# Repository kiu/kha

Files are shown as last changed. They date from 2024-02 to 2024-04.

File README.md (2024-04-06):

# kha

Overengineered Modular RS-485 Multi-Master 19" Subrack Home Control

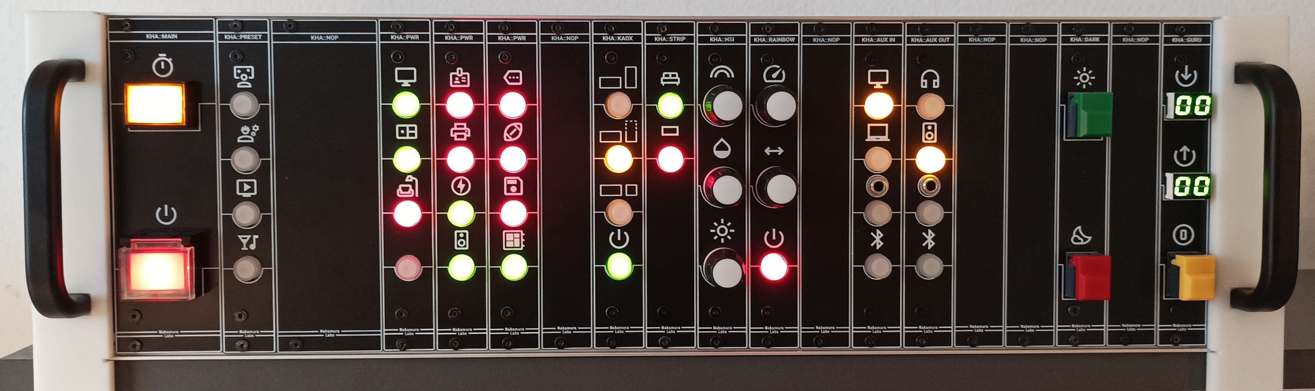
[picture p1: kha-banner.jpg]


## Repository

<sup>Hint: "bgt" is German for [Baugruppenträger](https://de.wikipedia.org/wiki/Baugruppentr%C3%A4ger) translating to subrack assembly</sup>

- [datasheets](datasheets/): Datasheets of used components and rack dimensions / layouts
- [kha-bgt-misc](kha-bgt-misc/): Generic subrack modules
- [kha-bgt-rack](kha-bgt-rack/): 19" rack assembly
- [kha-bgt-subrack](kha-bgt-subrack/): Subrack modules
- [kha-boot.X](kha-boot.X/): Bootloader used by all devices ([main.c](kha-boot.X/main.c))
- [kha-common.X](kha-common.X/): Protocol stack used by all devices ([kha-stack.c](kha-common.X/kha-stack.c) / [kha-stack.h](kha-common.X/kha-stack.h) / [kha-constants.h](kha-common.X/kha-constants.h))
- [kha-nodes](kha-nodes/): Bus nodes
- [superseded](superseded/): Superseded ideas and failed hardware revisions
- [tools](tools/): Helper scripts to e.g. generate userrow data
- [kha-bom-collection.pdf](kha-bom-collection.pdf) / [.ods](kha-bom-collection.ods): Not exactly a Bill-of-Materials rather a collection of most components used
- [kha-protocol.pdf](kha-protocol.pdf) / [.ods](kha-protocol.ods): Protocol stack definitions

## Videos
Two hour deep dive lecture style video on youtube: https://youtu.be/BUSnTUGKZzc

<a href="http://www.youtube.com/watch?feature=player_embedded&v=BUSnTUGKZzc" target="_blank">
	kha on youtube
</a>

## Photos

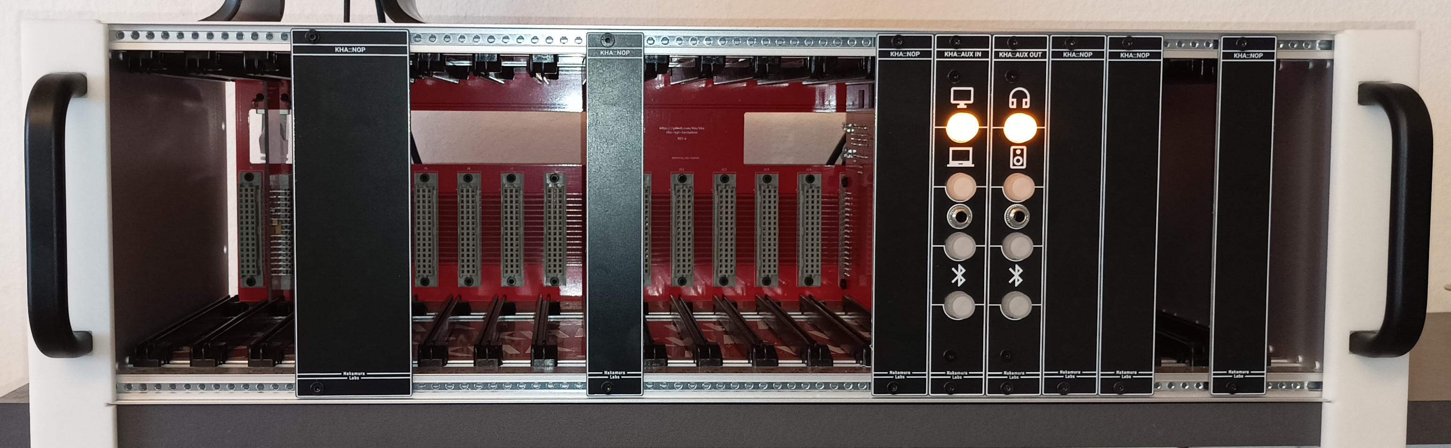
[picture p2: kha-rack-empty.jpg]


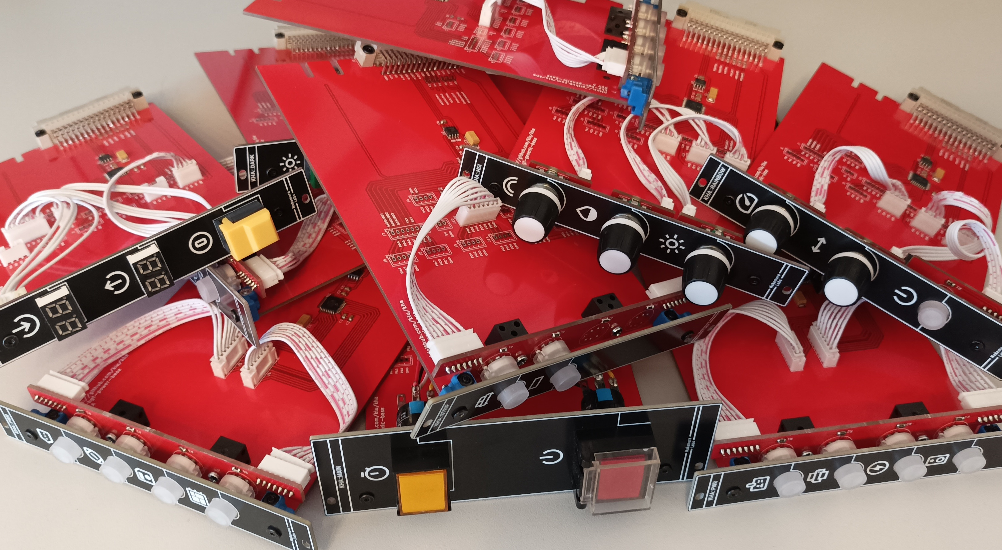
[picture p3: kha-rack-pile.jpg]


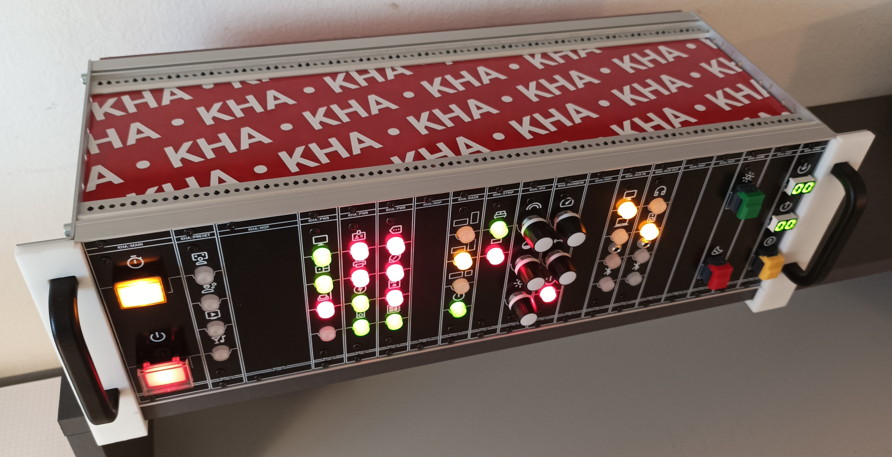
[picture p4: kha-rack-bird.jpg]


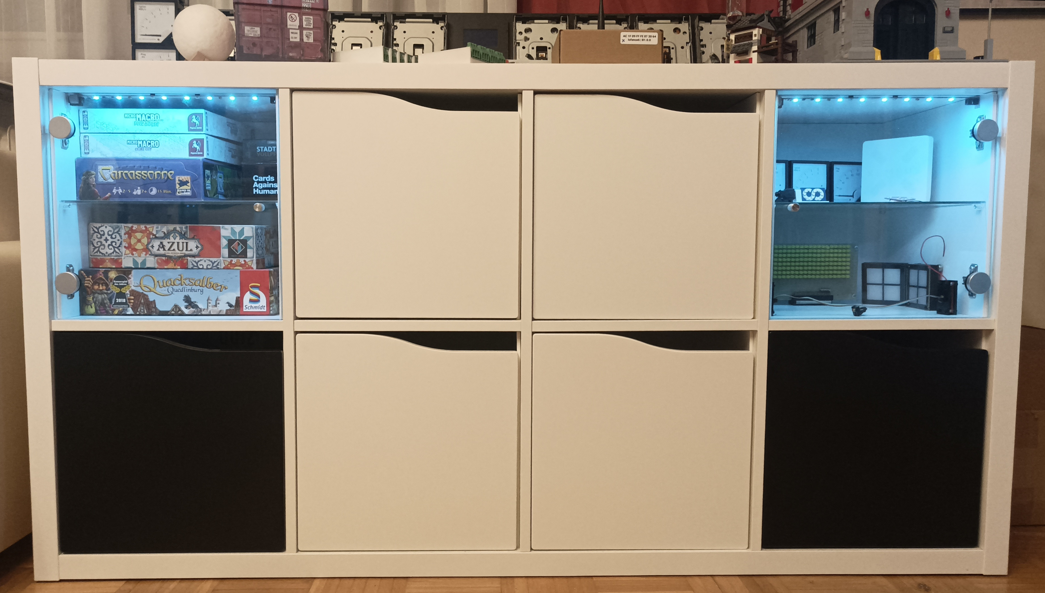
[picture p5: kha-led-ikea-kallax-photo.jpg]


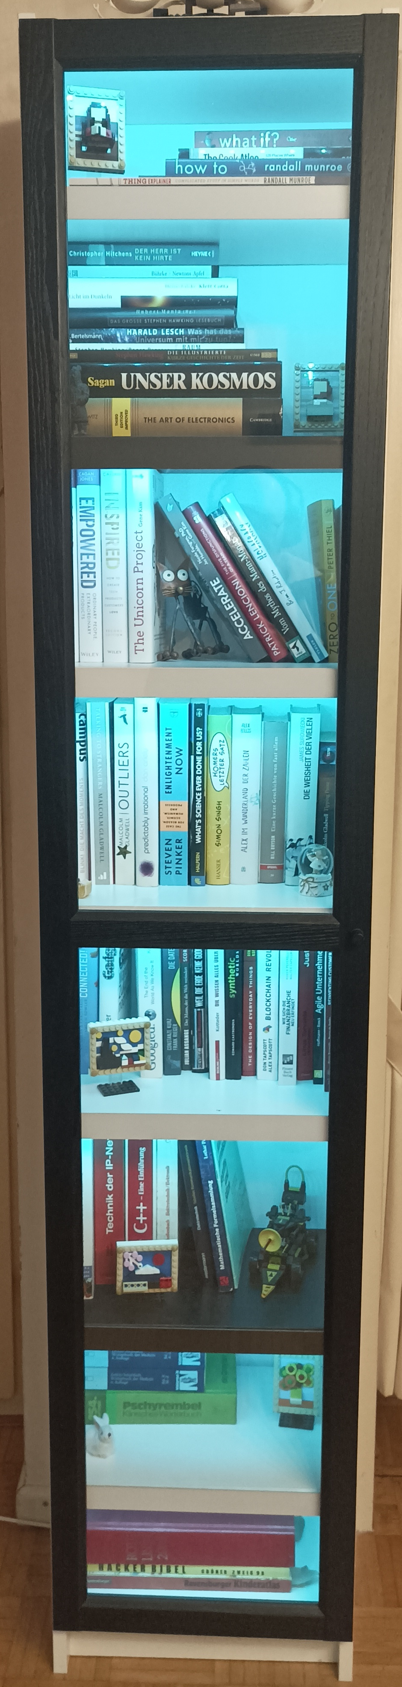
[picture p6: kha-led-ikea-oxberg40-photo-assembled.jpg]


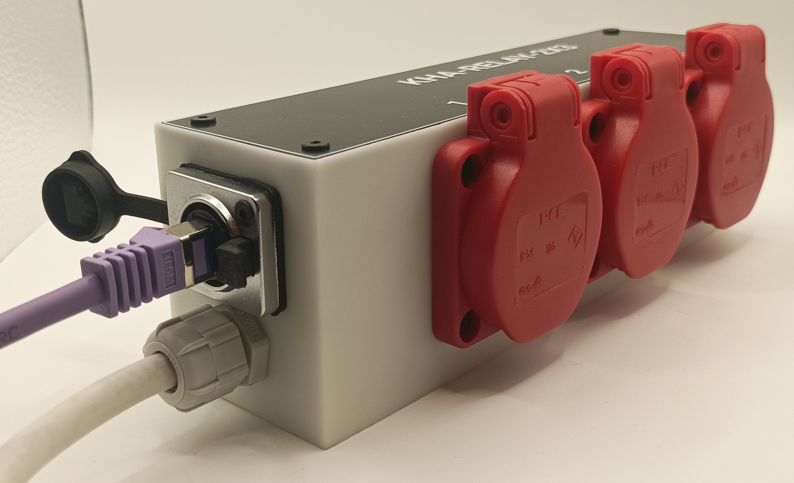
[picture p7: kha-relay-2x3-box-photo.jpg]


## Misc

- All PCBs use [eAVR](https://github.com/kiu/eAVR/) as connector for AVR flashing
- It all started simple with [lightdesk](https://github.com/kiu/lightdesk/)

## Todo

- Node: LED marquee node
- Node: IrDA bridge (bridging the bus through a window)
- Stack: Combine queued TX commands into single burst?
- Stack: Merge similiar queued TX commands into single command?
- Stack: Process TX commands as incoming RX commands?

## Regrets

- Terrible collision detection / avoidance
- Buck converter capacitor generates audible noise

# License

This project is licensed under the Creative Commons Attribution-NonCommercial 3.0 Unported (CC BY-NC 3.0) license.

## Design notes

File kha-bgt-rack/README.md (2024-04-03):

# kha-bgt-rack

19" rack assembly

## Photos



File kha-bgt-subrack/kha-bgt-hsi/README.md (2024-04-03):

# kha-bgt-hsi

Hue Saturation Intensity Module

## Parts

Use [kha-bgt-generic-base](../../kha-bgt-misc/kha-bgt-generic-base/) as base

Use [kha-bgt-generic-rotary-encoder](../../kha-bgt-misc/kha-bgt-generic-rotary-encoder/) for encoders

## Photos

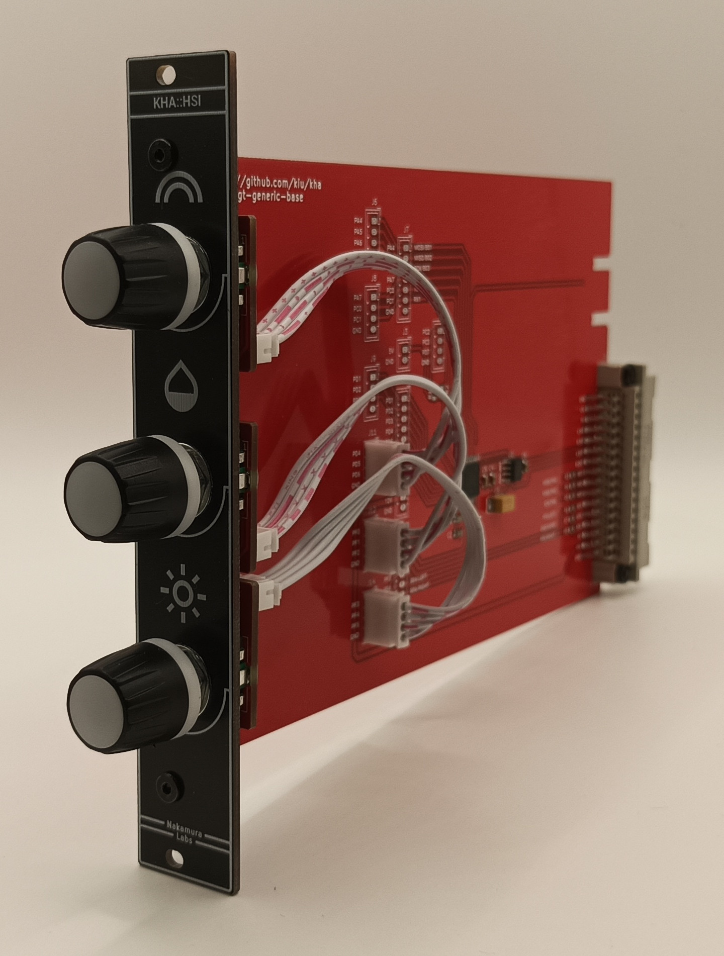
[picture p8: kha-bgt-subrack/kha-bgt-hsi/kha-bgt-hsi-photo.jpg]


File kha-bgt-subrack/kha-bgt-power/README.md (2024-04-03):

# kha-bgt-power

Mains Power Switching Module

## Parts

[kha-bgt-power-base](kha-bgt-power-base/) could be replaced by [kha-bgt-generic-base](../../kha-bgt-misc/kha-bgt-generic-base/)

[kha-bgt-power-sub](kha-bgt-power-sub/) could be replaced by [kha-bgt-generic-4btn-sub](../../kha-bgt-misc/kha-bgt-generic-4btn-sub/)

## Photos

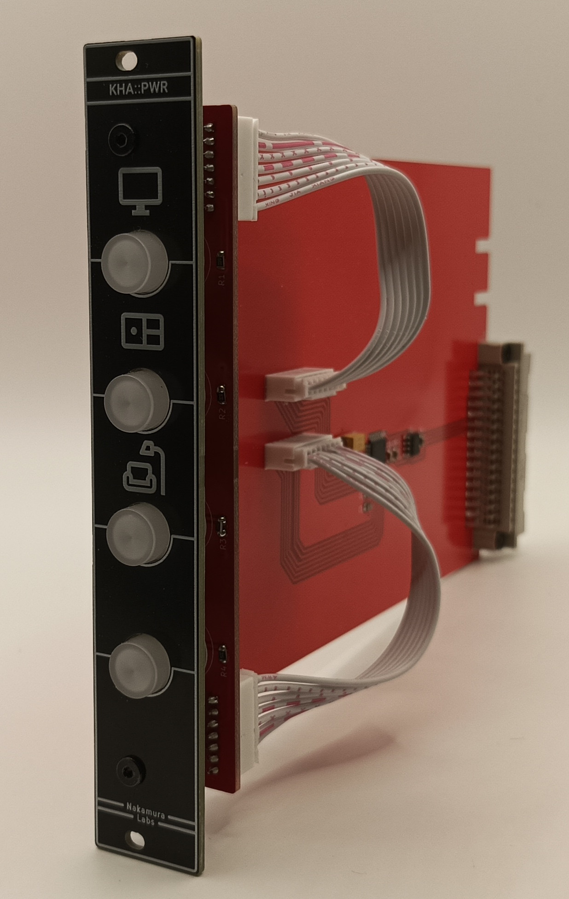
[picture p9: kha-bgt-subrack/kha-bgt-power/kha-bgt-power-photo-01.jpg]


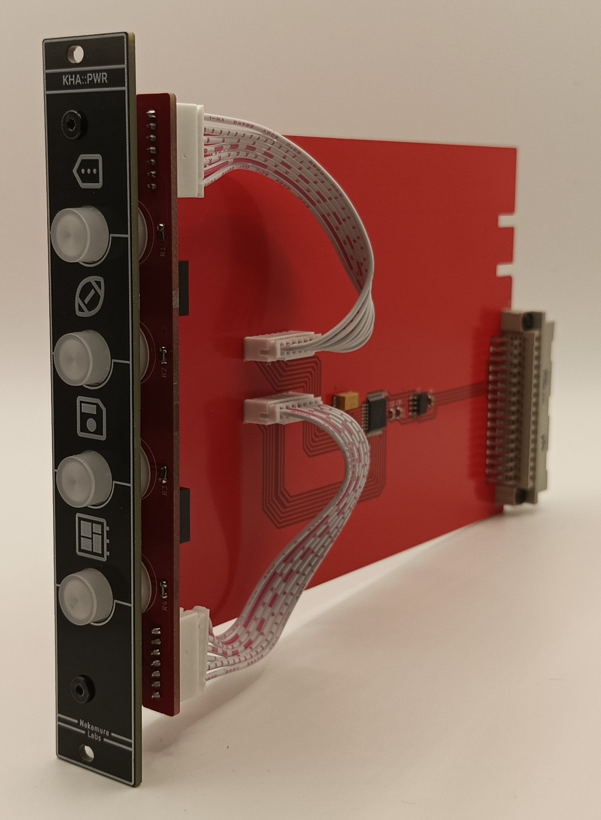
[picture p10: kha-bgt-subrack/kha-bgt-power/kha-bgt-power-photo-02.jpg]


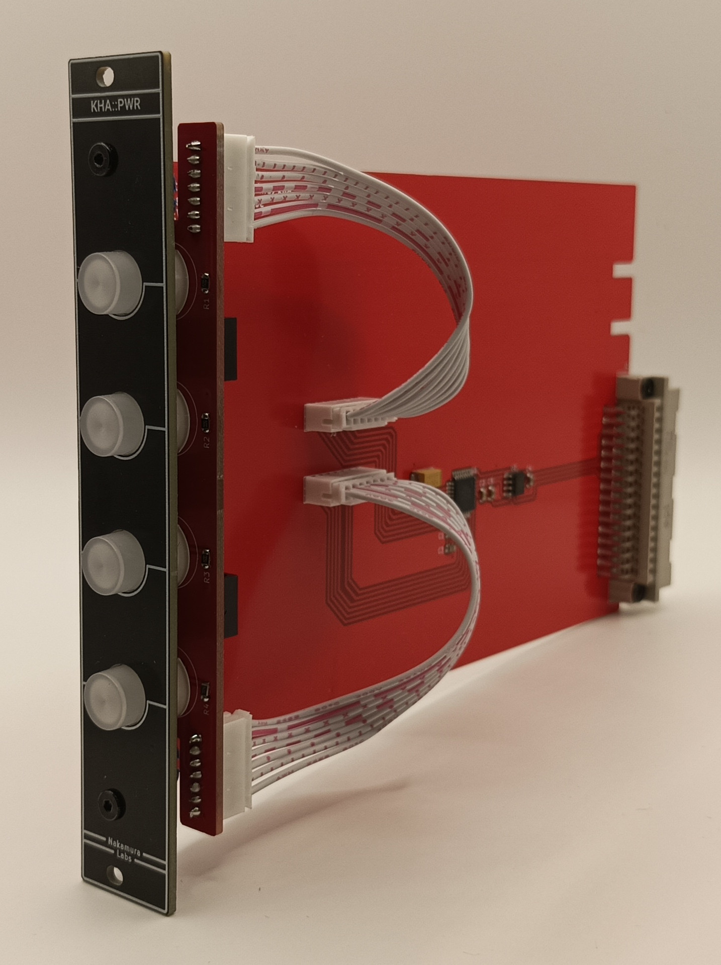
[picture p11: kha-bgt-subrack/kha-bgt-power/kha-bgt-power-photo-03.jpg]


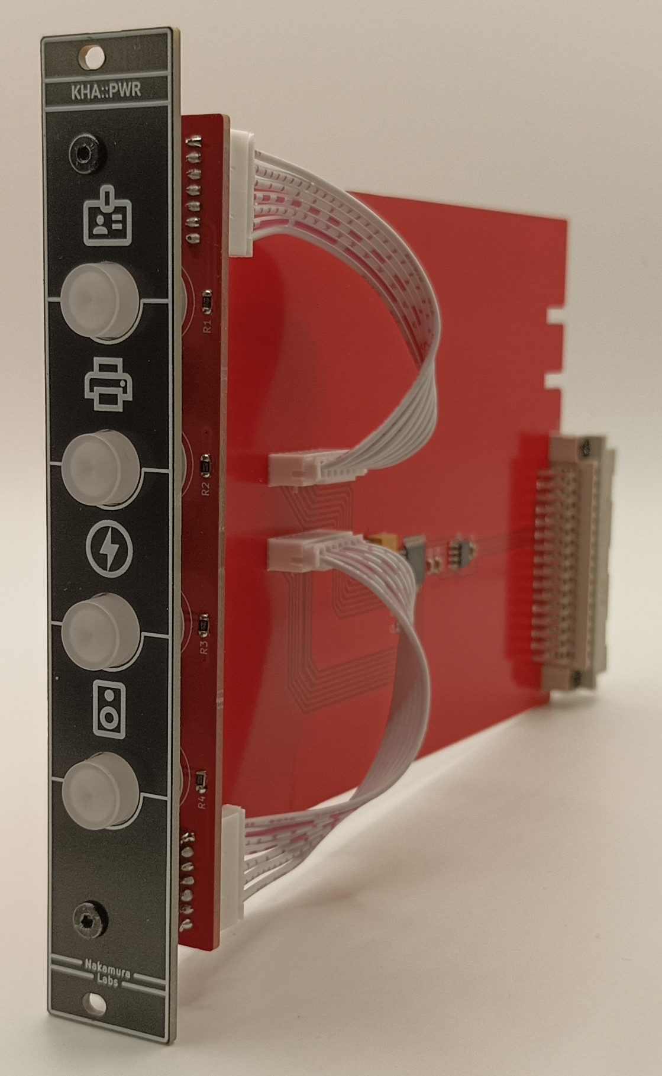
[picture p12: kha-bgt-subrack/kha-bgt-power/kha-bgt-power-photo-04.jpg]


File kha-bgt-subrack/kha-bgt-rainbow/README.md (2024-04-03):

# kha-bgt-rainbow

Rainbow Animation Module

## Parts

Use [kha-bgt-generic-base](../../kha-bgt-misc/kha-bgt-generic-base/) as base

Use [kha-bgt-generic-rotary-encoder](../../kha-bgt-misc/kha-bgt-generic-rotary-encoder/) for encoder

## Photos

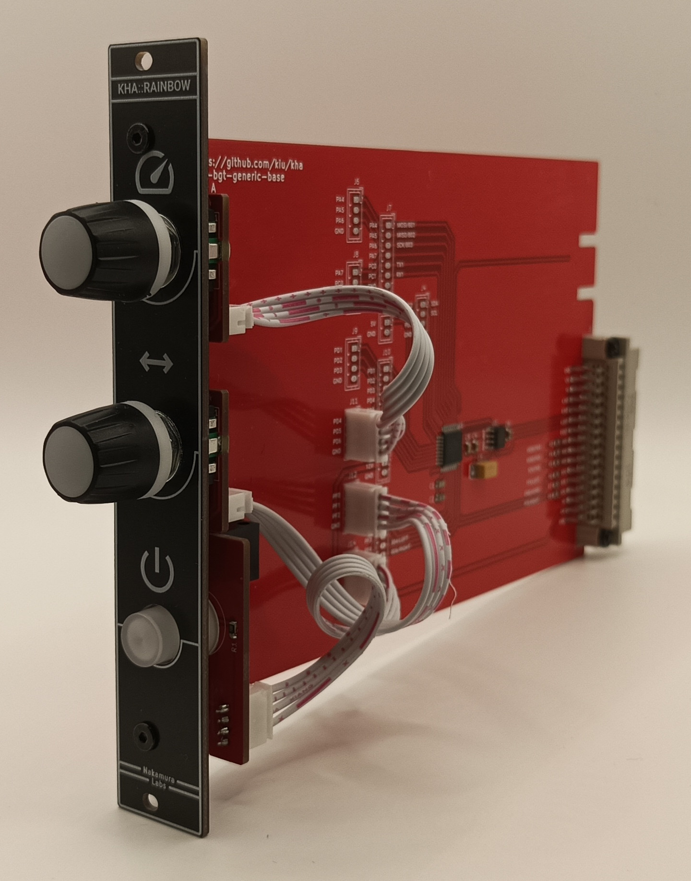
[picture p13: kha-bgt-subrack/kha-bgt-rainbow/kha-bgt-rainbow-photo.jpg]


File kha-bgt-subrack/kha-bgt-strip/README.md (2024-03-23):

# kha-bgt-strip

LED Strip Module

## Parts

Use [kha-bgt-generic-base](../../kha-bgt-misc/kha-bgt-generic-base/) as base

Use [kha-bgt-generic-4btn-sub](../../kha-bgt-misc/kha-bgt-generic-4btn-sub/) as sub

Use [kha-bgt-power](../kha-bgt-power/) as firmware

## Photos

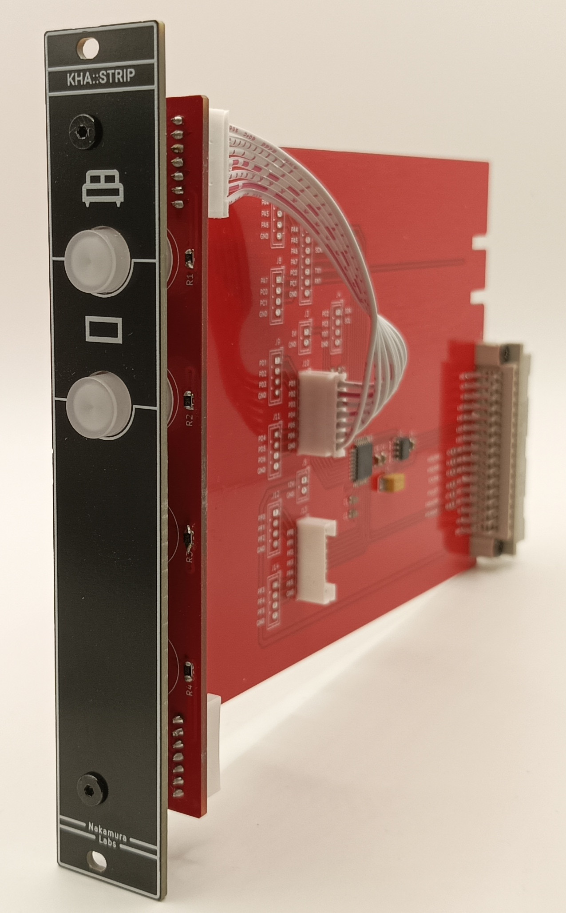
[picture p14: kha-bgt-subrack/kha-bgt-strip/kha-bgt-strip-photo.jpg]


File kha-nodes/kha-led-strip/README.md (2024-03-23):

# kha-led-strip

LED Strip Node

## Photos

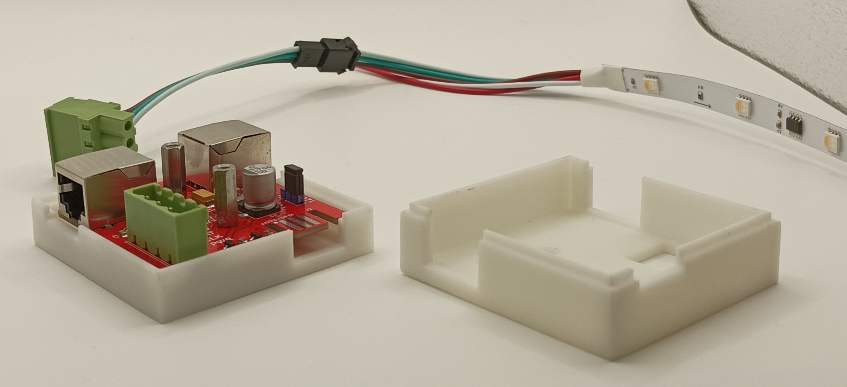
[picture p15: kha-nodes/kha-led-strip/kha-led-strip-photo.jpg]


## Render

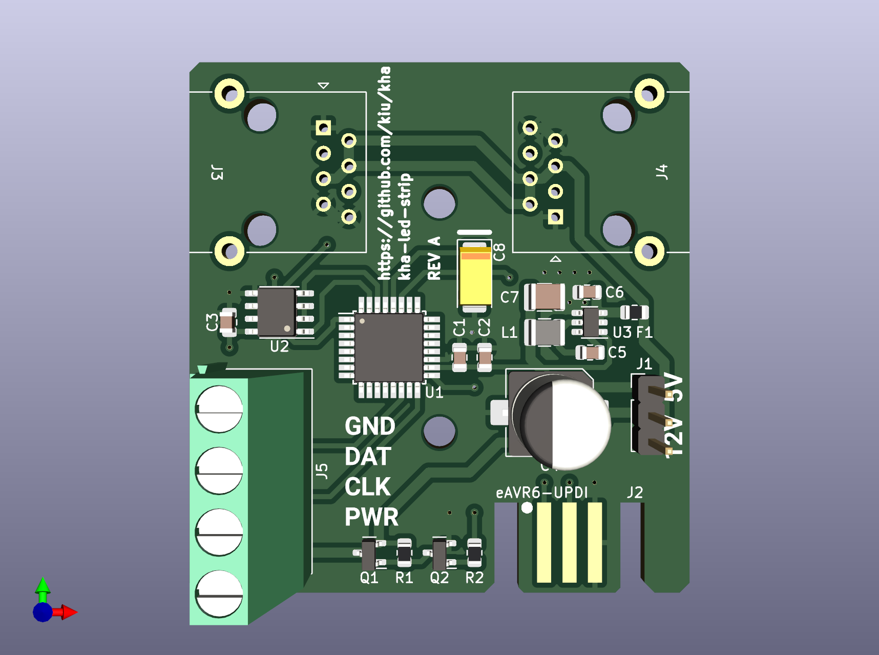
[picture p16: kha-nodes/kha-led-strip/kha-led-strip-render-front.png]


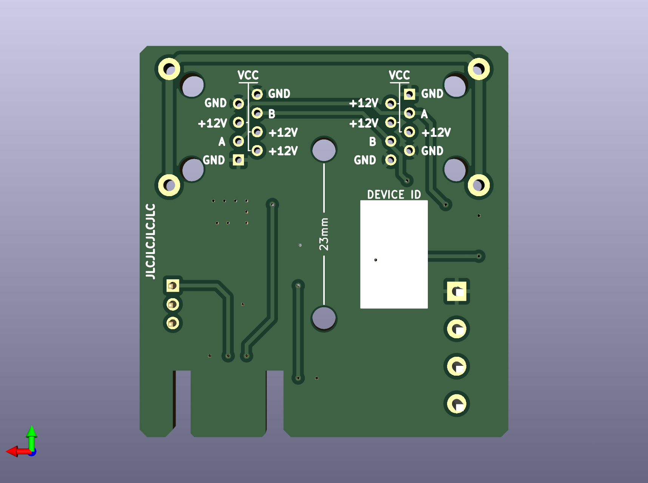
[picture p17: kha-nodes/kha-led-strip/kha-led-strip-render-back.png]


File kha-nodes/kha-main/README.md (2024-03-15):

# kha-main

Remote Shutdown and Poweroff

## Photos

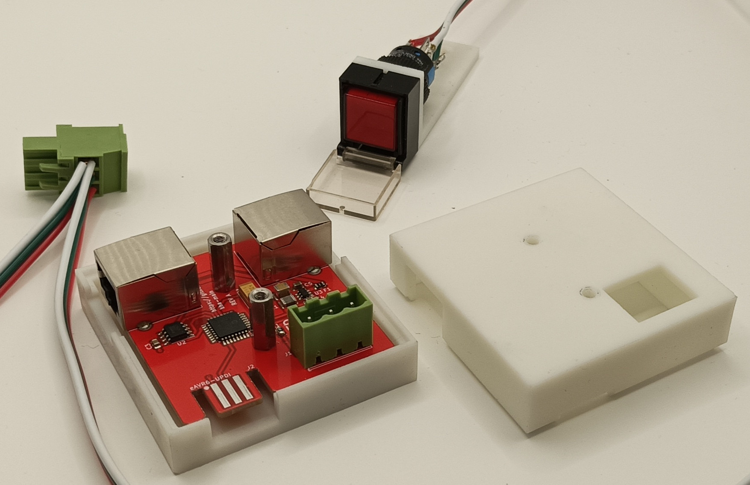
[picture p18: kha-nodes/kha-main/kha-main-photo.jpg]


## Render

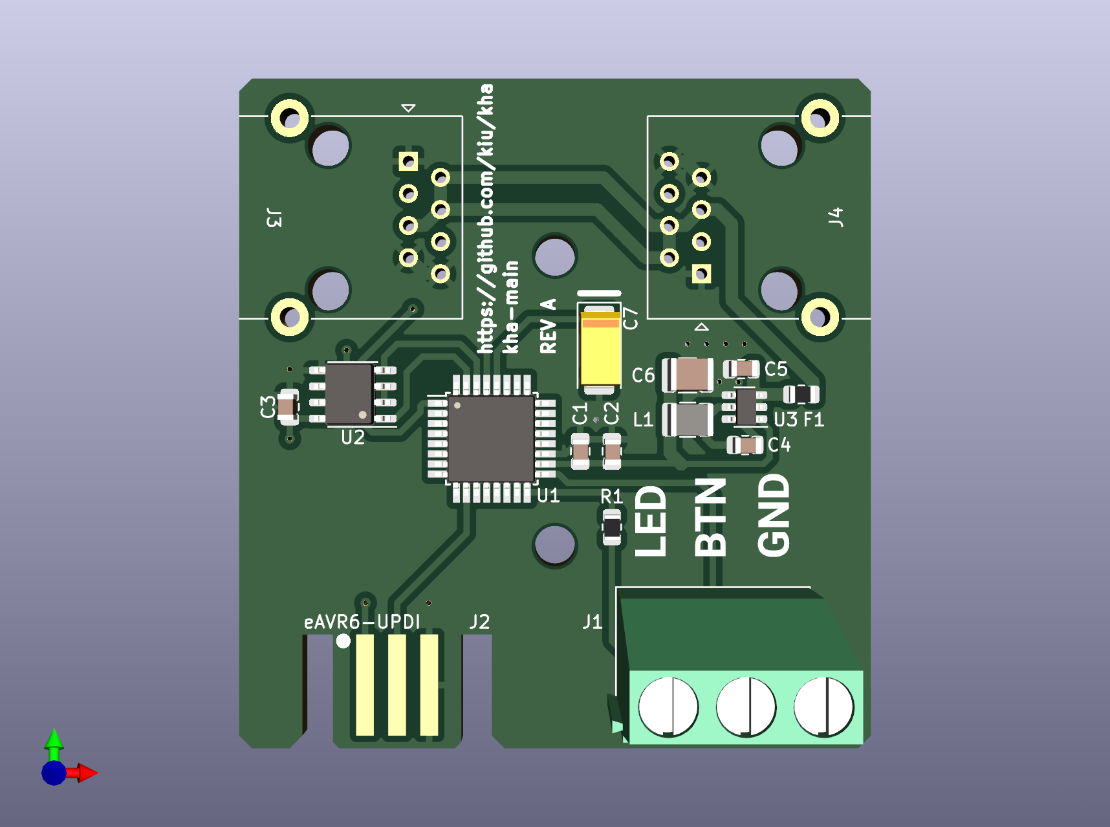
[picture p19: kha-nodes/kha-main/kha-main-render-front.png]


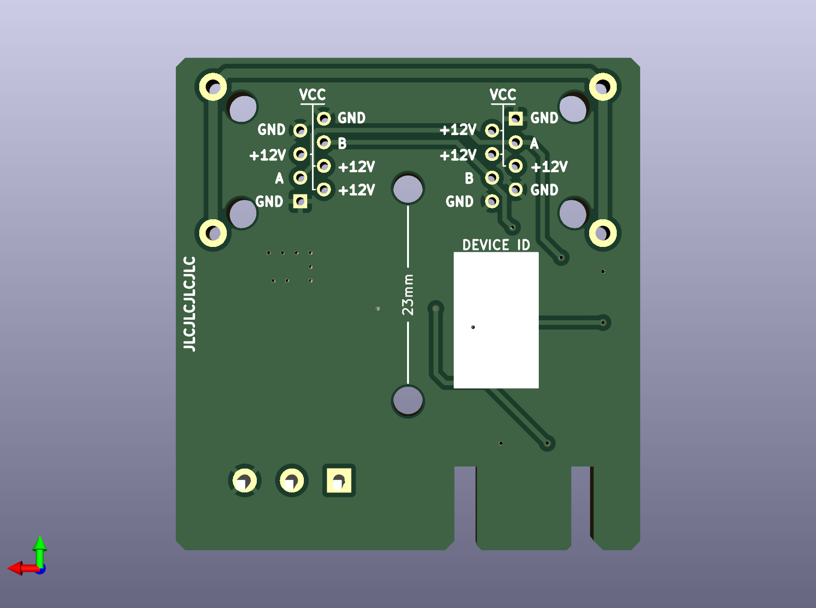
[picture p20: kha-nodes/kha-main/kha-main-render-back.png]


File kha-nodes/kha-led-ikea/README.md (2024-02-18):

# kha-led-ikea-lighting

IKEA LED Panels and Termination

## Photos

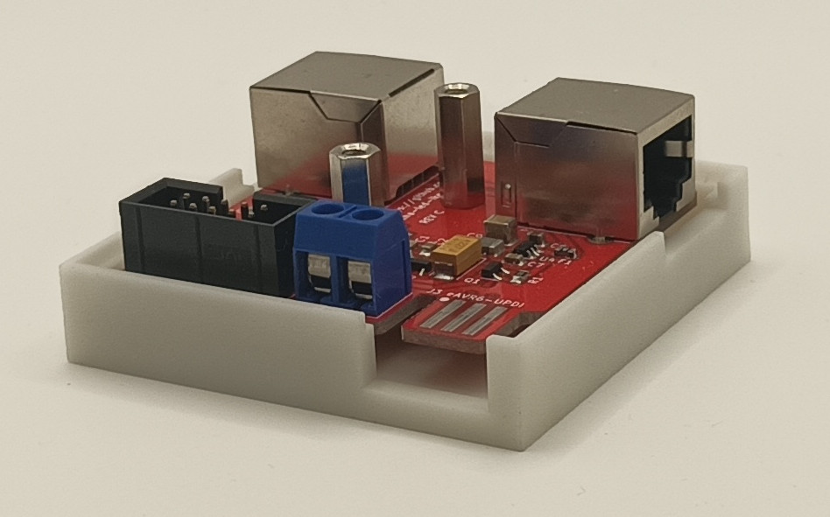
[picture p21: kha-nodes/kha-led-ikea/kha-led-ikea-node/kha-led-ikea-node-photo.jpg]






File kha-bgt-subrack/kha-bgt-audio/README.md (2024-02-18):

# kha-bgt-audio

Audio Switching Module

- 2x TRS (back)
- 1x TRS (front)
- 1x Bluetooth

## Photos

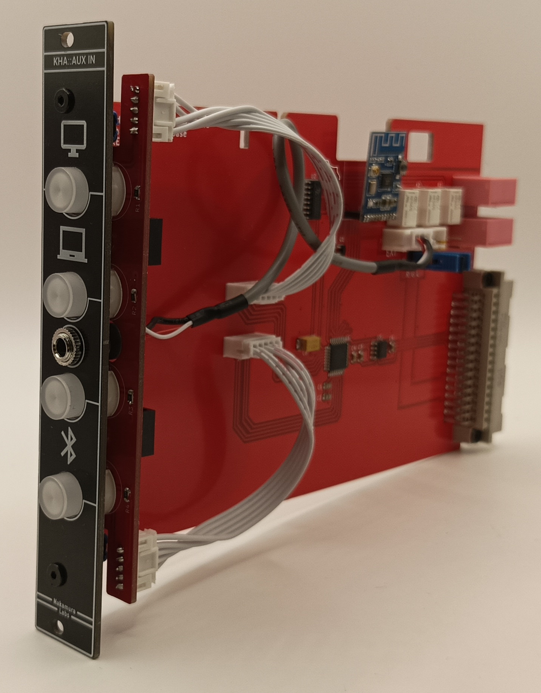
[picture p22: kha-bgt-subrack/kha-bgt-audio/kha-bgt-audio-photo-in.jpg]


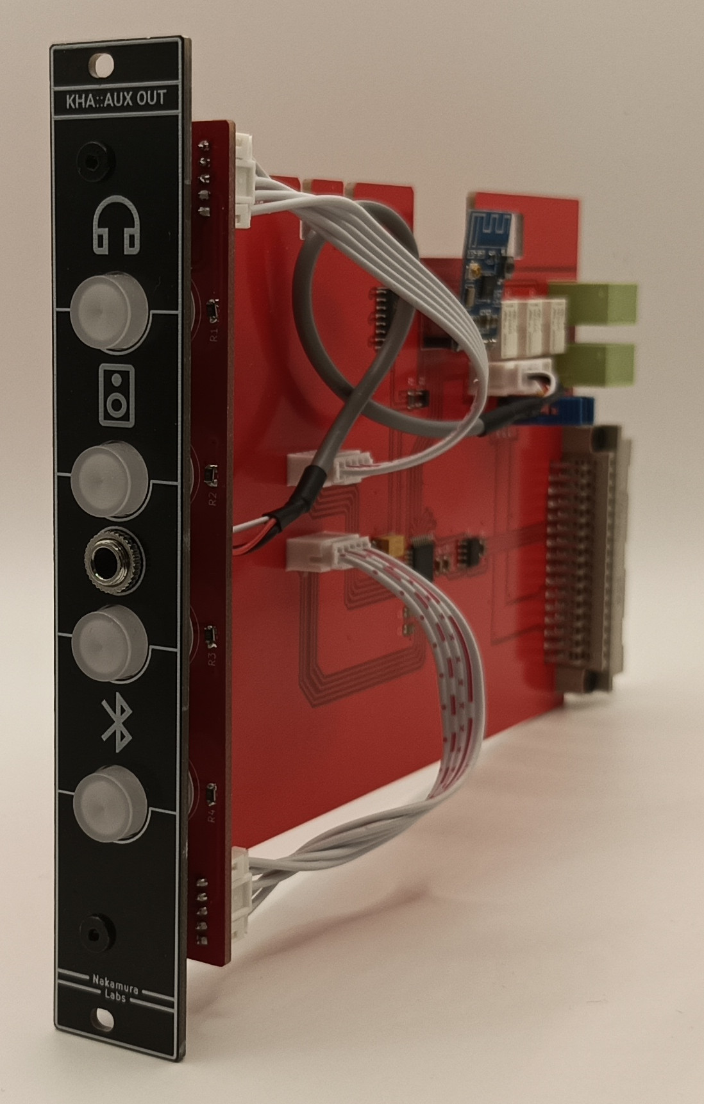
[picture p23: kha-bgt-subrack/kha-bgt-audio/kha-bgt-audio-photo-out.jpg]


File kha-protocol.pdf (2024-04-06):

ADDR

Seite 1

Category | ADDR | Description
Broadcast | FF | Broadcast to All Devices
Broadcast Group | FE | Broadcast to Devices in Group
Broadcast Group | FD | Broadcast to Devices in Group
Broadcast Group | FC | Broadcast to Devices in Group
Broadcast Group | FB | Broadcast to Devices in Group
Broadcast Group | FA | Broadcast to Devices in Group
Broadcast Group | F9 | Broadcast to Devices in Group
Broadcast Group | F8 | Broadcast to Devices in Group
Broadcast Group | F7 | Broadcast to Devices in Group
Broadcast Group | F6 | Broadcast to Devices in Group
Broadcast Group | F5 | Broadcast to Devices in Group
Broadcast Group | F4 | Broadcast to Devices in Group
Broadcast Group | F3 | Broadcast to Devices in Group
Broadcast Group | F2 | Broadcast to Devices in Group
Broadcast Group | F1 | Broadcast to Devices in Group
Broadcast Group Default | F0 | Default broadcast group if device has not been configured
Unicast | EF | Unicast to Device
Unicast | … | Unicast to Device
Unicast | 02 | Unicast to Device
Unicast Default | 01 | Default unicast address if device has not been configured
None | 00 | No recipient

BOARD

Seite 2

Board | Type
All | FF
Kha-bgt-rainbow | A8
Kha-bgt-preset | A7
Kha-bgt-main | A6
Kha-bgt-kaox | A5
Kha-bgt-hsi | A4
Kha-bgt-guru | A3
Kha-bgt-dark | A2
kha-bgt-power | A1
kha-bgt-audio | A0
Kha-led-strip | 07
Kha-remote | 06
Kha-main | 05
kha-relay-2x3-node | 04
kha-gateway-usb | 03
Kha-led-ikea-node | 02
Board Default | 01
None | 00

CMD

Seite 3

Category | CMD | Opt Len Payload | Type | Description
Management | FF | 0 / 2 | - or <1: board type> <1: board rev> | Command | Reboot Device, optionally only matching specific hardware
Management | FE | 0 | - | Reply | Bootloader: Command error
Management | FD | 2 | <1: board type> <1: board rev> | Command | Bootloader: Do not exit
Management | FC | 2 | <1: board type> <1: board rev> | Command | Bootloader: Wipe FLASH
Management | FB | 2 | <1: board type> <1: board rev> | Command | Bootloader: Wipe EEPROM
Management | FA | 67 | <1: board type> <1: board rev> <1: part 0-7> <64: data> | Command | Bootloader: Firmware data
Management | F9 | 3 | <1: board type> <1: board rev> <1: page> | Command | Bootloader: Firmware write
Reserved | F8 | Reserved Reserved | Reserved | Reserved
Reserved | F7 | Reserved Reserved | Reserved | Reserved
Reserved | F6 | Reserved Reserved | Reserved | Reserved
Reserved | F5 | Reserved Reserved | Reserved | Reserved
Reserved | F4 | Reserved Reserved | Reserved | Reserved
Reserved | F3 | Reserved Reserved | Reserved | Reserved
Reserved | F2 | Reserved Reserved | Reserved | Reserved
Management | F1 | 0 | - | Command | TX Enable
Management | F0 | 0 | - | Command | TX Disable
Reserved | EF | Reserved Reserved | Reserved | Reserved
Reserved | EE | Reserved Reserved | Reserved | Reserved
Device | ED | 1 | <1: preset> | Command | Preset
Device | EC | 0 | - | Command | UI Enable
Device | EB | 0 | - | Command | UI Disable
Device | EA | 0 | - | Command | Debug Enable
Device | E9 | 0 | - | Command | Debug Disable
Device | E8 | 1-MAX | <data> | Broadcast | Debug Message
Device | E7 | 0 | - | Command | Stats Clear
Device | E6 | 9 | <9: stats> | Reply | Stats Response
Device | E5 | 0 | - | Command | Stats Request
Device | E4 | 0 | - | Reply | Pong
Device | E3 | 0 | - | Command | Ping
Device | E2 | 20 | <1: board type> <1: board rev> <1: device group> <1: 0=boot, 1=app> <4: boot version> <4: boot crc> <4: app version> <4:app crc> | Broadcast | Up
Device | E1 | 20 | <1: board type> <1: board rev> <1: device group> <1: 0=boot, 1=app> <4: boot version> <4: boot crc> <4: app version> <4:app crc> | Reply | Ident Response
Device | E0 | 0 | - | Command | Ident Request
Register | DF | 0 | - | Command | Wipe configuration in memory
Register | DE | 0 | - | Command | Store configuration to EEPROM
Register | DD | 0 | - | Command | Load configuration from EEPROM
Reserved | DC | Reserved Reserved | Reserved | Reserved
Reserved | DB | Reserved Reserved | Reserved | Reserved
Reserved | DA | Reserved Reserved | Reserved | Reserved
Reserved | D9 | Reserved Reserved | Reserved | Reserved
Register | E8 | 1 | <1: addr> | Reply | Write Fail
Register | D7 | 1 | <1: addr> | Reply | Write Success
Register | D6 | 2-MAX | <1: addr> <data> | Command
Register | D5 | 2-MAX | <1: addr> <data> | Command | Write <data> bytes to address <addr>
Reserved | D4 | Reserved Reserved | Reserved | Reserved
Reserved | D3 | Reserved Reserved | Reserved | Reserved
Reserved | D2 | Reserved Reserved | Reserved | Reserved
Register | D1 | 1-MAX | | Reply
Register | D0 | 2 | <1: addr> <1: len> | Command
Reserved | CF | Reserved Reserved | Reserved | Reserved
Reserved | CE | Reserved Reserved | Reserved | Reserved
Reserved | CD | Reserved Reserved | Reserved | Reserved
Reserved | CC | Reserved Reserved | Reserved | Reserved
Reserved | CB | Reserved Reserved | Reserved | Reserved
Reserved | CA | Reserved Reserved | Reserved | Reserved
Reserved | C9 | Reserved Reserved | Reserved | Reserved
Reserved | C8 | Reserved Reserved | Reserved | Reserved
Reserved | C7 | Reserved Reserved | Reserved | Reserved

Write <data> bytes to address <addr>, don’t reply

<1:addr> <data, empty if failed> | Read Reply <data> bytes from address <addr> or empty if failed Read <len> bytes from address <addr>

CMD

Seite 4

Reserved | C6 | Reserved Reserved | Reserved | Reserved
Reserved | C5 | Reserved Reserved | Reserved | Reserved
Reserved | C4 | Reserved Reserved | Reserved | Reserved
Reserved | C3 | Reserved Reserved | Reserved | Reserved
Sensor | C2 | 1 | <1: 0.5%> | Broadcast
Sensor | C1 | 1 | <1: uint 0.5 degree> | Broadcast
Sensor | C0 | 8 | <1: year - 2000> <1: month> <1: day> <1: hour> <1: minute> <1: second> <1: sunday = 1> <1: calender week> | Broadcast
Reserved | BF | Reserved Reserved | Reserved | Reserved
Reserved | BE | Reserved Reserved | Reserved | Reserved
Reserved | BD | Reserved Reserved | Reserved | Reserved
Reserved | BC | Reserved Reserved | Reserved | Reserved
Reserved | BB | Reserved Reserved | Reserved | Reserved
Reserved | BA | Reserved Reserved | Reserved | Reserved
Reserved | B9 | Reserved Reserved | Reserved | Reserved
Reserved | B8 | Reserved Reserved | Reserved | Reserved
Reserved | B7 | Reserved Reserved | Reserved | Reserved
Reserved | B6 | Reserved Reserved | Reserved | Reserved
Reserved | B5 | Reserved Reserved | Reserved | Reserved
Reserved | B4 | Reserved Reserved | Reserved | Reserved
Reserved | B3 | Reserved Reserved | Reserved | Reserved
Reserved | B2 | Reserved Reserved | Reserved | Reserved
App | B1 | 3 | | Broadcast | LED Animation
App | B0 | 3 | <1: hue> <1: saturation> <1: intensity> | Broadcast | LED HSI
Reserved | AF | Reserved Reserved | Reserved | Reserved
Reserved | AE | Reserved Reserved | Reserved | Reserved
Reserved | AD | Reserved Reserved | Reserved | Reserved
Reserved | AC | Reserved Reserved | Reserved | Reserved
Reserved | AB | Reserved Reserved | Reserved | Reserved
Reserved | AA | Reserved Reserved | Reserved | Reserved
Reserved | A9 | Reserved Reserved | Reserved | Reserved
Reserved | A8 | Reserved Reserved | Reserved | Reserved
Reserved | A7 | Reserved Reserved | Reserved | Reserved
Reserved | A6 | Reserved Reserved | Reserved | Reserved
Reserved | A5 | Reserved Reserved | Reserved | Reserved
Reserved | A4 | Reserved Reserved | Reserved | Reserved
Reserved | A3 | Reserved Reserved | Reserved | Reserved
Reserved | A2 | Reserved Reserved | Reserved | Reserved
Reserved | A1 | Reserved Reserved | Reserved | Reserved
Reserved | A0 | Reserved Reserved | Reserved | Reserved
Vendor | 9F | ? | ? | ? | Vendor Specific
Vendor | … | ? | ? | ? | Vendor Specific
Vendor | 01 | ? | ? | ? | Vendor Specific
System | 00 | 0 | - | Command | NOP

Humidity Broadcast [not implemented yet] Temperature Broadcast [not implemented yet] Time Broadcast [not implemented yet]

<1: speed> <1: width> <1: enabled>

REGISTER

Seite 5

Module | Type | ADDR | Function | Values
Kha-bgt-audio | Device | 00 | Select audio source/destination | 0=AUXA, 1=AUXB, 2=AUXC, 3=AUXD
Kha-bgt-audio | Device | 01 | Bluetooth connection trigger | 1=trigger once
Kha-bgt-audio | Device | 02 | Select power-on audio source/destination | 0=AUXA, 1=AUXB, 2=AUXC, 3=AUXD
Kha-bgt-audio | Preset | 03 | Preset 0 enabled | 0 = Off, 1= On
Kha-bgt-audio | Preset | 04 | Preset 0 mode | 0=AUXA, 1=AUXB, 2=AUXC, 3=AUXD
Kha-bgt-audio | Preset | 05 | Preset 1 enabled | 0 = Off, 1= On
Kha-bgt-audio | Preset | 06 | Preset 1 mode | 0=AUXA, 1=AUXB, 2=AUXC, 3=AUXD
Kha-bgt-audio | Preset | 07 | Preset 2 enabled | 0 = Off, 1= On
Kha-bgt-audio | Preset | 08 | Preset 2 mode | 0=AUXA, 1=AUXB, 2=AUXC, 3=AUXD
Kha-bgt-audio | Preset | 09 | Preset 3 enabled | 0 = Off, 1= On
Kha-bgt-audio | Preset | 0A | Preset 3 mode | 0=AUXA, 1=AUXB, 2=AUXC, 3=AUXD
Kha-bgt-audio | Preset | 0B | Preset 4 enabled | 0 = Off, 1= On
Kha-bgt-audio | Preset | 0C | Preset 4 mode | 0=AUXA, 1=AUXB, 2=AUXC, 3=AUXD
Kha-bgt-audio | Preset | 0D | Preset 5 enabled | 0 = Off, 1= On
Kha-bgt-audio | Preset | 0E | Preset 5 mode | 0=AUXA, 1=AUXB, 2=AUXC, 3=AUXD
Kha-bgt-audio | Preset | 0F | Preset 6 enabled | 0 = Off, 1= On
Kha-bgt-audio | Preset | 10 | Preset 6 mode | 0=AUXA, 1=AUXB, 2=AUXC, 3=AUXD
Kha-bgt-audio | Preset | 11 | Preset 7 enabled | 0 = Off, 1= On
Kha-bgt-audio | Preset | 12 | Preset 7 mode | 0=AUXA, 1=AUXB, 2=AUXC, 3=AUXD
Kha-bgt-audio | Preset | 13 | Preset 8 enabled | 0 = Off, 1= On
Kha-bgt-audio | Preset | 14 | Preset 8 mode | 0=AUXA, 1=AUXB, 2=AUXC, 3=AUXD
Kha-bgt-audio | Preset | 15 | Preset 9 enabled | 0 = Off, 1= On
Kha-bgt-audio | Preset | 16 | Preset 9 mode | 0=AUXA, 1=AUXB, 2=AUXC, 3=AUXD
Kha-bgt-audio | Preset | 17 | Preset A enabled | 0 = Off, 1= On
Kha-bgt-audio | Preset | 18 | Preset A mode | 0=AUXA, 1=AUXB, 2=AUXC, 3=AUXD
Kha-bgt-audio | Preset | 19 | Preset B enabled | 0 = Off, 1= On
Kha-bgt-audio | Preset | 1A | Preset B mode | 0=AUXA, 1=AUXB, 2=AUXC, 3=AUXD
Kha-bgt-audio | Preset | 1B | Preset C enabled | 0 = Off, 1= On
Kha-bgt-audio | Preset | 1C | Preset C mode | 0=AUXA, 1=AUXB, 2=AUXC, 3=AUXD
Kha-bgt-audio | Preset | 1D | Preset D enabled | 0 = Off, 1= On
Kha-bgt-audio | Preset | 1E | Preset D mode | 0=AUXA, 1=AUXB, 2=AUXC, 3=AUXD
Kha-bgt-audio | Preset | 1F | Preset E enabled | 0 = Off, 1= On
Kha-bgt-audio | Preset | 20 | Preset E mode | 0=AUXA, 1=AUXB, 2=AUXC, 3=AUXD
Kha-bgt-audio | Preset | 21 | Preset F enabled | 0 = Off, 1= On

REGISTER

Seite

6

Kha-bgt-audio | Preset | 22 | Preset F mode | 0=AUXA, 1=AUXB, 2=AUXC, 3=AUXD
Kha-bgt-dark | Preset | 00 | Preset 0 enabled | 0 = Off, 1= On
Kha-bgt-dark | Preset | 01 | Preset 0 mode | 0=Send Off, 1=Send On
Kha-bgt-dark | Preset | 02 | Preset 1 enabled | 0 = Off, 1= On
Kha-bgt-dark | Preset | 03 | Preset 1 mode | 0=Send Off, 1=Send On
Kha-bgt-dark | Preset | 04 | Preset 2 enabled | 0 = Off, 1= On
Kha-bgt-dark | Preset | 05 | Preset 2 mode | 0=Send Off, 1=Send On
Kha-bgt-dark | Preset | 06 | Preset 3 enabled | 0 = Off, 1= On
Kha-bgt-dark | Preset | 07 | Preset 3 mode | 0=Send Off, 1=Send On
Kha-bgt-dark | Preset | 08 | Preset 4 enabled | 0 = Off, 1= On
Kha-bgt-dark | Preset | 09 | Preset 4 mode | 0=Send Off, 1=Send On
Kha-bgt-dark | Preset | 0A | Preset 5 enabled | 0 = Off, 1= On
Kha-bgt-dark | Preset | 0B | Preset 5 mode | 0=Send Off, 1=Send On
Kha-bgt-dark | Preset | 0C | Preset 6 enabled | 0 = Off, 1= On
Kha-bgt-dark | Preset | 0D | Preset 6 mode | 0=Send Off, 1=Send On
Kha-bgt-dark | Preset | 0E | Preset 7 enabled | 0 = Off, 1= On
Kha-bgt-dark | Preset | 0F | Preset 7 mode | 0=Send Off, 1=Send On
Kha-bgt-dark | Preset | 10 | Preset 8 enabled | 0 = Off, 1= On
Kha-bgt-dark | Preset | 11 | Preset 8 mode | 0=Send Off, 1=Send On
Kha-bgt-dark | Preset | 12 | Preset 9 enabled | 0 = Off, 1= On
Kha-bgt-dark | Preset | 13 | Preset 9 mode | 0=Send Off, 1=Send On
Kha-bgt-dark | Preset | 14 | Preset A enabled | 0 = Off, 1= On
Kha-bgt-dark | Preset | 15 | Preset A mode | 0=Send Off, 1=Send On
Kha-bgt-dark | Preset | 16 | Preset B enabled | 0 = Off, 1= On
Kha-bgt-dark | Preset | 17 | Preset B mode | 0=Send Off, 1=Send On
Kha-bgt-dark | Preset | 18 | Preset C enabled | 0 = Off, 1= On
Kha-bgt-dark | Preset | 19 | Preset C mode | 0=Send Off, 1=Send On
Kha-bgt-dark | Preset | 1A | Preset D enabled | 0 = Off, 1= On
Kha-bgt-dark | Preset | 1B | Preset D mode | 0=Send Off, 1=Send On
Kha-bgt-dark | Preset | 1C | Preset E enabled | 0 = Off, 1= On
Kha-bgt-dark | Preset | 1D | Preset E mode | 0=Send Off, 1=Send On
Kha-bgt-dark | Preset | 1E | Preset F enabled | 0 = Off, 1= On
Kha-bgt-dark | Preset | 1F | Preset F mode | 0=Send Off, 1=Send On
Kha-bgt-guru | Device | 00 | Send to device id | 0x00-0xFF
Kha-bgt-guru | Device | 01 | Stats request interval | 0x01-0xFF (min) | 0x00 = Off

REGISTER

Seite

7

Kha-bgt-hsi | Device | 00 | Send to device id | 0x00-0xFF
Kha-bgt-hsi | Preset | 01 | Preset 0 enabled | 0 = Off, 1= On
Kha-bgt-hsi | Preset | 02 | Preset 0 hue | 0x00-0xFF
Kha-bgt-hsi | Preset | 03 | Preset 0 saturation | 0x00-0xFF
Kha-bgt-hsi | Preset | 04 | Preset 0 intensity | 0x00-0xFF
Kha-bgt-hsi | Preset | 05 | Preset 1 enabled | 0 = Off, 1= On
Kha-bgt-hsi | Preset | 06 | Preset 1 hue | 0x00-0xFF
Kha-bgt-hsi | Preset | 07 | Preset 1 saturation | 0x00-0xFF
Kha-bgt-hsi | Preset | 08 | Preset 1 intensity | 0x00-0xFF
Kha-bgt-hsi | Preset | 09 | Preset 2 enabled | 0 = Off, 1= On
Kha-bgt-hsi | Preset | 0A | Preset 2 hue | 0x00-0xFF
Kha-bgt-hsi | Preset | 0B | Preset 2 saturation | 0x00-0xFF
Kha-bgt-hsi | Preset | 0C | Preset 2 intensity | 0x00-0xFF
Kha-bgt-hsi | Preset | 0D | Preset 3 enabled | 0 = Off, 1= On
Kha-bgt-hsi | Preset | 0E | Preset 3 hue | 0x00-0xFF
Kha-bgt-hsi | Preset | 0F | Preset 3 saturation | 0x00-0xFF
Kha-bgt-hsi | Preset | 10 | Preset 3 intensity | 0x00-0xFF
Kha-bgt-hsi | Preset | 11 | Preset 4 enabled | 0 = Off, 1= On
Kha-bgt-hsi | Preset | 12 | Preset 4 hue | 0x00-0xFF
Kha-bgt-hsi | Preset | 13 | Preset 4 saturation | 0x00-0xFF
Kha-bgt-hsi | Preset | 14 | Preset 4 intensity | 0x00-0xFF
Kha-bgt-hsi | Preset | 15 | Preset 5 enabled | 0 = Off, 1= On
Kha-bgt-hsi | Preset | 16 | Preset 5 hue | 0x00-0xFF
Kha-bgt-hsi | Preset | 17 | Preset 5 saturation | 0x00-0xFF
Kha-bgt-hsi | Preset | 18 | Preset 5 intensity | 0x00-0xFF
Kha-bgt-hsi | Preset | 19 | Preset 6 enabled | 0 = Off, 1= On
Kha-bgt-hsi | Preset | 1A | Preset 6 hue | 0x00-0xFF
Kha-bgt-hsi | Preset | 1B | Preset 6 saturation | 0x00-0xFF
Kha-bgt-hsi | Preset | 1C | Preset 6 intensity | 0x00-0xFF
Kha-bgt-hsi | Preset | 1D | Preset 7 enabled | 0 = Off, 1= On
Kha-bgt-hsi | Preset | 1E | Preset 7 hue | 0x00-0xFF
Kha-bgt-hsi | Preset | 1F | Preset 7 saturation | 0x00-0xFF
Kha-bgt-hsi | Preset | 20 | Preset 7 intensity | 0x00-0xFF
Kha-bgt-hsi | Preset | 00 | Preset 8 enabled | 0 = Off, 1= On
Kha-bgt-hsi | Preset | 00 | Preset 8 hue | 0x00-0xFF

REGISTER

Seite

8

Kha-bgt-hsi | Preset | 01 | Preset 8 saturation | 0x00-0xFF
Kha-bgt-hsi | Preset | 02 | Preset 8 intensity | 0x00-0xFF
Kha-bgt-hsi | Preset | 03 | Preset 9 enabled | 0 = Off, 1= On
Kha-bgt-hsi | Preset | 04 | Preset 9 hue | 0x00-0xFF
Kha-bgt-hsi | Preset | 05 | Preset 9 saturation | 0x00-0xFF
Kha-bgt-hsi | Preset | 06 | Preset 9 intensity | 0x00-0xFF
Kha-bgt-hsi | Preset | 07 | Preset A enabled | 0 = Off, 1= On
Kha-bgt-hsi | Preset | 08 | Preset A hue | 0x00-0xFF
Kha-bgt-hsi | Preset | 09 | Preset A saturation | 0x00-0xFF
Kha-bgt-hsi | Preset | 0A | Preset A intensity | 0x00-0xFF
Kha-bgt-hsi | Preset | 0B | Preset B enabled | 0 = Off, 1= On
Kha-bgt-hsi | Preset | 0C | Preset B hue | 0x00-0xFF
Kha-bgt-hsi | Preset | 0D | Preset B saturation | 0x00-0xFF
Kha-bgt-hsi | Preset | 0E | Preset B intensity | 0x00-0xFF
Kha-bgt-hsi | Preset | 0F | Preset C enabled | 0 = Off, 1= On
Kha-bgt-hsi | Preset | 10 | Preset C hue | 0x00-0xFF
Kha-bgt-hsi | Preset | 11 | Preset C saturation | 0x00-0xFF
Kha-bgt-hsi | Preset | 12 | Preset C intensity | 0x00-0xFF
Kha-bgt-hsi | Preset | 13 | Preset D enabled | 0 = Off, 1= On
Kha-bgt-hsi | Preset | 14 | Preset D hue | 0x00-0xFF
Kha-bgt-hsi | Preset | 15 | Preset D saturation | 0x00-0xFF
Kha-bgt-hsi | Preset | 16 | Preset D intensity | 0x00-0xFF
Kha-bgt-hsi | Preset | 17 | Preset E enabled | 0 = Off, 1= On
Kha-bgt-hsi | Preset | 18 | Preset E hue | 0x00-0xFF
Kha-bgt-hsi | Preset | 19 | Preset E saturation | 0x00-0xFF
Kha-bgt-hsi | Preset | 1A | Preset E intensity | 0x00-0xFF
Kha-bgt-hsi | Preset | 1B | Preset F enabled | 0 = Off, 1= On
Kha-bgt-hsi | Preset | 1C | Preset F hue | 0x00-0xFF
Kha-bgt-hsi | Preset | 1D | Preset F saturation | 0x00-0xFF
Kha-bgt-hsi | Preset | 1E | Preset F intensity | 0x00-0xFF
Kha-bgt-kaox | Device | 00 | Send to device id | 0x00-0xFE
Kha-bgt-kaox | Preset | 01 | Preset 0 enabled | 0 = Off, 1= On
Kha-bgt-kaox | Preset | 02 | Preset 0 mode | 0=Off, 1=Low, 2=Gradient, 3=Full
Kha-bgt-kaox | Preset | 03 | Preset 1 enabled | 0 = Off, 1= On
Kha-bgt-kaox | Preset | 04 | Preset 1 mode | 0=Off, 1=Low, 2=Gradient, 3=Full

REGISTER

Seite 9

Kha-bgt-kaox | Preset | 05 | Preset 2 enabled | 0 = Off, 1= On
Kha-bgt-kaox | Preset | 06 | Preset 2 mode | 0=Off, 1=Low, 2=Gradient, 3=Full
Kha-bgt-kaox | Preset | 07 | Preset 3 enabled | 0 = Off, 1= On
Kha-bgt-kaox | Preset | 08 | Preset 3 mode | 0=Off, 1=Low, 2=Gradient, 3=Full
Kha-bgt-kaox | Preset | 09 | Preset 4 enabled | 0 = Off, 1= On
Kha-bgt-kaox | Preset | 0A | Preset 4 mode | 0=Off, 1=Low, 2=Gradient, 3=Full
Kha-bgt-kaox | Preset | 0B | Preset 5 enabled | 0 = Off, 1= On
Kha-bgt-kaox | Preset | 0C | Preset 5 mode | 0=Off, 1=Low, 2=Gradient, 3=Full
Kha-bgt-kaox | Preset | 0D | Preset 6 enabled | 0 = Off, 1= On
Kha-bgt-kaox | Preset | 0E | Preset 6 mode | 0=Off, 1=Low, 2=Gradient, 3=Full
Kha-bgt-kaox | Preset | 0F | Preset 7 enabled | 0 = Off, 1= On
Kha-bgt-kaox | Preset | 10 | Preset 7 mode | 0=Off, 1=Low, 2=Gradient, 3=Full
Kha-bgt-kaox | Preset | 11 | Preset 8 enabled | 0 = Off, 1= On
Kha-bgt-kaox | Preset | 12 | Preset 8 mode | 0=Off, 1=Low, 2=Gradient, 3=Full
Kha-bgt-kaox | Preset | 13 | Preset 9 enabled | 0 = Off, 1= On
Kha-bgt-kaox | Preset | 14 | Preset 9 mode | 0=Off, 1=Low, 2=Gradient, 3=Full
Kha-bgt-kaox | Preset | 15 | Preset A enabled | 0 = Off, 1= On
Kha-bgt-kaox | Preset | 16 | Preset A mode | 0=Off, 1=Low, 2=Gradient, 3=Full
Kha-bgt-kaox | Preset | 17 | Preset B enabled | 0 = Off, 1= On
Kha-bgt-kaox | Preset | 18 | Preset B mode | 0=Off, 1=Low, 2=Gradient, 3=Full
Kha-bgt-kaox | Preset | 19 | Preset C enabled | 0 = Off, 1= On
Kha-bgt-kaox | Preset | 1A | Preset C mode | 0=Off, 1=Low, 2=Gradient, 3=Full
Kha-bgt-kaox | Preset | 1B | Preset D enabled | 0 = Off, 1= On
Kha-bgt-kaox | Preset | 1C | Preset D mode | 0=Off, 1=Low, 2=Gradient, 3=Full
Kha-bgt-kaox | Preset | 1D | Preset E enabled | 0 = Off, 1= On
Kha-bgt-kaox | Preset | 1E | Preset E mode | 0=Off, 1=Low, 2=Gradient, 3=Full
Kha-bgt-kaox | Preset | 1F | Preset F enabled | 0 = Off, 1= On
Kha-bgt-kaox | Preset | 20 | Preset F mode | 0=Off, 1=Low, 2=Gradient, 3=Full
Kha-bgt-main | Device | 00 | Shutdown time out | 0x00-0xFF (sec)
Kha-bgt-power | Device | 00 | Button 0 node dev id | 0x01-0xEF | Off
Kha-bgt-power | Device | 01 | Button 0 node reg addr | 0x00-0xEE | Off
Kha-bgt-power | Device | 02 | Button 1 node dev id | 0x01-0xEF | Off
Kha-bgt-power | Device | 03 | Button 1 node reg addr | 0x00-0xEE | Off
Kha-bgt-power | Device | 04 | Button 2 node dev id | 0x01-0xEF | Off
Kha-bgt-power | Device | 05 | Button 2 node reg addr | 0x00-0xEE | Off

REGISTER

Seite 10

Kha-bgt-power | Device | 06 | Button 3 node dev id | 0x01-0xEF | Off
Kha-bgt-power | Device | 07 | Button 3 node reg addr | 0x00-0xEE | Off
Kha-bgt-power | Preset | 08 | Preset 0 enabled | 0 = Off, 1= On
Kha-bgt-power | Preset | 09 | Preset 0 Button 0 | 0=Off, 1=On, 2=Unchanged
Kha-bgt-power | Preset | 0A | Preset 0 Button 1 | 0=Off, 1=On, 2=Unchanged
Kha-bgt-power | Preset | 0B | Preset 0 Button 2 | 0=Off, 1=On, 2=Unchanged
Kha-bgt-power | Preset | 0C | Preset 0 Button 3 | 0=Off, 1=On, 2=Unchanged
Kha-bgt-power | Preset | 0D | Preset 1 enabled | 0 = Off, 1= On
Kha-bgt-power | Preset | 0E | Preset 1 Button 0 | 0=Off, 1=On, 2=Unchanged
Kha-bgt-power | Preset | 0F | Preset 1 Button 1 | 0=Off, 1=On, 2=Unchanged
Kha-bgt-power | Preset | 10 | Preset 1 Button 2 | 0=Off, 1=On, 2=Unchanged
Kha-bgt-power | Preset | 11 | Preset 1 Button 3 | 0=Off, 1=On, 2=Unchanged
Kha-bgt-power | Preset | 12 | Preset 2 enabled | 0 = Off, 1= On
Kha-bgt-power | Preset | 13 | Preset 2 Button 0 | 0=Off, 1=On, 2=Unchanged
Kha-bgt-power | Preset | 14 | Preset 2 Button 1 | 0=Off, 1=On, 2=Unchanged
Kha-bgt-power | Preset | 15 | Preset 2 Button 2 | 0=Off, 1=On, 2=Unchanged
Kha-bgt-power | Preset | 16 | Preset 2 Button 3 | 0=Off, 1=On, 2=Unchanged
Kha-bgt-power | Preset | 17 | Preset 3 enabled | 0 = Off, 1= On
Kha-bgt-power | Preset | 18 | Preset 3 Button 0 | 0=Off, 1=On, 2=Unchanged
Kha-bgt-power | Preset | 19 | Preset 3 Button 1 | 0=Off, 1=On, 2=Unchanged
Kha-bgt-power | Preset | 1A | Preset 3 Button 2 | 0=Off, 1=On, 2=Unchanged
Kha-bgt-power | Preset | 1B | Preset 3 Button 3 | 0=Off, 1=On, 2=Unchanged
Kha-bgt-power | Preset | 1C | Preset 4 enabled | 0 = Off, 1= On
Kha-bgt-power | Preset | 1D | Preset 4 Button 0 | 0=Off, 1=On, 2=Unchanged
Kha-bgt-power | Preset | 1E | Preset 4 Button 1 | 0=Off, 1=On, 2=Unchanged
Kha-bgt-power | Preset | 1F | Preset 4 Button 2 | 0=Off, 1=On, 2=Unchanged
Kha-bgt-power | Preset | 20 | Preset 4 Button 3 | 0=Off, 1=On, 2=Unchanged
Kha-bgt-power | Preset | 21 | Preset 5 enabled | 0 = Off, 1= On
Kha-bgt-power | Preset | 22 | Preset 5 Button 0 | 0=Off, 1=On, 2=Unchanged
Kha-bgt-power | Preset | 23 | Preset 5 Button 1 | 0=Off, 1=On, 2=Unchanged
Kha-bgt-power | Preset | 24 | Preset 5 Button 2 | 0=Off, 1=On, 2=Unchanged
Kha-bgt-power | Preset | 25 | Preset 5 Button 3 | 0=Off, 1=On, 2=Unchanged
Kha-bgt-power | Preset | 26 | Preset 6 enabled | 0 = Off, 1= On
Kha-bgt-power | Preset | 27 | Preset 6 Button 0 | 0=Off, 1=On, 2=Unchanged
Kha-bgt-power | Preset | 28 | Preset 6 Button 1 | 0=Off, 1=On, 2=Unchanged

REGISTER

Seite 11

Kha-bgt-power | Preset | 29 | Preset 6 Button 2 | 0=Off, 1=On, 2=Unchanged
Kha-bgt-power | Preset | 2A | Preset 6 Button 3 | 0=Off, 1=On, 2=Unchanged
Kha-bgt-power | Preset | 2B | Preset 7 enabled | 0 = Off, 1= On
Kha-bgt-power | Preset | 2C | Preset 7 Button 0 | 0=Off, 1=On, 2=Unchanged
Kha-bgt-power | Preset | 2D | Preset 7 Button 1 | 0=Off, 1=On, 2=Unchanged
Kha-bgt-power | Preset | 2E | Preset 7 Button 2 | 0=Off, 1=On, 2=Unchanged
Kha-bgt-power | Preset | 2F | Preset 7 Button 3 | 0=Off, 1=On, 2=Unchanged
Kha-bgt-power | Preset | 30 | Preset 8 enabled | 0 = Off, 1= On
Kha-bgt-power | Preset | 31 | Preset 8 Button 0 | 0=Off, 1=On, 2=Unchanged
Kha-bgt-power | Preset | 32 | Preset 8 Button 1 | 0=Off, 1=On, 2=Unchanged
Kha-bgt-power | Preset | 33 | Preset 8 Button 2 | 0=Off, 1=On, 2=Unchanged
Kha-bgt-power | Preset | 34 | Preset 8 Button 3 | 0=Off, 1=On, 2=Unchanged
Kha-bgt-power | Preset | 35 | Preset 9 enabled | 0 = Off, 1= On
Kha-bgt-power | Preset | 36 | Preset 9 Button 0 | 0=Off, 1=On, 2=Unchanged
Kha-bgt-power | Preset | 37 | Preset 9 Button 1 | 0=Off, 1=On, 2=Unchanged
Kha-bgt-power | Preset | 38 | Preset 9 Button 2 | 0=Off, 1=On, 2=Unchanged
Kha-bgt-power | Preset | 39 | Preset 9 Button 3 | 0=Off, 1=On, 2=Unchanged
Kha-bgt-power | Preset | 3A | Preset A enabled | 0 = Off, 1= On
Kha-bgt-power | Preset | 3B | Preset A Button 0 | 0=Off, 1=On, 2=Unchanged
Kha-bgt-power | Preset | 3C | Preset A Button 1 | 0=Off, 1=On, 2=Unchanged
Kha-bgt-power | Preset | 3D | Preset A Button 2 | 0=Off, 1=On, 2=Unchanged
Kha-bgt-power | Preset | 3E | Preset A Button 3 | 0=Off, 1=On, 2=Unchanged
Kha-bgt-power | Preset | 3F | Preset B enabled | 0 = Off, 1= On
Kha-bgt-power | Preset | 40 | Preset B Button 0 | 0=Off, 1=On, 2=Unchanged
Kha-bgt-power | Preset | 41 | Preset B Button 1 | 0=Off, 1=On, 2=Unchanged
Kha-bgt-power | Preset | 42 | Preset B Button 2 | 0=Off, 1=On, 2=Unchanged
Kha-bgt-power | Preset | 43 | Preset B Button 3 | 0=Off, 1=On, 2=Unchanged
Kha-bgt-power | Preset | 44 | Preset C enabled | 0 = Off, 1= On
Kha-bgt-power | Preset | 45 | Preset C Button 0 | 0=Off, 1=On, 2=Unchanged
Kha-bgt-power | Preset | 46 | Preset C Button 1 | 0=Off, 1=On, 2=Unchanged
Kha-bgt-power | Preset | 47 | Preset C Button 2 | 0=Off, 1=On, 2=Unchanged
Kha-bgt-power | Preset | 48 | Preset C Button 3 | 0=Off, 1=On, 2=Unchanged
Kha-bgt-power | Preset | 49 | Preset D enabled | 0 = Off, 1= On
Kha-bgt-power | Preset | 4A | Preset D Button 0 | 0=Off, 1=On, 2=Unchanged
Kha-bgt-power | Preset | 4B | Preset D Button 1 | 0=Off, 1=On, 2=Unchanged

REGISTER

Seite 12

Kha-bgt-power | Preset | 4C | Preset D Button 2 | 0=Off, 1=On, 2=Unchanged
Kha-bgt-power | Preset | 4D | Preset D Button 3 | 0=Off, 1=On, 2=Unchanged
Kha-bgt-power | Preset | 4E | Preset E enabled | 0 = Off, 1= On
Kha-bgt-power | Preset | 4F | Preset E Button 0 | 0=Off, 1=On, 2=Unchanged
Kha-bgt-power | Preset | 50 | Preset E Button 1 | 0=Off, 1=On, 2=Unchanged
Kha-bgt-power | Preset | 51 | Preset E Button 2 | 0=Off, 1=On, 2=Unchanged
Kha-bgt-power | Preset | 52 | Preset E Button 3 | 0=Off, 1=On, 2=Unchanged
Kha-bgt-power | Preset | 53 | Preset F enabled | 0 = Off, 1= On
Kha-bgt-power | Preset | 54 | Preset F Button 0 | 0=Off, 1=On, 2=Unchanged
Kha-bgt-power | Preset | 55 | Preset F Button 1 | 0=Off, 1=On, 2=Unchanged
Kha-bgt-power | Preset | 56 | Preset F Button 2 | 0=Off, 1=On, 2=Unchanged
Kha-bgt-power | Preset | 57 | Preset F Button 3 | 0=Off, 1=On, 2=Unchanged
Kha-bgt-preset | Device | 00 | Button 0 preset code | 0x00-0x0F | 0xFF
Kha-bgt-preset | Device | 01 | Button 1 preset code | 0x00-0x0F | 0xFF
Kha-bgt-preset | Device | 02 | Button 2 preset code | 0x00-0x0F | 0xFF
Kha-bgt-preset | Device | 03 | Button 3 preset code | 0x00-0x0F | 0xFF
Kha-bgt-rainbow | Device | 00 | Send to device id | 0x00-0xFE
Kha-bgt-rainbow | Preset | 01 | Preset 0 enabled | 0 = Off, 1= On
Kha-bgt-rainbow | Preset | 02 | Preset 0 anim speed | 0x00-0xFF
Kha-bgt-rainbow | Preset | 03 | Preset 0 anim width | 0x00-0xFF
Kha-bgt-rainbow | Preset | 04 | Preset 0 anim enabled | 0 = Off, 1= On
Kha-bgt-rainbow | Preset | 05 | Preset 1 enabled | 0 = Off, 1= On
Kha-bgt-rainbow | Preset | 06 | Preset 1 anim speed | 0x00-0xFF
Kha-bgt-rainbow | Preset | 07 | Preset 1 anim width | 0x00-0xFF
Kha-bgt-rainbow | Preset | 08 | Preset 1 anim enabled | 0 = Off, 1= On
Kha-bgt-rainbow | Preset | 09 | Preset 2 enabled | 0 = Off, 1= On
Kha-bgt-rainbow | Preset | 0A | Preset 2 anim speed | 0x00-0xFF
Kha-bgt-rainbow | Preset | 0B | Preset 2 anim width | 0x00-0xFF
Kha-bgt-rainbow | Preset | 0C | Preset 2 anim enabled | 0 = Off, 1= On
Kha-bgt-rainbow | Preset | 0D | Preset 3 enabled | 0 = Off, 1= On
Kha-bgt-rainbow | Preset | 0E | Preset 3 anim speed | 0x00-0xFF
Kha-bgt-rainbow | Preset | 0F | Preset 3 anim width | 0x00-0xFF
Kha-bgt-rainbow | Preset | 10 | Preset 3 anim enabled | 0 = Off, 1= On
Kha-bgt-rainbow | Preset | 11 | Preset 4 enabled | 0 = Off, 1= On
Kha-bgt-rainbow | Preset | 12 | Preset 4 anim speed | 0x00-0xFF

REGISTER

Seite 13

Kha-bgt-rainbow | Preset | 13 | Preset 4 anim width | 0x00-0xFF
Kha-bgt-rainbow | Preset | 14 | Preset 4 anim enabled | 0 = Off, 1= On
Kha-bgt-rainbow | Preset | 15 | Preset 5 enabled | 0 = Off, 1= On
Kha-bgt-rainbow | Preset | 16 | Preset 5 anim speed | 0x00-0xFF
Kha-bgt-rainbow | Preset | 17 | Preset 5 anim width | 0x00-0xFF
Kha-bgt-rainbow | Preset | 18 | Preset 5 anim enabled | 0 = Off, 1= On
Kha-bgt-rainbow | Preset | 19 | Preset 6 enabled | 0 = Off, 1= On
Kha-bgt-rainbow | Preset | 1A | Preset 6 anim speed | 0x00-0xFF
Kha-bgt-rainbow | Preset | 1B | Preset 6 anim width | 0x00-0xFF
Kha-bgt-rainbow | Preset | 1C | Preset 6 anim enabled | 0 = Off, 1= On
Kha-bgt-rainbow | Preset | 1D | Preset 7 enabled | 0 = Off, 1= On
Kha-bgt-rainbow | Preset | 1E | Preset 7 anim speed | 0x00-0xFF
Kha-bgt-rainbow | Preset | 1F | Preset 7 anim width | 0x00-0xFF
Kha-bgt-rainbow | Preset | 20 | Preset 7 anim enabled | 0 = Off, 1= On
Kha-bgt-rainbow | Preset | 21 | Preset 8 enabled | 0 = Off, 1= On
Kha-bgt-rainbow | Preset | 22 | Preset 8 anim speed | 0x00-0xFF
Kha-bgt-rainbow | Preset | 23 | Preset 8 anim width | 0x00-0xFF
Kha-bgt-rainbow | Preset | 24 | Preset 8 anim enabled | 0 = Off, 1= On
Kha-bgt-rainbow | Preset | 25 | Preset 9 enabled | 0 = Off, 1= On
Kha-bgt-rainbow | Preset | 26 | Preset 9 anim speed | 0x00-0xFF
Kha-bgt-rainbow | Preset | 27 | Preset 9 anim width | 0x00-0xFF
Kha-bgt-rainbow | Preset | 28 | Preset 9 anim enabled | 0 = Off, 1= On
Kha-bgt-rainbow | Preset | 29 | Preset A enabled | 0 = Off, 1= On
Kha-bgt-rainbow | Preset | 2A | Preset A anim speed | 0x00-0xFF
Kha-bgt-rainbow | Preset | 2B | Preset A anim width | 0x00-0xFF
Kha-bgt-rainbow | Preset | 2C | Preset A anim enabled | 0 = Off, 1= On
Kha-bgt-rainbow | Preset | 2D | Preset B enabled | 0 = Off, 1= On
Kha-bgt-rainbow | Preset | 2E | Preset B anim speed | 0x00-0xFF
Kha-bgt-rainbow | Preset | 2F | Preset B anim width | 0x00-0xFF
Kha-bgt-rainbow | Preset | 30 | Preset B anim enabled | 0 = Off, 1= On
Kha-bgt-rainbow | Preset | 31 | Preset C enabled | 0 = Off, 1= On
Kha-bgt-rainbow | Preset | 32 | Preset C anim speed | 0x00-0xFF
Kha-bgt-rainbow | Preset | 33 | Preset C anim width | 0x00-0xFF
Kha-bgt-rainbow | Preset | 34 | Preset C anim enabled | 0 = Off, 1= On
Kha-bgt-rainbow | Preset | 35 | Preset D enabled | 0 = Off, 1= On

REGISTER

Seite 14

Kha-bgt-rainbow | Preset | 36 | Preset D anim speed | 0x00-0xFF
Kha-bgt-rainbow | Preset | 37 | Preset D anim width | 0x00-0xFF
Kha-bgt-rainbow | Preset | 38 | Preset D anim enabled | 0 = Off, 1= On
Kha-bgt-rainbow | Preset | 39 | Preset E enabled | 0 = Off, 1= On
Kha-bgt-rainbow | Preset | 3A | Preset E anim speed | 0x00-0xFF
Kha-bgt-rainbow | Preset | 3B | Preset E anim width | 0x00-0xFF
Kha-bgt-rainbow | Preset | 3C | Preset E anim enabled | 0 = Off, 1= On
Kha-bgt-rainbow | Preset | 3D | Preset F enabled | 0 = Off, 1= On
Kha-bgt-rainbow | Preset | 3E | Preset F anim speed | 0x00-0xFF
Kha-bgt-rainbow | Preset | 3F | Preset F anim width | 0x00-0xFF
Kha-bgt-rainbow | Preset | 40 | Preset F anim enabled | 0 = Off, 1= On
Kha-gateway-usb | Device | 00 | Print Proto | 0=Off, 1=On
Kha-gateway-usb | Device | 01 | Print Human | 0=Off, 1=On
Kha-led-ikea-node | Device | 00 | LED Selection | 0=Off, 1=Low, 2=Gradient, 3=Full
Kha-led-ikea-node | Device | 01 | Show Identification | 1=trigger once
Kha-led-ikea-node | Device | 02 | LED Amount | 0x00-0xFF
Kha-led-ikea-node | Device | 03 | LED Orientation | 0 = None, 1 = Vertical, 2 = Horizontal
Kha-led-ikea-node | Device | 04 | LED Low Cut | 0x00-0xFF
Kha-led-ikea-node | Device | 05 | Animation Location | 0x00-0xFF
Kha-led-strip | Device | 00 | LED Selection | 0=Off, !0=Full
Kha-led-strip | Device | 01 | Amount | 0-240 Leds
Kha-led-strip | Device | 02 | Communication | 0 = APA102, 1 = WS2814
Kha-led-strip | Device | 03 | Intensity Max | 0x00-0xFF
kha-relay-2x3-node | Device | 00 | Socket 0 enabled | 0=Off, 1=On
kha-relay-2x3-node | Device | 01 | Socket 1 enabled | 0=Off, 1=On
kha-relay-2x3-node | Device | 02 | Socket 2 enabled | 0=Off, 1=On
kha-relay-2x3-node | Device | 03 | Socket 3 enabled | 0=Off, 1=On
kha-relay-2x3-node | Device | 04 | Socket 4 enabled | 0=Off, 1=On
kha-relay-2x3-node | Device | 05 | Socket 5 enabled | 0=Off, 1=On
kha-relay-2x3-node | Device | 06 | Socket 0 power-off timer | 0x01-0xFF (min) | 0x00 = Off
kha-relay-2x3-node | Device | 07 | Socket 1 power-off timer | 0x01-0xFF (min) | 0x00 = Off
kha-relay-2x3-node | Device | 08 | Socket 2 power-off timer | 0x01-0xFF (min) | 0x00 = Off
kha-relay-2x3-node | Device | 09 | Socket 3 power-off timer | 0x01-0xFF (min) | 0x00 = Off
kha-relay-2x3-node | Device | 0A | Socket 4 power-off timer | 0x01-0xFF (min) | 0x00 = Off
kha-relay-2x3-node | Device | 0B | Socket 5 power-off timer | 0x01-0xFF (min) | 0x00 = Off

ADDR ALLOCATED

Seite 15

ADDR | Group | Device | Comment
E1 | 00 | Kha-gateway-usb | Connected to machariel.qnet
E0 | 00 | Kha-gateway-usb | Connected to blacksheep.qnet
D1 | 00 | Kha-remote
D0 | 00 | Kha-main
C7 | F5 | Kha-led-strip | Desk
C6 | F5 | Kha-led-strip | Bed
C5 | F4 | kha-relay-2x3-node | South
C4 | F4 | kha-relay-2x3-node | North
C3 | F1 | Kha-led-ikea-node | East Oxberg
C2 | F1 | Kha-led-ikea-node | North Kallax
C1 | F1 | Kha-led-ikea-node | West Oxberg
C0 | F1 | Kha-led-ikea-node | South Kallax
BC | F3 | Kha-bgt-power | Strip
BB | 00 | Kha-bgt-preset
BA | 00 | Kha-bgt-rainbow
B9 | 00 | Kha-bgt-hsi
B8 | 00 | Kha-bgt-kaox
B7 | 00 | Kha-bgt-guru
B6 | 00 | Kha-bgt-dark
B5 | F3 | Kha-bgt-power | Misc
B4 | F3 | Kha-bgt-power | Projects
B3 | F3 | Kha-bgt-power | Lights
B2 | F2 | Kha-bgt-audio | Audio Out
B1 | F2 | Kha-bgt-audio | Audio In
B0 | 00 | Kha-bgt-main

REGISTER SETUP

Seite 16

Module | Commands
Kha-bgt-audio

Kha-bgt-dark

Kha-bgt-guru

Kha-bgt-hsi

Kha-bgt-kaox

Kha-bgt-main

F2DF
B1D503010001000000010000000000 B2D503010001000101010000000000 F2DE

Wipe

Save

B6DF
B6D5000100
B6D5060100
B6DE

Wipe
Preset 0 off: Off
Preset 3 TV: Off
Save

B7DF
B7D500FF
B7D5010B
B7DE

Wipe
Broadcast to FF
Broadcast every 11 minutes Save

B9DF
B9D500FF
B9D505010000FF
B9D5090100FFFF
B9D50D010000FF
B9DE

Wipe
Send to FF
Preset 1 shutdown: no saturation, full intensity Preset 2 party: full saturation, full intensity Preset 3 tv: no saturation, full intensity
Save
B8DF
B8D500F1
B8D5010100
B8D5030101
B8D5050103
B8D5070101
B8D5090100
B8D50B0100
B8DE

Wipe
Send to F1
Preset 0 off: Off
Preset 1 shutdown: Low
Preset 2 party: Full
Preset 3 TV: Low
Preset 4 tinker: Off
Preset 5 pc: Off
Save

B0DF
B0D50096
B0DE

Wipe
Timeout 150sec for shutdown Save

REGISTER SETUP

Seite 17

Kha-bgt-power

Kha-bgt-preset

Kha-bgt-rainbow

Kha-gateway-usb

Kha-led-ikea-node

F3DF
B3D5000000C400C504C500
B3D508010200000001020000000102000000010200000001020201010102020001 B4D500C404C403C402C401
B4D508010000000001000000000101020202010000020001020202020102020202 B5D500C502C503C505C501
B5D508010000000001000000000101020202010002020201020102020100020202 BCD50000000000C700C600
BCD508010000000001000000010100000101010000000001000002000100000000 F3DE

Wipe

Save

BBDF
BBD50002030405
BBDE

Wipe
Set presets to party, tv, tinker, pc Save
BADF
BAD500FF
BAD50101000000
BAD50501000000
BAD50901FF2001
BAD50D01000000
BAD51101000000
BAD51501000000
BADE

Wipe
Send to FF
Preset 0 off: Off
Preset 1 shutdown: Off
Preset 2 party: Full
Preset 3 TV: Off
Preset 4 tinker: Off
Preset 5 pc: Off
Save

E0DF
E0D5000100
E0DE
E1DF
E1D5000001
E1DE

Wipe
Print Proto
Save
Wipe
Print Human
Save
F1DF
C0D500000002020200
C1D500000008010302
C2D500000002020203
C3D500000008010305
F1DE

Wipe
Set Amount, Orientation, Low Cut, Location Set Amount, Orientation, Low Cut, Location Set Amount, Orientation, Low Cut, Location Set Amount, Orientation, Low Cut, Location Save

REGISTER SETUP

Seite 18

Kha-led-strip

kha-relay-2x3-node

F5DF
C6D500 00130148
C7D500 00680097
F5DE

Wipe
Bed
Desk
Save
F4DF
C5D50714
C5D50B14
F4DE

Wipe
Socket 1 label printer 20 minutes Socket 5 printer 20 minutes Save

kha-relay-2x3

Seite 19

Node | ID | Box Label | Box Color | Connected | Timer
C4 | 0 | 1 | Green
C4 | 1 | 2 | Green | LED Marquee
C4 | 2 | 3 | Green | NFL
C4 | 3 | 1 | Gray | Floppy
C4 | 4 | 2 | Gray | Projects
C4 | 5 | 3 | Gray | -
C5 | 0 | 1 | Yellow | Light PC
C5 | 1 | 2 | Yellow | Label Printer | 0x14
C5 | 2 | 3 | Yellow | Soundbar
C5 | 3 | 1 | Red | Lab Power Supply
C5 | 4 | 2 | Red | Light Bench
C5 | 5 | 3 | Red | Printer | 0x14

Light Couch

MPLab MCC Build

Seite 20

NVM | NVM | Generate Flash APIs
NVM | NVM | Generate EEPROM APIs
NVM | NVM | Generate Signature Row APIs
Timer | Delay
Timer | RTC | PIT Enable
Timer | RTC | RTC Clock Cycles 8
Timer | RTC | Periodic Interrupt Enable
UART | UART0 | 500000
UART | UART0 | Interrupt Driven
UART | UART0 | 128 / 512
System | CLKCTRL | 24Mhz
System | Configuration Bits | Bootsize 32
System | Configuration Bits | Device used in single supply configuration
System | Configuration Bits | Watchdog Timeout Period 4k / 4s
System | Interrupt Manager | RXC
System | Interrupt Manager | RSX
System | Pins | PA 0,1,3 USART0
System | RSTCTRL | Software Reset Enable
System | WDT | Lock

Building: Execute before build: ..\..\..\tools\kha-timestamp\kha-timestamp.bat GCC Optimize -s
avr-ld: Additional: -Ttext=0x4000
add kha_version.h

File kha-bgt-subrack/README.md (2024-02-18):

# kha-bgt-subrack

Subrack modules

## Photos



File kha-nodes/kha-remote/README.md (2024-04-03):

# kha-remote

433Mhz and IR Remote

## Photos

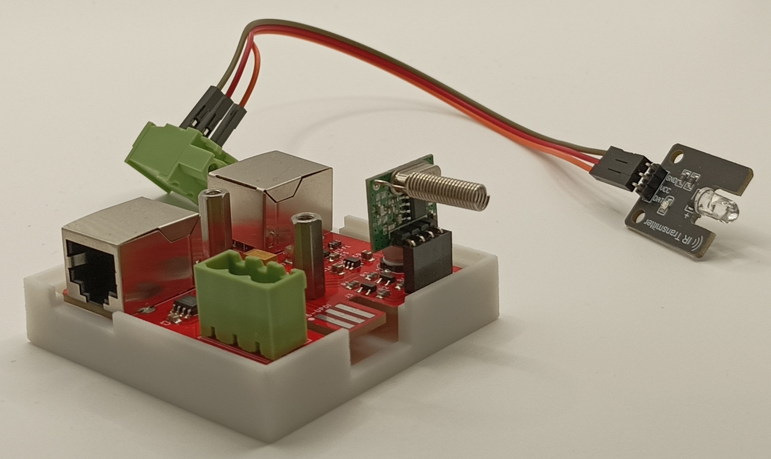
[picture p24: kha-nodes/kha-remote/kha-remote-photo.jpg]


## Render

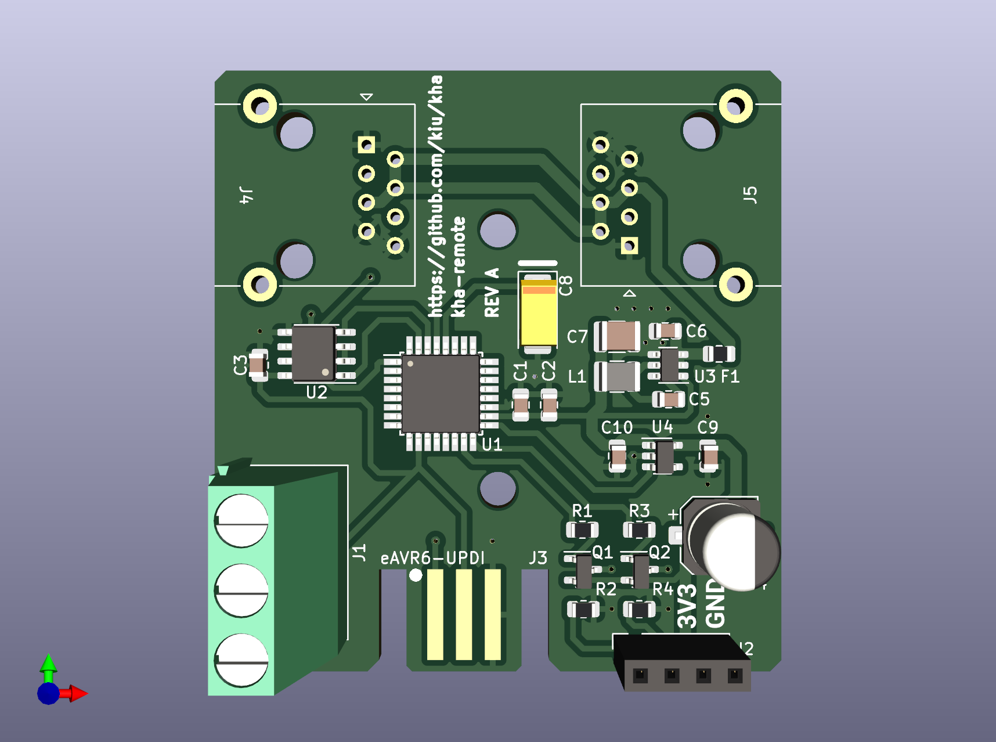
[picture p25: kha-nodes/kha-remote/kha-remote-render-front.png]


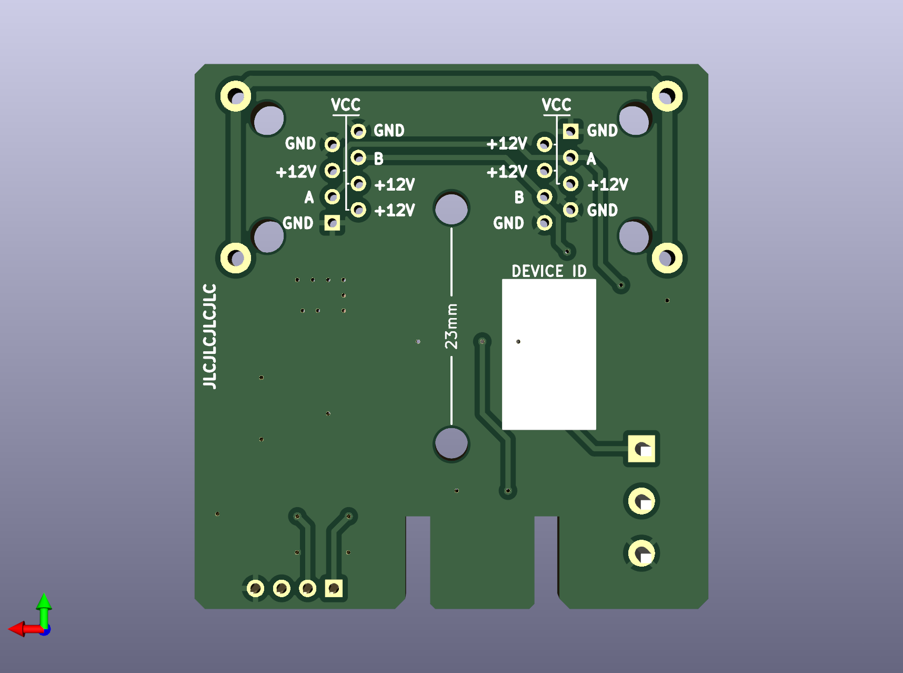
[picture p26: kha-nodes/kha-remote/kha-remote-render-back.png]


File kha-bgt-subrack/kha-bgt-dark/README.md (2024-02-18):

# kha-bgt-dark

Enable/Disable UI Module

## Parts

Use [kha-bgt-generic-base](../../kha-bgt-misc/kha-bgt-generic-base/) as base

## Photos

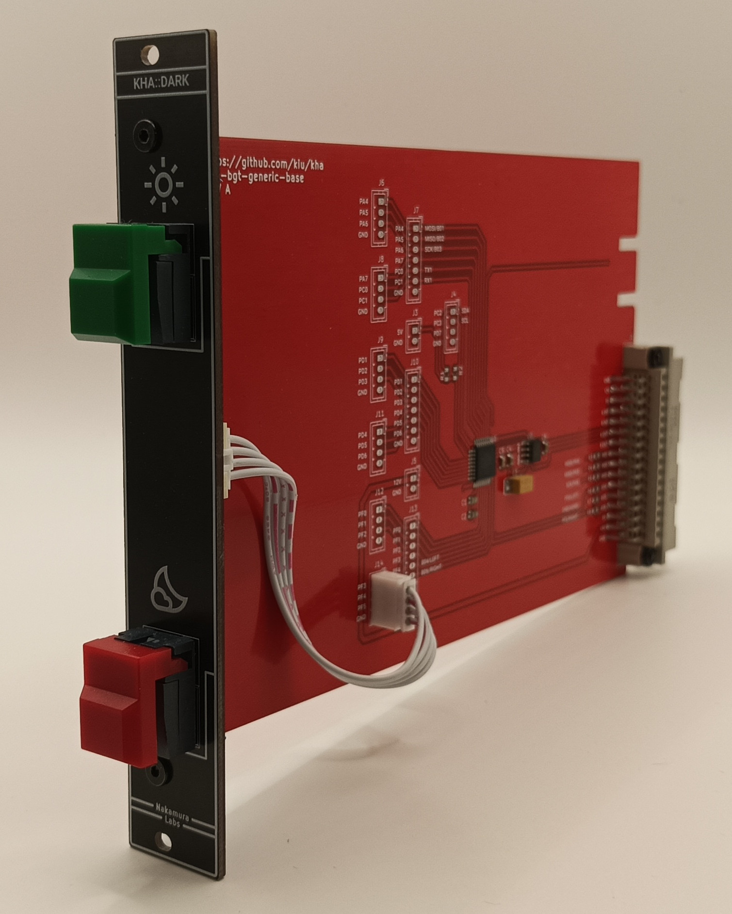
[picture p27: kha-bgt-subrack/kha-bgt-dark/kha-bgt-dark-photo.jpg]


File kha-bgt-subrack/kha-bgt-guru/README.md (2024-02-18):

# kha-bgt-guru

Debug Module

## Parts

Use [kha-bgt-generic-base](../../kha-bgt-misc/kha-bgt-generic-base/) as base

## Photos

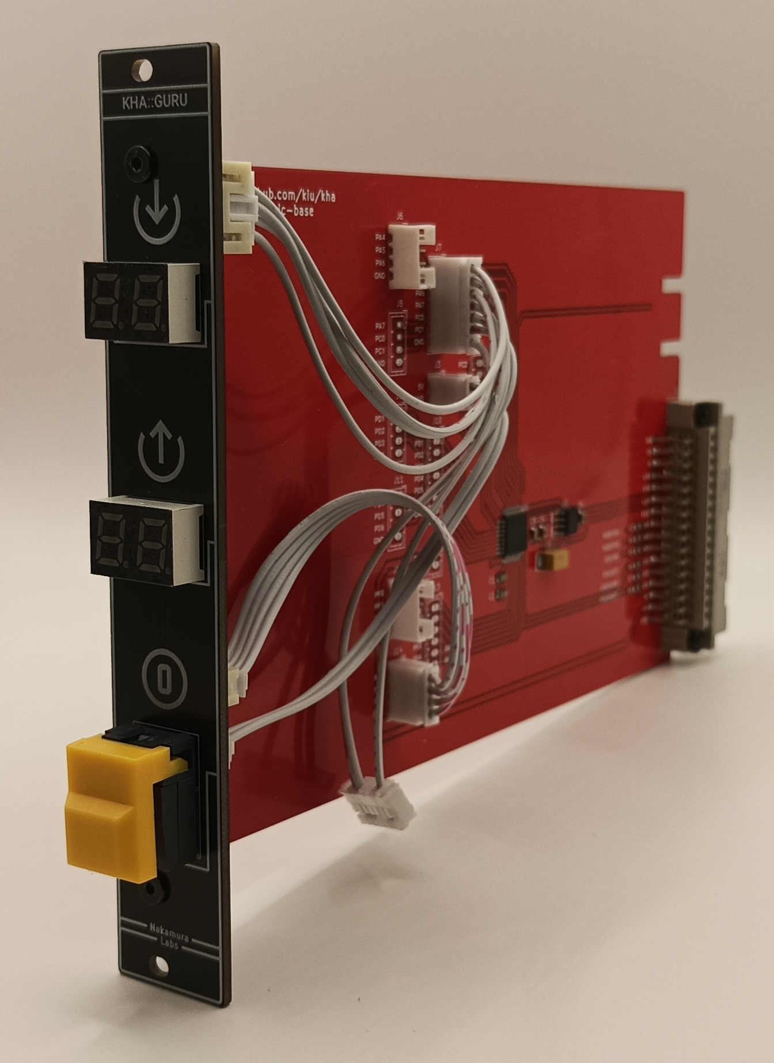
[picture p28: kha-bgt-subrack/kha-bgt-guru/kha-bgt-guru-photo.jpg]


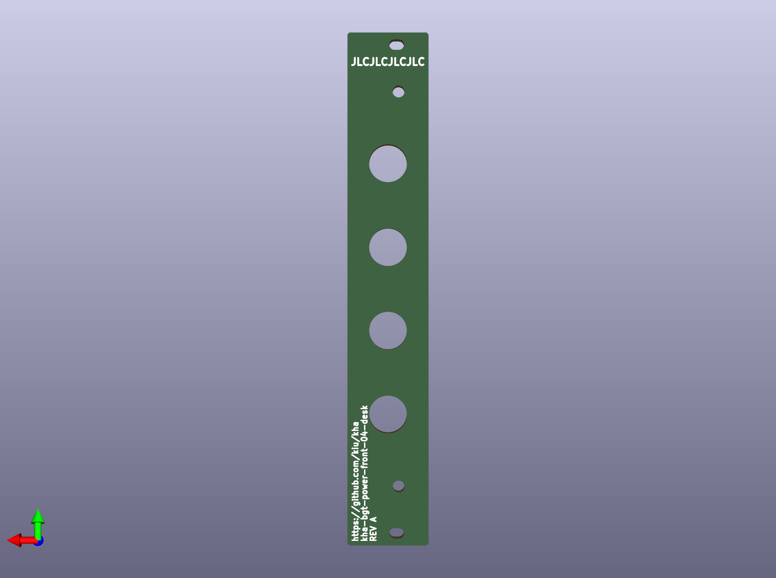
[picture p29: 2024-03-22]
kha-bgt-subrack/kha-bgt-power/kha-bgt-power-front-04-desk/kha-bgt-power-front-04-desk-render-back.png

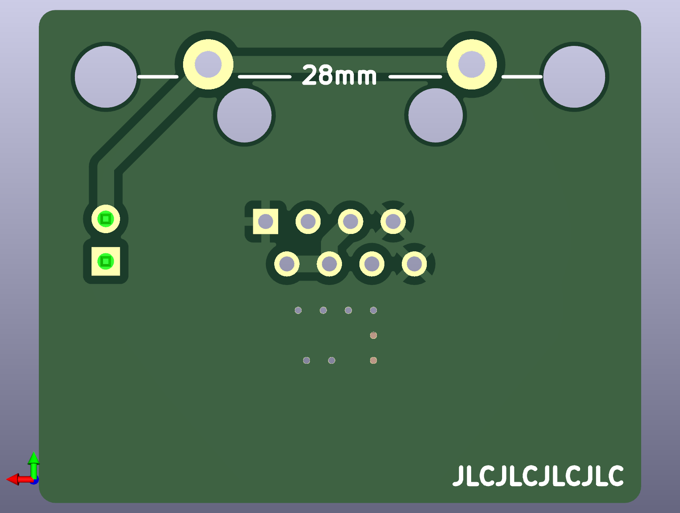
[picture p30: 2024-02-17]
kha-nodes/kha-term/kha-term-render-back.png

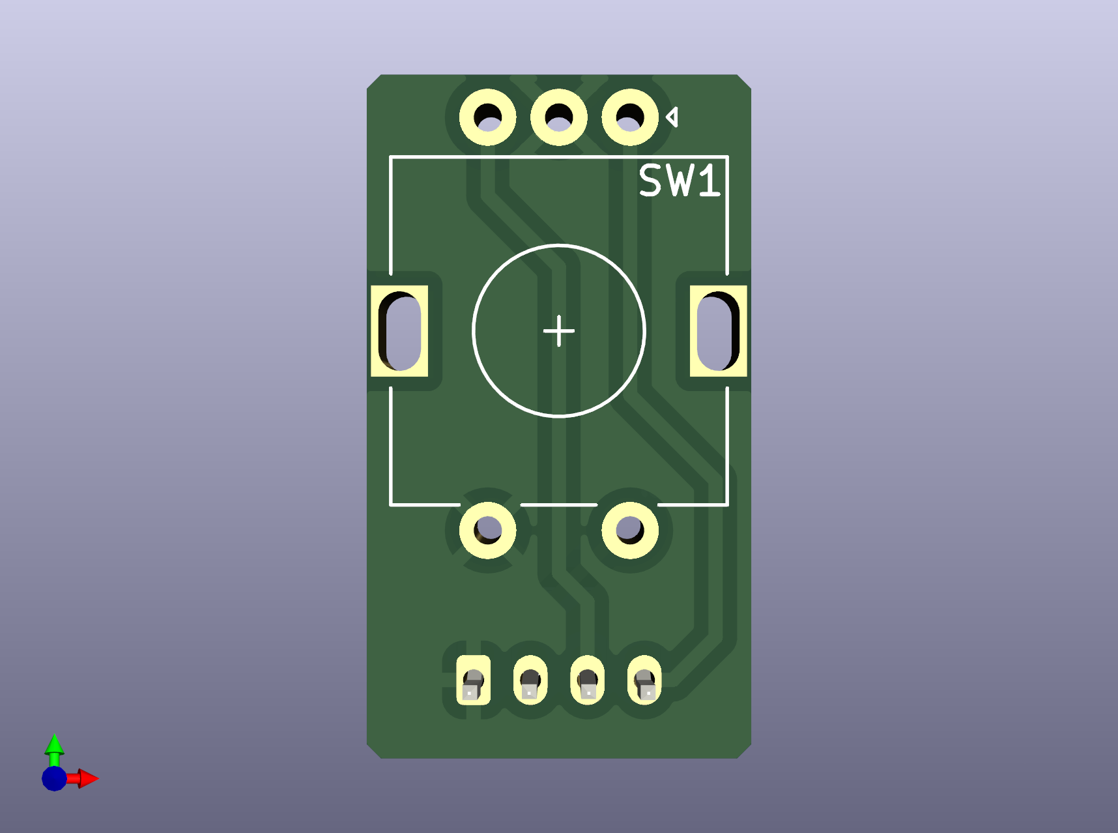
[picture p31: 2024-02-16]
kha-bgt-misc/kha-bgt-generic-rotary-encoder/kha-bgt-generic-rotary-encoder-render-front.png

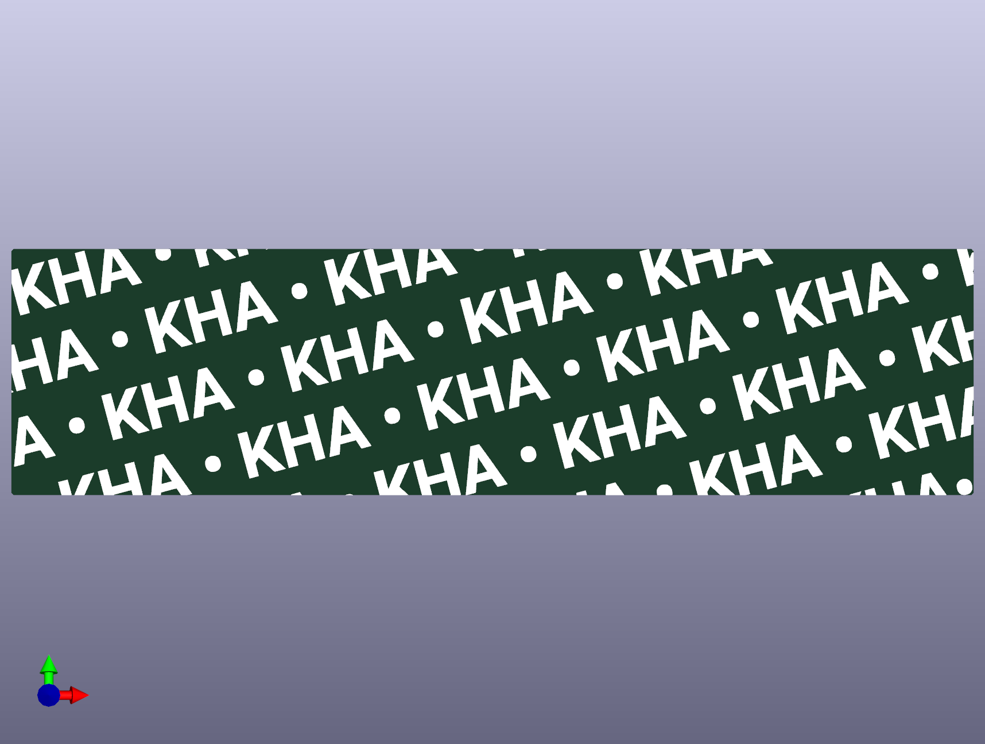
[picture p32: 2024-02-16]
kha-bgt-rack/kha-bgt-cover/kha-bgt-cover-render-front.png

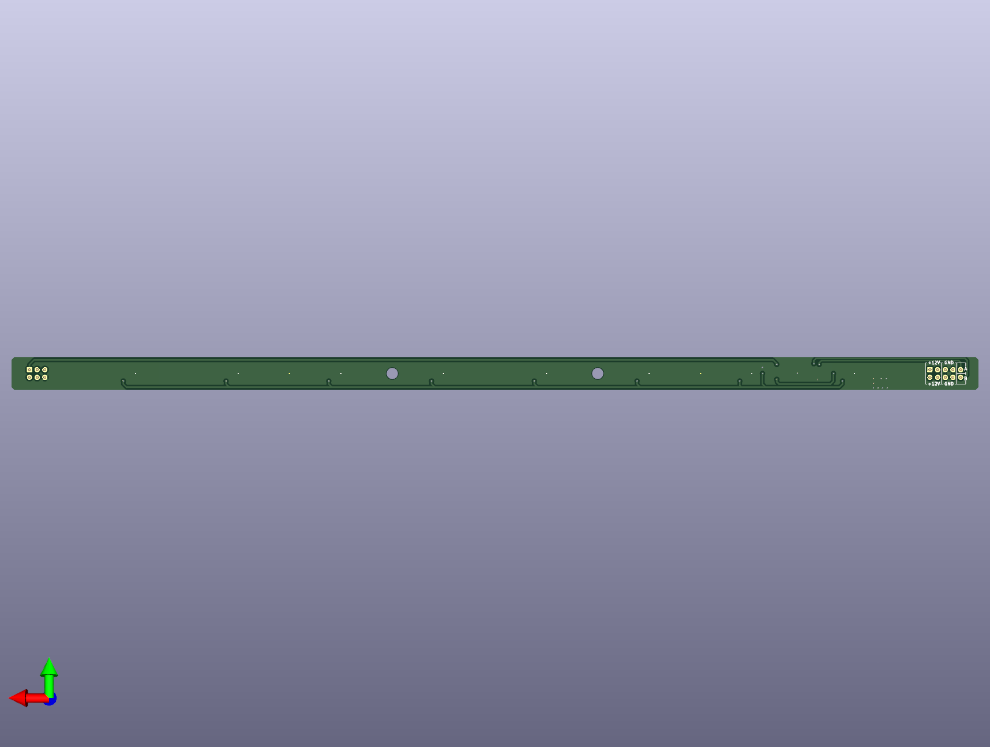
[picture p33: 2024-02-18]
kha-nodes/kha-led-ikea/kha-led-ikea-lighting/kha-led-ikea-kallax/kha-led-ikea-kallax-render-back.png

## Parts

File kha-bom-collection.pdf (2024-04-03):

Parts

Seite 1

Type | ID | Provider | Description
Button | 1005002284607011 | | PB86 Push Button Green / Red / Yellow
Button | KS01-BLV-2 | | Push Button orange
Button | KS01-BLV-13 | | Push Button red/green
Button | 1005005792983870 | | Rectangle Momentary Push Button 6.3V Red / Yellow
Button | 1005004587725359 | | Rectangle Momentary Push Button Cover
Button | PEC11R-4215F-S0024 | | Rotary Encoder
Button | 1005004081506992 | | Rotary Encoder Knob
Cable | 32998004363 | | Flat Ribbon Cable 1.27 8P / 10P
Cable | 4001353071671 | | PH 2.0 2P / 4P / 5P / 7P Cable 10cm
Cable | 4000058023349
Capacitor | C495959 | | 100nF 0805
Capacitor | C11375
Capacitor | C519909 | | 10nF 0805
Capacitor | C15850 | | 10uF 0805
Capacitor | C7216
Capacitor | C77101 | | 47uF 1210
Connector | C963713 | | DIN41612 32P
Connector | ML-C2 32W | | DIN41612 32P A-C C (ept: 103-90014)
Connector | FL-C2 32G4 | | DIN41612 32P A-C C (ept: 304-90014-01)
Connector | C492445
Connector | C601910 | | IDC 2x4 Crimp
Connector | C376157 | | IDC 2x4 Crimp PCB Mount
Connector | C8373 | | IDC 2x5 Crimp
Connector | 1005002322214396 | | IDC 2x5 Crimp Reverse
Connector | C2977596
Connector | C4749178
Connector | C131337 | | PH 2.0 2P
Connector | C160352 | | PH 2.0 2P SMT
Connector | C131334 | | PH 2.0 4P
Connector | C160354 | | PH 2.0 4P SMT
Connector | C157993 | | PH 2.0 5P
Connector | C157981 | | PH 2.0 7P

https://de.aliexpress.com
https://www.tme.eu
https://www.tme.eu
https://de.aliexpress.com
https://de.aliexpress.com
https://www.tme.eu
https://de.aliexpress.com
https://de.aliexpress.com
https://de.aliexpress.com
https://de.aliexpress.com XH 2.54 3P Cable 20cm https://www.lcsc.com
https://www.lcsc.com | 100uF 16V Case C 6032 TAJC107K016RNJ
https://www.lcsc.com
https://www.lcsc.com
https://www.lcsc.com | 220uF 6.3V Case C 6032 TAJC227K006RNJ
https://www.lcsc.com
https://www.lcsc.com
https://www.reichelt.de
https://www.reichelt.de
https://www.lcsc.com | IDC 2x3 PCB Mount SMT
https://www.lcsc.com
https://www.lcsc.com
https://www.lcsc.com
https://de.aliexpress.com
https://www.lcsc.com | IDC 2x5 PCB Mount
https://www.lcsc.com | IDC 2x5 PCB Mount SMT
https://www.lcsc.com
https://www.lcsc.com
https://www.lcsc.com
https://www.lcsc.com
https://www.lcsc.com
https://www.lcsc.com

Parts

Seite 2

Connector | C492401 | Pin Header 1x02 2.54
Connector | C49257
Connector | C2881656
Connector | 1005004301488282 | Pin Header 2.54 Multi Color
Connector | C2685136 | Pin Header 2x02 2.54
Connector | C492420
Connector | C2935921 | Pin Header 2x06 2.54
Connector | C124393 | Pin Socket 1x12 1.27
Connector | TBG-5-PW-3P-GN
Connector | TBW-5.08-3P
Connector | 1005004748652065 | RJ45 Port IDC Straight
Connector | C708610 | RJ45 THT
Connector | 926666961 | Screw Terminal 2P 5.08
Connector | 926666961 | Screw Terminal 3P 5.08
Connector | 105-0U | TAUR 105 Power Socket (green)
Connector | TAUR 105-0R | TAUR 105 Power Socket (red, yellow, gray)
Connector | C1121883 | TRS Audio Jack
Connector | C692438
Connector | C2884943
Connector | 640-USB3076-30-A | USB Micro
Connector | C7429633 | XH 2.54 3P
Fuse | C883096 | BHFUSE BSMD0805-005-15V 50ma/150mA
Fuse | C883099 | BHFUSE BSMD0805-010-15V 100mA/300mA
Fuse | C910823 | BHFUSE BSMD0805-100-12V 1A/2A
IC | C2071056 | AP63205WU-7
IC | C1339884 | ATTINY402-SSN
IC | 494-AVR64DD32-I/PT | AVR64DD32 TQFP
IC | C99652 | CH340E
IC | C102619
IC | C460977 | DMG2302U
IC | C909754 | MMBT3904
IC | C6855 | SP485EEN-L/TR
IC | C19579 | TM1620
IC | C181730 | ULN2003A

https://www.lcsc.com
https://www.lcsc.com | Pin Header 1x03 2.54
https://www.lcsc.com | Pin Header 1x11 1.27
https://de.aliexpress.com
https://www.lcsc.com
https://www.lcsc.com | Pin Header 2x03 2.54
https://www.lcsc.com
https://www.lcsc.com
https://www.tme.eu | Pluggable Terminal 3P 5.08
https://www.tme.eu | Pluggable Terminal 3P 5.08
https://de.aliexpress.com
https://www.lcsc.com
https://de.aliexpress.com
https://de.aliexpress.com
https://www.tme.eu
https://www.reichelt.de
https://www.lcsc.com
https://www.lcsc.com | TRS Audio Jack green
https://www.lcsc.com | TRS Audio Jack pink
https://www.mouser.de
https://www.lcsc.com
https://www.lcsc.com
https://www.lcsc.com
https://www.lcsc.com
https://www.lcsc.com
https://www.lcsc.com
https://www.mouser.de
https://www.lcsc.com
https://www.lcsc.com | DMG2301L-7 P-Channel Mosfet
https://www.lcsc.com
https://www.lcsc.com
https://www.lcsc.com
https://www.lcsc.com
https://www.lcsc.com

Parts

Seite 3

Inductor | C703083 | 1.6A 4.7uH ±20% 2.3A 157mΩ 1210
Jumper/Test | C5274550 | Jumper blue
Jumper/Test | C5274548 | Jumper red
Jumper/Test | C5274551 | Jumper white
Jumper/Test | C5274549 | Jumper yellow
Jumper/Test | C238127 | Test Ring black
Jumper/Test | C2906765 | Test Ring red
Jumper/Test | C238128 | Test Ring yellow
LED | C98222 | LED 0805 blue
LED | C98221 | LED 0805 green
LED | C125091 | LED 0805 yellow
LED | 1005001835638842 | SK6812 RGBWW
LED | C225881 | SUNLIGHT SLR0282BH2C1BD-6.6
Module | 1005003575010329 | Bluetooth Module
Module | 1005004210325836 | POE Injector 12V 2A
Module | 1005006327593563 | IR Transmitter
Module | 4000905994833 | 433Mhz RF Transmitter
Mounting | 1005005070119421 | M2.5x10 Hex Flat
Mounting | 1005005070119421 | M2.5x6 Hex Flat
Mounting | 32798773566 | M3 Nut
Mounting | 1005005070119421 | M3x12 Hex Flat
Mounting | 1005004048407401 | M3x14 Hex Countersunk
Mounting | 1005006060186972 | M3x14 Standoff
Mounting | TFM-M3X5/DR213 | M3x5 Standoff
Mounting | TFF-M3X55/DR125 | M3x55 Standoff
Mounting | 1005005070119421 | M3x6 Hex Flat
Mounting | 32798773566 | M4 Nut
Mounting | 1005004048407401 | M4x16 Hex Countersunk
Mounting | 17H910 | Mounting Cube 10mm
Mounting | 1005001639359312 | Nut M2.5
Mounting | BM4009 | PG9 Cable Gland
Mounting | BM4809 | PG9 Cable Gland Nut
Rack | BGT VS1 | 19“ Front Plate Holder
Rack | MEN 3277.0883 | 19“ Rack Handle

https://www.lcsc.com
https://www.lcsc.com
https://www.lcsc.com
https://www.lcsc.com
https://www.lcsc.com
https://www.lcsc.com
https://www.lcsc.com
https://www.lcsc.com
https://www.lcsc.com
https://www.lcsc.com
https://www.lcsc.com
https://de.aliexpress.com
https://www.lcsc.com
https://de.aliexpress.com
https://de.aliexpress.com
https://de.aliexpress.com
https://de.aliexpress.com
https://de.aliexpress.com
https://de.aliexpress.com
https://de.aliexpress.com
https://de.aliexpress.com
https://de.aliexpress.com
https://de.aliexpress.com
https://www.tme.eu
https://www.tme.eu
https://de.aliexpress.com
https://de.aliexpress.com
https://de.aliexpress.com
https://www.buerklin.com
https://de.aliexpress.com
https://www.tme.eu
https://www.tme.eu
https://www.reichelt.de
https://www.reichelt.de

Parts

Seite 4

Rack | 71H225 | 19” module carrier guide rails
Rack | 71H205 | 19” module carrier threaded strips
Rack | BGT 384-180 | 19” Rack 3HE, 84TE, 178mm
Relay | C231374 | G5RL-1A-E-HR DC12 12V
Relay | C23510 | HFD4/5 5V DPDT
Resistor | C17477 | 0R 0805
Resistor | C3152217 | 10k 0805
Resistor | C17415 | 10R 0805
Resistor | C25280 | 120R 0805
Resistor | C17471 | 150R 0805
Resistor | C17513 | 1k 0805
Resistor | C3152182 | 1M 0805
Resistor | C17526 | 2k4 0805
Resistor | C2907340 | 680R 0805

https://www.buerklin.com
https://www.buerklin.com
https://www.reichelt.de
https://www.lcsc.com
https://www.lcsc.com
https://www.lcsc.com
https://www.lcsc.com
https://www.lcsc.com
https://www.lcsc.com
https://www.lcsc.com
https://www.lcsc.com
https://www.lcsc.com
https://www.lcsc.com
https://www.lcsc.com

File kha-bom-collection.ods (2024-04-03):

Type | ID | Provider | Description
Button | 1005002284607011 | https://de.aliexpress.com | PB86 Push Button Green / Red / Yellow
Button | KS01-BLV-2 | https://www.tme.eu | Push Button orange
Button | KS01-BLV-13 | https://www.tme.eu | Push Button red/green
Button | 1005005792983870 | https://de.aliexpress.com | Rectangle Momentary Push Button 6.3V Red / Yellow
Button | 1005004587725359 | https://de.aliexpress.com | Rectangle Momentary Push Button Cover
Button | PEC11R-4215F-S0024 | https://www.tme.eu | Rotary Encoder
Button | 1005004081506992 | https://de.aliexpress.com | Rotary Encoder Knob
Cable | 32998004363 | https://de.aliexpress.com | Flat Ribbon Cable 1.27 8P / 10P
Cable | 4001353071671 | https://de.aliexpress.com | PH 2.0 2P / 4P / 5P / 7P Cable 10cm
Cable | 4000058023349 | https://de.aliexpress.com | XH 2.54 3P Cable 20cm
Capacitor | C495959 | https://www.lcsc.com | 100nF 0805
Capacitor | C11375 | https://www.lcsc.com | 100uF 16V Case C 6032 TAJC107K016RNJ
Capacitor | C519909 | https://www.lcsc.com | 10nF 0805
Capacitor | C15850 | https://www.lcsc.com | 10uF 0805
Capacitor | C7216 | https://www.lcsc.com | 220uF 6.3V Case C 6032 TAJC227K006RNJ
Capacitor | C77101 | https://www.lcsc.com | 47uF 1210
Connector | C963713 | https://www.lcsc.com | DIN41612 32P
Connector | ML-C2 32W | https://www.reichelt.de | DIN41612 32P A-C C (ept: 103-90014)
Connector | FL-C2 32G4 | https://www.reichelt.de | DIN41612 32P A-C C (ept: 304-90014-01)
Connector | C492445 | https://www.lcsc.com | IDC 2x3 PCB Mount SMT
Connector | C601910 | https://www.lcsc.com | IDC 2x4 Crimp
Connector | C376157 | https://www.lcsc.com | IDC 2x4 Crimp PCB Mount
Connector | C8373 | https://www.lcsc.com | IDC 2x5 Crimp
Connector | 1005002322214396 | https://de.aliexpress.com | IDC 2x5 Crimp Reverse
Connector | C2977596 | https://www.lcsc.com | IDC 2x5 PCB Mount
Connector | C4749178 | https://www.lcsc.com | IDC 2x5 PCB Mount SMT
Connector | C131337 | https://www.lcsc.com | PH 2.0 2P
Connector | C160352 | https://www.lcsc.com | PH 2.0 2P SMT
Connector | C131334 | https://www.lcsc.com | PH 2.0 4P
Connector | C160354 | https://www.lcsc.com | PH 2.0 4P SMT
Connector | C157993 | https://www.lcsc.com | PH 2.0 5P
Connector | C157981 | https://www.lcsc.com | PH 2.0 7P
Connector | C492401 | https://www.lcsc.com | Pin Header 1x02 2.54
Connector | C49257 | https://www.lcsc.com | Pin Header 1x03 2.54
Connector | C2881656 | https://www.lcsc.com | Pin Header 1x11 1.27
Connector | 1005004301488282 | https://de.aliexpress.com | Pin Header 2.54 Multi Color
Connector | C2685136 | https://www.lcsc.com | Pin Header 2x02 2.54
Connector | C492420 | https://www.lcsc.com | Pin Header 2x03 2.54
Connector | C2935921 | https://www.lcsc.com | Pin Header 2x06 2.54
Connector | C124393 | https://www.lcsc.com | Pin Socket 1x12 1.27
Connector | TBG-5-PW-3P-GN | https://www.tme.eu | Pluggable Terminal 3P 5.08
Connector | TBW-5.08-3P | https://www.tme.eu | Pluggable Terminal 3P 5.08
Connector | 1005004748652065 | https://de.aliexpress.com | RJ45 Port IDC Straight
Connector | C708610 | https://www.lcsc.com | RJ45 THT
Connector | 926666961 | https://de.aliexpress.com | Screw Terminal 2P 5.08
Connector | 926666961 | https://de.aliexpress.com | Screw Terminal 3P 5.08
Connector | 105-0U | https://www.tme.eu | TAUR 105 Power Socket (green)
Connector | TAUR 105-0R | https://www.reichelt.de | TAUR 105 Power Socket (red, yellow, gray)
Connector | C1121883 | https://www.lcsc.com | TRS Audio Jack
Connector | C692438 | https://www.lcsc.com | TRS Audio Jack green
Connector | C2884943 | https://www.lcsc.com | TRS Audio Jack pink
Connector | 640-USB3076-30-A | https://www.mouser.de | USB Micro
Connector | C7429633 | https://www.lcsc.com | XH 2.54 3P
Fuse | C883096 | https://www.lcsc.com | BHFUSE BSMD0805-005-15V 50ma/150mA
Fuse | C883099 | https://www.lcsc.com | BHFUSE BSMD0805-010-15V 100mA/300mA
Fuse | C910823 | https://www.lcsc.com | BHFUSE BSMD0805-100-12V 1A/2A
IC | C2071056 | https://www.lcsc.com | AP63205WU-7
IC | C1339884 | https://www.lcsc.com | ATTINY402-SSN
IC | 494-AVR64DD32-I/PT | https://www.mouser.de | AVR64DD32 TQFP
IC | C99652 | https://www.lcsc.com | CH340E
IC | C102619 | https://www.lcsc.com | DMG2301L-7 P-Channel Mosfet
IC | C460977 | https://www.lcsc.com | DMG2302U
IC | C909754 | https://www.lcsc.com | MMBT3904
IC | C6855 | https://www.lcsc.com | SP485EEN-L/TR
IC | C19579 | https://www.lcsc.com | TM1620
IC | C181730 | https://www.lcsc.com | ULN2003A
Inductor | C703083 | https://www.lcsc.com | 1.6A 4.7uH ±20% 2.3A 157mΩ 1210
Jumper/Test | C5274550 | https://www.lcsc.com | Jumper blue
Jumper/Test | C5274548 | https://www.lcsc.com | Jumper red
Jumper/Test | C5274551 | https://www.lcsc.com | Jumper white
Jumper/Test | C5274549 | https://www.lcsc.com | Jumper yellow
Jumper/Test | C238127 | https://www.lcsc.com | Test Ring black
Jumper/Test | C2906765 | https://www.lcsc.com | Test Ring red
Jumper/Test | C238128 | https://www.lcsc.com | Test Ring yellow
LED | C98222 | https://www.lcsc.com | LED 0805 blue
LED | C98221 | https://www.lcsc.com | LED 0805 green
LED | C125091 | https://www.lcsc.com | LED 0805 yellow
LED | 1005001835638842 | https://de.aliexpress.com | SK6812 RGBWW
LED | C225881 | https://www.lcsc.com | SUNLIGHT SLR0282BH2C1BD-6.6
Module | 1005003575010329 | https://de.aliexpress.com | Bluetooth Module
Module | 1005004210325836 | https://de.aliexpress.com | POE Injector 12V 2A
Module | 1005006327593563 | https://de.aliexpress.com | IR Transmitter
Module | 4000905994833 | https://de.aliexpress.com | 433Mhz RF Transmitter
Mounting | 1005005070119421 | https://de.aliexpress.com | M2.5x10 Hex Flat
Mounting | 1005005070119421 | https://de.aliexpress.com | M2.5x6 Hex Flat
Mounting | 32798773566 | https://de.aliexpress.com | M3 Nut
Mounting | 1005005070119421 | https://de.aliexpress.com | M3x12 Hex Flat
Mounting | 1005004048407401 | https://de.aliexpress.com | M3x14 Hex Countersunk
Mounting | 1005006060186972 | https://de.aliexpress.com | M3x14 Standoff
Mounting | TFM-M3X5/DR213 | https://www.tme.eu | M3x5 Standoff
Mounting | TFF-M3X55/DR125 | https://www.tme.eu | M3x55 Standoff
Mounting | 1005005070119421 | https://de.aliexpress.com | M3x6 Hex Flat
Mounting | 32798773566 | https://de.aliexpress.com | M4 Nut
Mounting | 1005004048407401 | https://de.aliexpress.com | M4x16 Hex Countersunk
Mounting | 17H910 | https://www.buerklin.com | Mounting Cube 10mm
Mounting | 1005001639359312 | https://de.aliexpress.com | Nut M2.5
Mounting | BM4009 | https://www.tme.eu | PG9 Cable Gland
Mounting | BM4809 | https://www.tme.eu | PG9 Cable Gland Nut
Rack | BGT VS1 | https://www.reichelt.de | 19“ Front Plate Holder
Rack | MEN 3277.0883 | https://www.reichelt.de | 19“ Rack Handle
Rack | 71H225 | https://www.buerklin.com | 19” module carrier guide rails
Rack | 71H205 | https://www.buerklin.com | 19” module carrier threaded strips
Rack | BGT 384-180 | https://www.reichelt.de | 19” Rack 3HE, 84TE, 178mm
Relay | C231374 | https://www.lcsc.com | G5RL-1A-E-HR DC12 12V
Relay | C23510 | https://www.lcsc.com | HFD4/5 5V DPDT
Resistor | C17477 | https://www.lcsc.com | 0R 0805
Resistor | C3152217 | https://www.lcsc.com | 10k 0805
Resistor | C17415 | https://www.lcsc.com | 10R 0805
Resistor | C25280 | https://www.lcsc.com | 120R 0805
Resistor | C17471 | https://www.lcsc.com | 150R 0805
Resistor | C17513 | https://www.lcsc.com | 1k 0805
Resistor | C3152182 | https://www.lcsc.com | 1M 0805
Resistor | C17526 | https://www.lcsc.com | 2k4 0805
Resistor | C2907340 | https://www.lcsc.com | 680R 0805

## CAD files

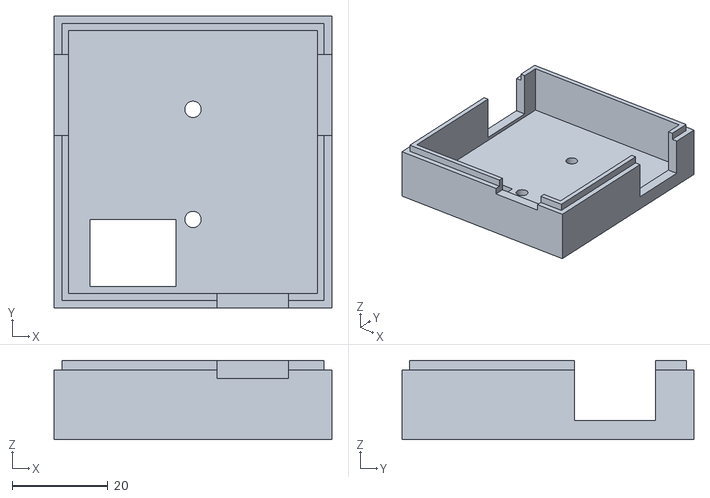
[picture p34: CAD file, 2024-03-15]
kha-nodes/kha-main/kha-main-node-enclosure-top.stl
58.0 x 61.0 x 16.6

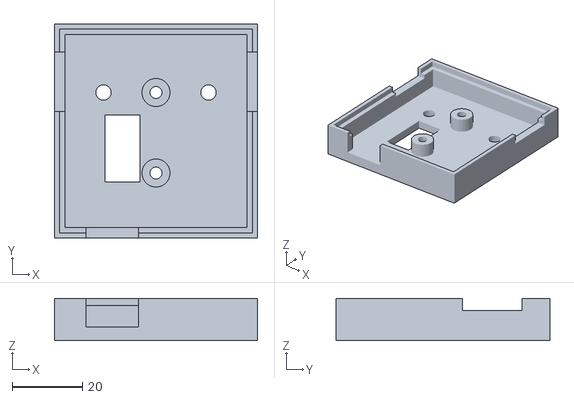
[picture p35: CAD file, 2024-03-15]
kha-nodes/kha-main/kha-main-node-enclosure-bottom.stl
58.0 x 61.0 x 12.0

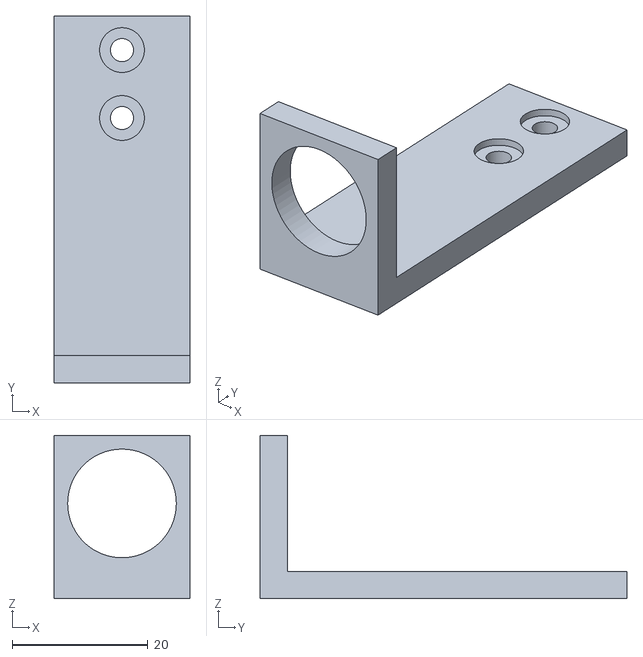
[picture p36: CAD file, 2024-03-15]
kha-nodes/kha-main/kha-main-mount.stl
20.0 x 54.0 x 24.0

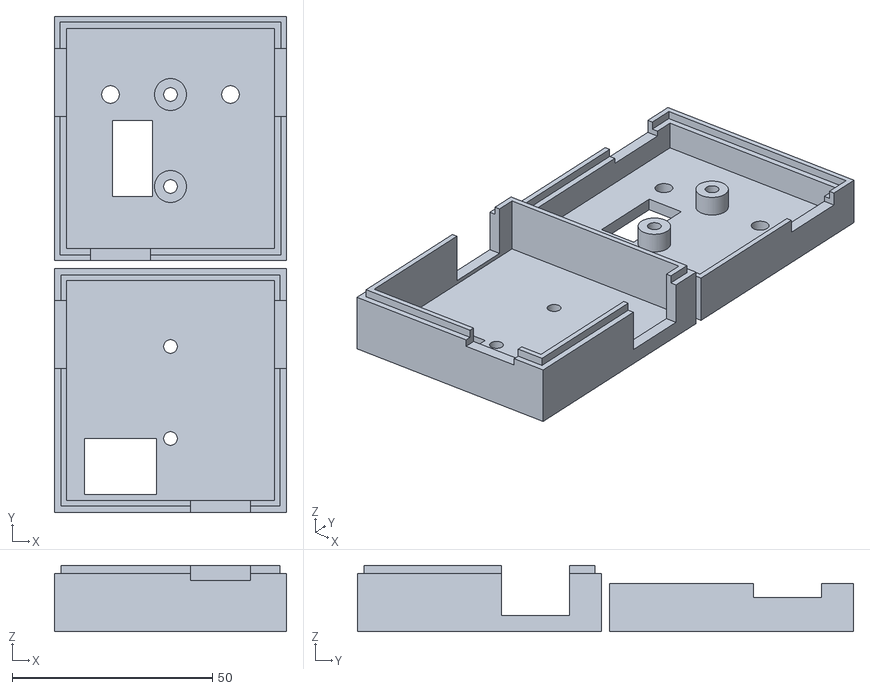
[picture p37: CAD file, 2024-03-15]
kha-nodes/kha-main/kha-main-node-enclosure.stl
58.0 x 124.0 x 16.6

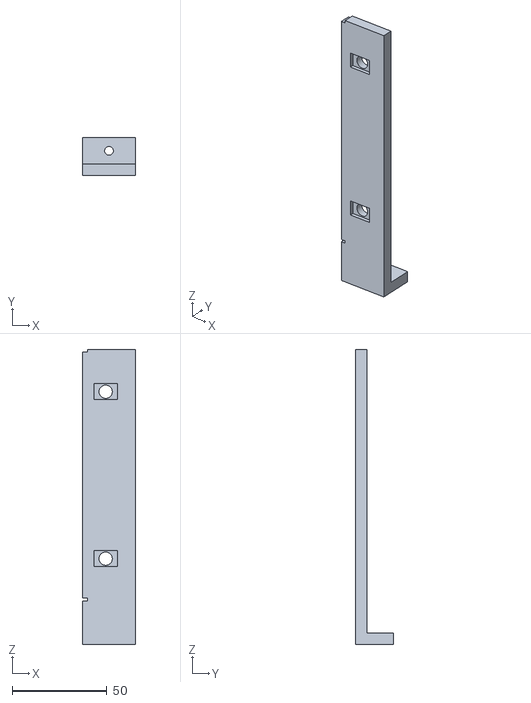
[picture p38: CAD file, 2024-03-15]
kha-bgt-rack/kha-rack-shelf-mount_right.stl
27.8 x 20.0 x 155.5

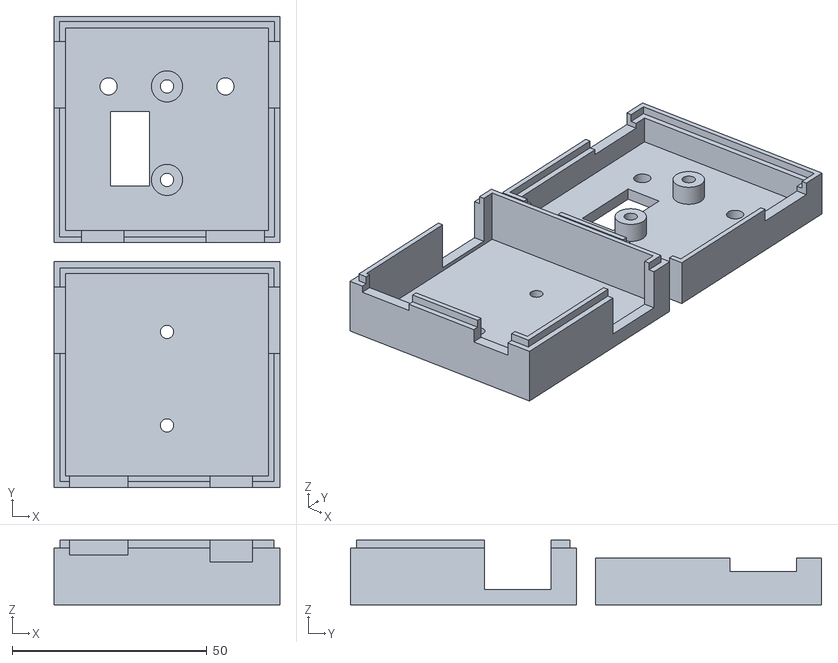
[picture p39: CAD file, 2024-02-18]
kha-nodes/kha-gateway-usb/kha-gateway-usb-enclosure.stl
58.0 x 121.0 x 16.6

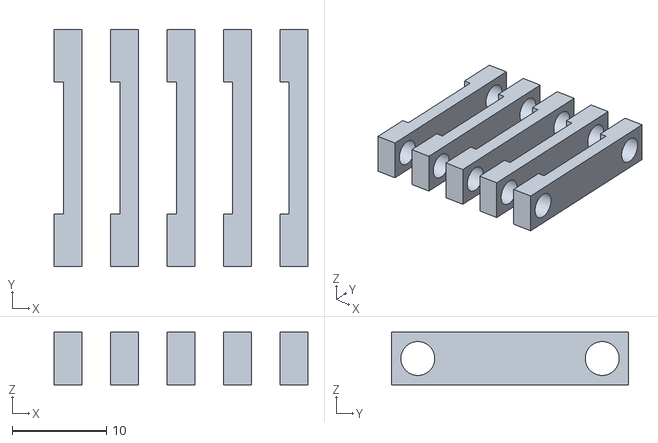
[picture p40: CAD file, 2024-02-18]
kha-nodes/kha-led-ikea/kha-led-ikea-lighting/kha-led-ikea-clip.stl
27.0 x 25.2 x 5.60

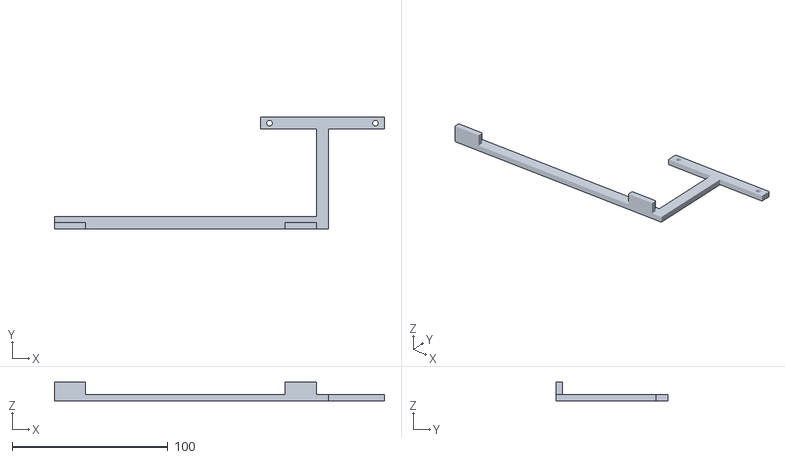
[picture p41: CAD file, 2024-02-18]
kha-nodes/kha-led-ikea/kha-led-ikea-lighting/kha-led-ikea-kallax/kha-led-ikea-kallax-drillguide.stl
211.8 x 71.6 x 12.0

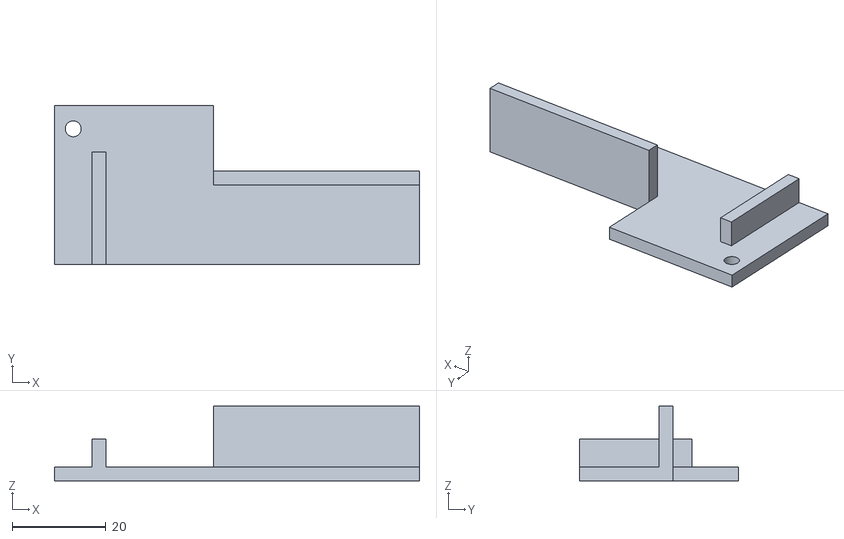
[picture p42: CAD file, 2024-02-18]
kha-nodes/kha-led-ikea/kha-led-ikea-lighting/kha-led-ikea-oxberg40/kha-led-ikea-oxberg40-drillguide.stl
78.0 x 34.0 x 16.0

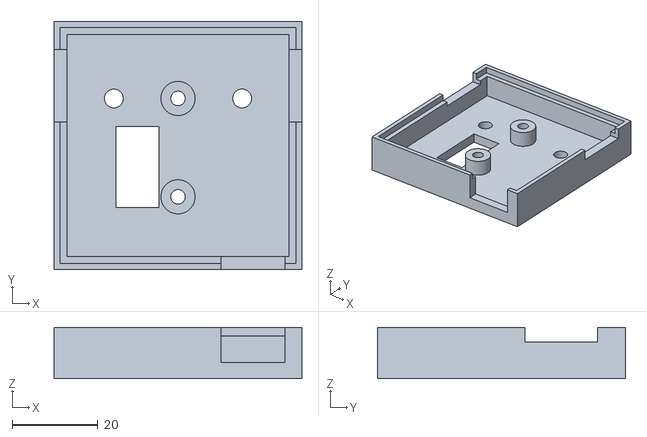
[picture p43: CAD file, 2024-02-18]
kha-nodes/kha-led-ikea/kha-led-ikea-node/kha-led-ikea-node-enclosure-bottom.stl
58.0 x 58.0 x 12.0

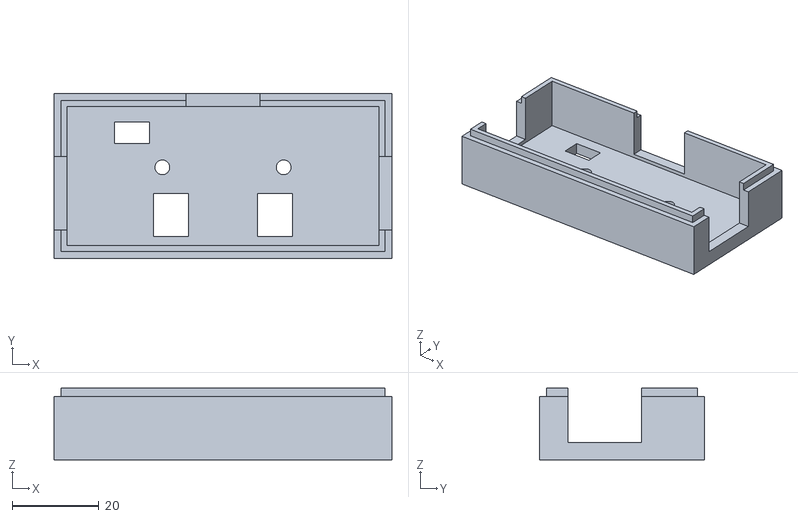
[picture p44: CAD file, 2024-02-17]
kha-nodes/kha-pwr-rj45/kha-pwr-rj45-enclosure-top.stl
78.0 x 38.0 x 16.6

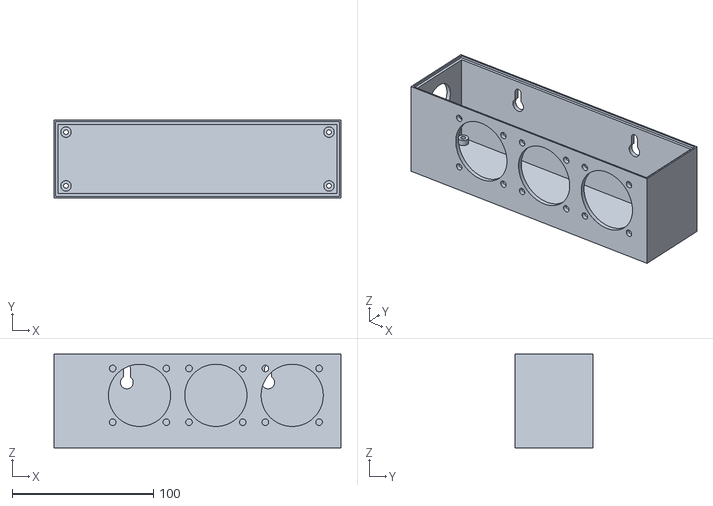
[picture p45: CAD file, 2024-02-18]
kha-nodes/kha-relay-2x3/kha-relay-2x3-box/kha-relay-2x3-enclosure.stl
203.0 x 55.0 x 66.2

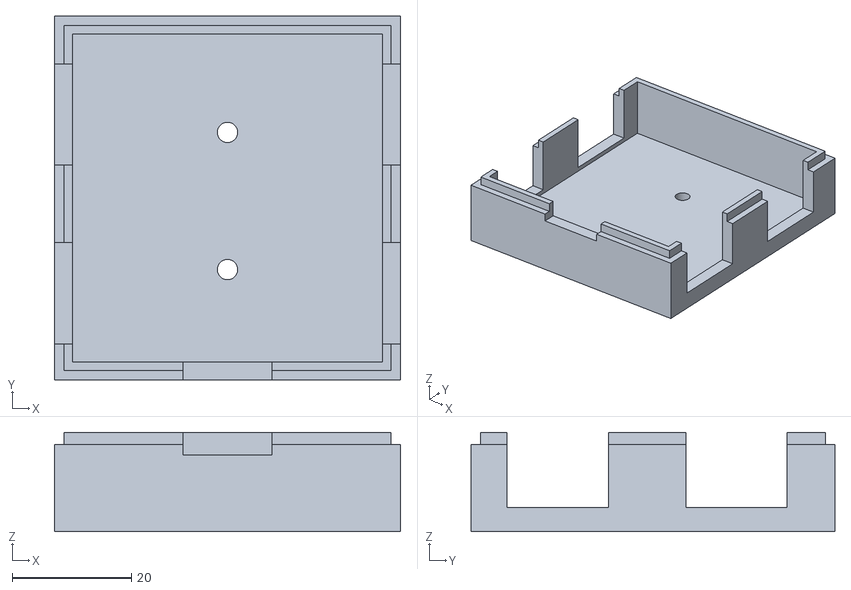
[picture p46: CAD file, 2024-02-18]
kha-nodes/kha-relay-2x3/kha-relay-2x3-node/kha-relay-2x3-node-enclosure-top.stl
58.0 x 61.0 x 16.6

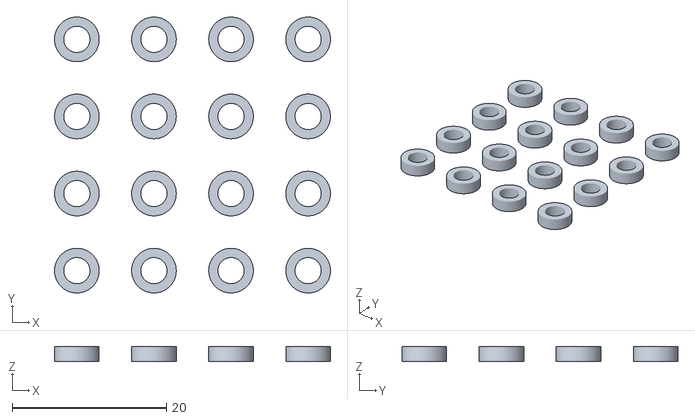
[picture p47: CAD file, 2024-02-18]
kha-nodes/kha-led-ikea/kha-led-ikea-lighting/kha-led-ikea-oxberg40/kha-led-ikea-oxberg40-spacer.stl
35.8 x 35.8 x 2.00

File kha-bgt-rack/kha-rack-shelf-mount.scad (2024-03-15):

$fn = 60;

t = 6;

rack_w = 27.8;
rack_l = 132.5;

rack_c_w = 2.5;
rack_c_l = 1.4;

rack_h_distance = 88;
rack_h_offset_w = 12.15;
rack_h_offset_l = 22.25;
rack_h_dia = 7;

shelf_l = 17;
shelf_d = 14;
shelf_h_dia = 4.6;

module main_left() {
difference() {
    cube([rack_w, t, rack_l]);
    translate([rack_w - rack_c_w, 0, 0]) cube([rack_c_w, t, rack_c_l]);
    translate([rack_w - rack_c_w, 0, rack_l - rack_c_l]) cube([rack_c_w, t, rack_c_l]);
    translate([rack_w - rack_h_offset_w, 0, rack_h_offset_l]) {
        rotate([-90, 0, 0]) cylinder(h = t, d = rack_h_dia);
        translate([-12.4 / 2, 0, -8.4 / 2]) cube([12.4, 2, 8.4]);
        translate([0, 0, rack_h_distance]) {
            rotate([-90, 0, 0]) cylinder(h = t, d = rack_h_dia);
            translate([-12.4 / 2, 0, -8.4 / 2]) cube([12.4, 2, 8.4]);
        }
    }
}

translate([0, 0, -shelf_l]) {		
    cube([rack_w, t, shelf_l]);
}

translate([0, 0, -shelf_l - t]) {
    difference() {
        cube([rack_w, t + shelf_d, t]);
        translate([rack_w / 2, t + shelf_d / 2, 0]) cylinder(h = t, d = shelf_h_dia);
        translate([rack_w / 2, t + shelf_d / 2, 0]) cylinder(h = 2, d = shelf_h_dia * 2);
    }
}
}

module main_right() {
difference() {
    cube([rack_w, t, rack_l]);
    translate([0, 0, 0]) cube([rack_c_w, t, rack_c_l]);
    translate([0, 0, rack_l - rack_c_l]) cube([rack_c_w, t, rack_c_l]);
    translate([rack_h_offset_w, 0, rack_h_offset_l]) {
        rotate([-90, 0, 0]) cylinder(h = t, d = rack_h_dia);
        translate([-12.4 / 2, 0, -8.4 / 2]) cube([12.4, 2, 8.4]);
        translate([0, 0, rack_h_distance]) {
            rotate([-90, 0, 0]) cylinder(h = t, d = rack_h_dia);
            translate([-12.4 / 2, 0, -8.4 / 2]) cube([12.4, 2, 8.4]);
        }
    }
}

translate([0, 0, -shelf_l]) {		
    cube([rack_w, t, shelf_l]);
}

translate([0, 0, -shelf_l - t]) {
    difference() {
        cube([rack_w, t + shelf_d, t]);
        translate([rack_w / 2, t + shelf_d / 2, 0]) cylinder(h = t, d = shelf_h_dia);
        translate([rack_w / 2, t + shelf_d / 2, 0]) cylinder(h = 2, d = shelf_h_dia * 2);
    }
}
}

translate([-20, 0, 0]) main_left();
translate([ 20, 0, 0]) main_right();

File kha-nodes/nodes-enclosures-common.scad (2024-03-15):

$fn = $preview?6:60;

t = 3;

pcb_spacing = 1;
pcb_standoff = 5;

h = pcb_standoff + 1.6 + 14;
outer_w = t + pcb_spacing + pcb_w + pcb_spacing + t;
outer_l = t + pcb_spacing + pcb_l + pcb_spacing + t;
outer_h = t + h + t;   

cut = t + pcb_standoff + 2;
lip = 2;

module box() {
	difference() {
        cube([outer_w, outer_l, outer_h]);
        translate([t, t, t]) cube([pcb_spacing + pcb_w + pcb_spacing, pcb_spacing + pcb_l + pcb_spacing, h]);
    }
}

module standoffs_vert(spacing) {
	translate([outer_w / 2, outer_l/2, 0]) { 
            translate([0, 11, t]) {
				cylinder(h = pcb_standoff, d = 8);
				translate([0, -spacing, 0]) cylinder(h = pcb_standoff, d = 8);
			}
	}
}

module standoffs_vert_holes(spacing) {
	translate([outer_w / 2, outer_l/2, 0]) { 
            translate([0, 11, 0]) {
				cylinder(h = outer_h, d = 3.4);
				cylinder(h = 5.4, d = 6.4, $fn=6);
				translate([0, -spacing, 0]) {
					cylinder(h = outer_h, d = 3.4);
					cylinder(h = 5.4, d = 6.4, $fn=6);
				}
			}
	}
}

module standoffs_horiz(offset, spacing) {
	translate([outer_w / 2, outer_l/2 + offset, t]) { 
            translate([-spacing/2, 0, 0]) cylinder(h = pcb_standoff, d = 8);
			translate([+spacing/2, 0, 0]) cylinder(h = pcb_standoff, d = 8);
	}
}

module standoffs_horiz_holes(offset, spacing) {
	translate([outer_w / 2, outer_l/2 + offset, 0]) { 
		translate([-spacing/2, 0, 0]) cylinder(h = outer_h, d = 3.4);
		translate([-spacing/2, 0, 0]) cylinder(h = 5.4, d = 6.4, $fn=6);
		
		translate([+spacing/2, 0, 0]) cylinder(h = outer_h, d = 3.4);
		translate([+spacing/2, 0, 0]) cylinder(h = 5.4, d = 6.4, $fn=6);
	}
}

module wall_mount(spacing, y) {
	translate([outer_w / 2, outer_l/2, 0]) { 
            translate([0, y, 0]) {                            
				translate([-spacing/2, 0, 0]) {
					cylinder(h = t, d = 4.4);
					translate([spacing, 0, 0]) cylinder(h = t, d = 4.4);
				}
            }
        }
}

module socket(y) {
    translate([outer_w / 2, outer_l/2, 0]) { 
        translate([-outer_w/2, -17/2 + y, t + pcb_standoff + 1.6 + 12/2 - 14/2]) cube([outer_w, 17, 14]);
    }
}

module socket_center() {
    translate([outer_w / 2 - 17/2, outer_l - t, t + pcb_standoff + 1.6 + 12/2 - 14/2]) cube([17, t, 14]);
}

module eavr(x) {
    translate([outer_w / 2, 0, 0]) { 
       translate([-15/2 + x, 0, t + pcb_standoff + 1.6/2 - 10/2]) cube([15, t , 10]);
    }
}

module usb(x) {
    translate([outer_w / 2, 0, 0]) { 
        translate([-11/2 + x, 0, t + pcb_standoff + 1.6 + 3/2 - 9/2]) cube([11, t, 9]);
    }
}

module ident () {
    translate([outer_w / 2, outer_l/2, 0]) { 
        translate([-10/2 - 9.5, -19/2 - 5, 0]) cube([10, 19, t]);
    }
}

module jumper1(offset_x, offset_y) {
    translate([outer_w / 2 + offset_x, outer_l/2 + offset_y, outer_h-t]) { 
        translate([-8/2, -5/2, 0]) cube([8, 5, t]);
    }
}

module jumper3(offset_x, offset_y) {
    translate([outer_w / 2 + offset_x, outer_l/2 + offset_y, outer_h-t]) { 
        translate([-8/2, -10/2, 0]) cube([8, 10, t]);
    }
}

module idc(x) {
    translate([outer_w / 2, outer_l/2, 0]) { 
        translate([-22/2 + x, -12/2 - 20, outer_h - t]) cube([22, 12, t]);
    }
}
module terminal(x, y, w, l) {       
    translate([outer_w / 2 -w/2 + x, outer_l/2 -l/2 + y, t + pcb_standoff + 1.6]) cube([w, l, outer_h]);    
}

module terminal_front(x, y, w, l) {
    l2 = outer_l / 2 - y + l/2;    
    translate([outer_w / 2 -w/2 + x, 0, t + pcb_standoff + 1.6]) cube([w, l2, outer_h]);    
}

module slice_bottom() {
	translate([0, outer_w + 5, 0]) difference() {
		complete();
		translate([0, 0, cut + lip]) cube([outer_w, outer_l, outer_h]);
		
		s = (t/2) - 0.1;
		translate([s, s, cut]) cube([outer_w - s * 2, outer_l - s * 2, outer_h]);
	}
}

module slice_top() {
	translate([outer_w, 0, outer_h]) rotate([0, 180, 0]) difference() {	
		complete();
		translate([0, 0, 0]) cube([outer_w, outer_l, cut]);
		
		s = (t/2) + 0.1;
		translate([0, 0, 0]) cube([s, outer_l, cut + lip]);
		translate([outer_w - s, 0, 0]) cube([s, outer_l, cut + lip]);
		translate([0, 0, 0]) cube([outer_w, s, cut + lip]);
		translate([0, outer_l - s, 0]) cube([outer_w, s, cut + lip]);
	}
}

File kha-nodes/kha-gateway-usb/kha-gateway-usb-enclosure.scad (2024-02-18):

pcb_w = 50;
pcb_l = 50;
pcb_standoff_spacing = 24;
    
include <../nodes-enclosures-common.scad>

module complete() {
    difference() {
        union() {
            difference() {
                box(pcb_standoff_spacing);
                wall_mount(30, 11);
                ident();
                socket(14);
                eavr(17.5);
                usb(-16.5);
            }
            standoffs_vert(pcb_standoff_spacing);
        }
        standoffs_vert_holes(pcb_standoff_spacing);
    }
}

slice_top();
slice_bottom();

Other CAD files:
kha-nodes/kha-led-strip/kha-led-strip-node-enclosure.stl
kha-nodes/kha-remote/kha-remote-node-enclosure-bottom.stl
kha-bgt-rack/kha-rack-shelf-mount_left.stl
kha-nodes/kha-gateway-usb/kha-gateway-usb-enclosure-bottom.stl
kha-nodes/kha-led-strip/kha-led-strip-node-enclosure.scad
kha-nodes/kha-gateway-usb/kha-gateway-usb-enclosure-top.stl
kha-nodes/kha-led-ikea/kha-led-ikea-lighting/kha-led-ikea-clip.scad
kha-nodes/kha-led-ikea/kha-led-ikea-lighting/kha-led-ikea-kallax/kha-led-ikea-kallax-drillguide.scad
kha-nodes/kha-led-ikea/kha-led-ikea-lighting/kha-led-ikea-oxberg40/kha-led-ikea-oxberg40-drillguide.scad
kha-nodes/kha-led-ikea/kha-led-ikea-lighting/kha-led-ikea-oxberg40/kha-led-ikea-oxberg40-spacer.scad
kha-nodes/kha-led-ikea/kha-led-ikea-node/kha-led-ikea-node-enclosure-top.stl
kha-nodes/kha-led-ikea/kha-led-ikea-node/kha-led-ikea-node-enclosure.scad
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

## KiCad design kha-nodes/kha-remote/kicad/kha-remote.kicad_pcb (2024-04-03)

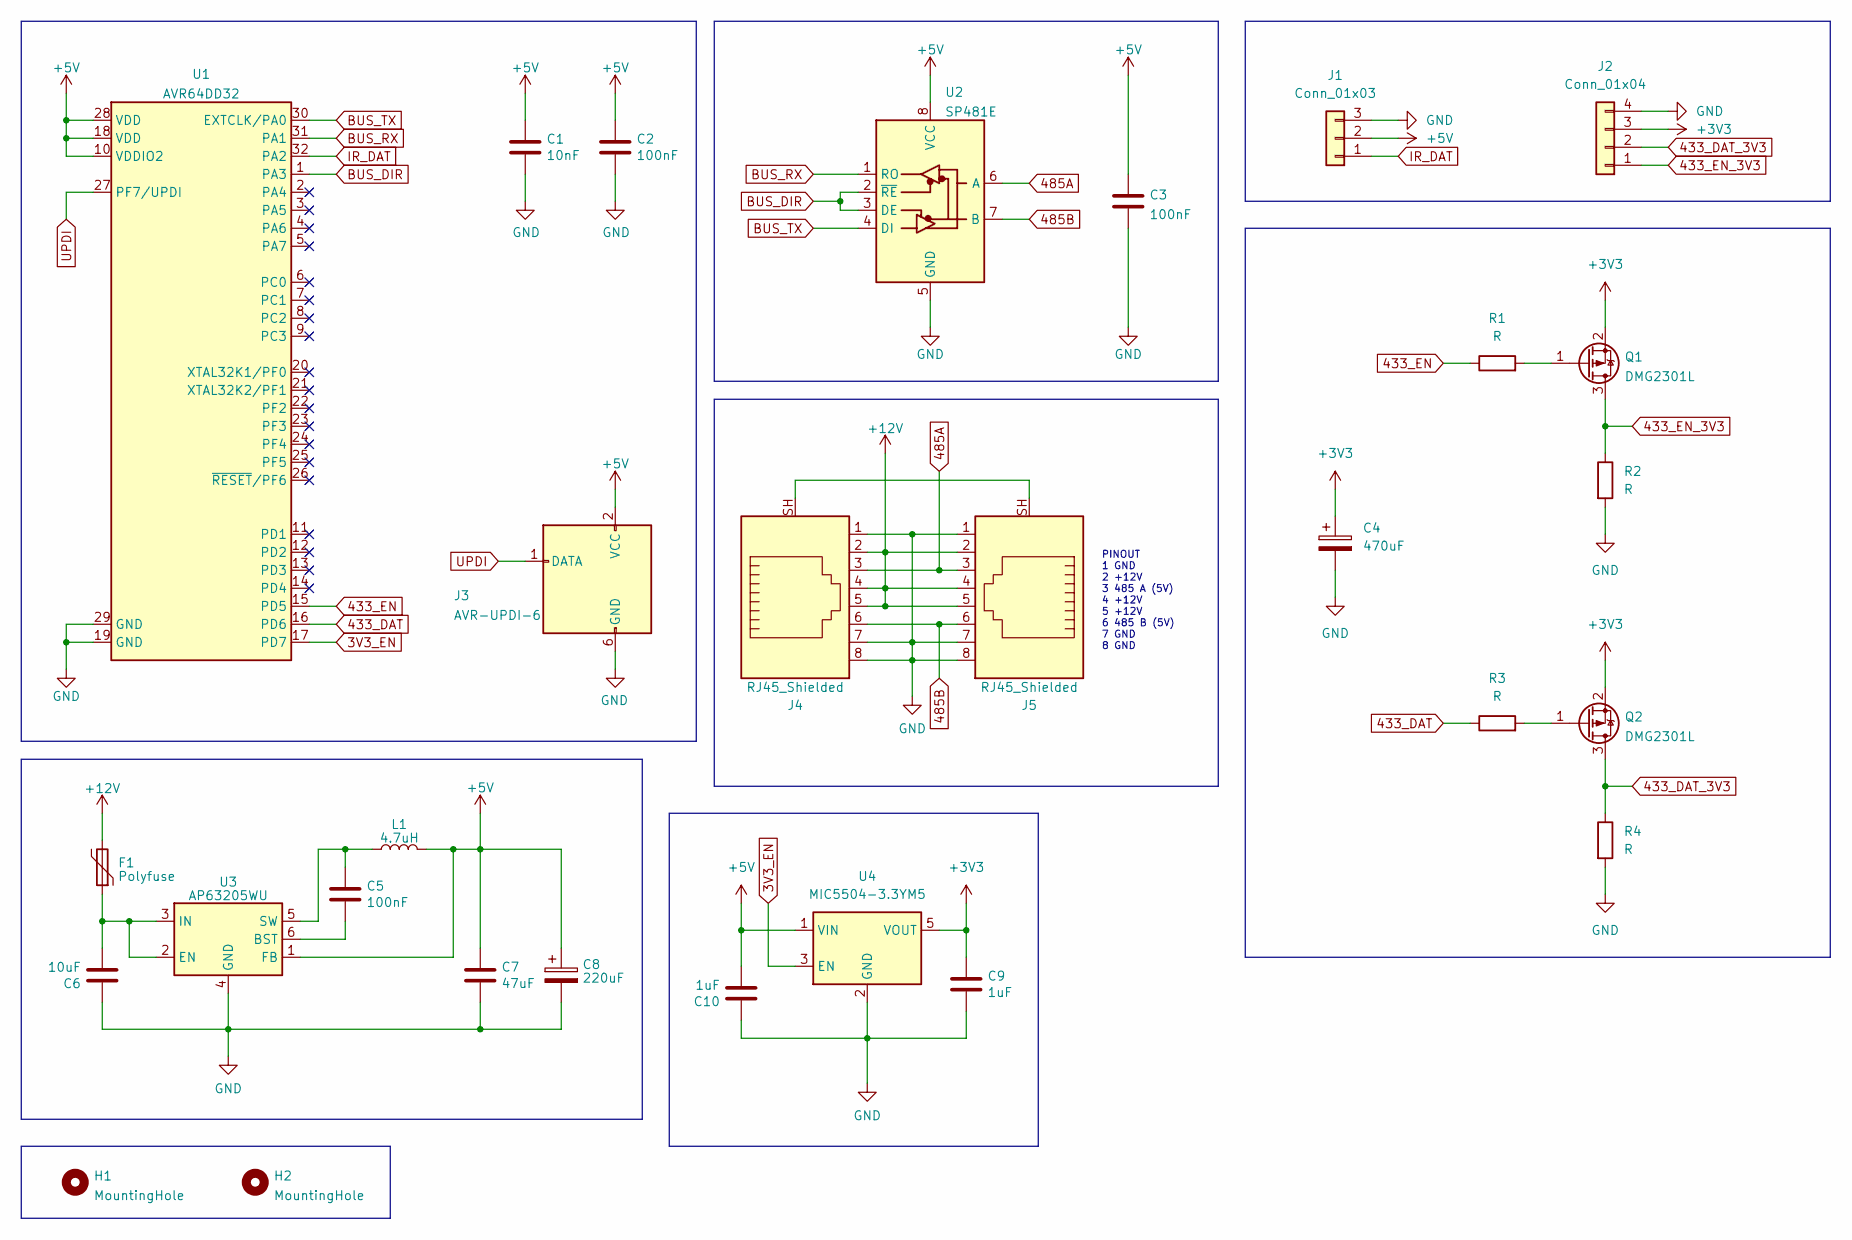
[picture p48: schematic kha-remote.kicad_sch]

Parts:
C1: 10nF; C_0805_2012Metric
C2, C3, C5: 100nF; C_0805_2012Metric
C4: 470uF; CP_Elec_6.3x7.7
C6: 10uF; C_0805_2012Metric
C7: 47uF; C_1210_3225Metric
C8: 220uF; CP_EIA-6032-28_Kemet-C
C9, C10: 1uF; C_0805_2012Metric
F1: Polyfuse; Fuse_0805_2012Metric
H1, H2: MountingHole; MountingHole_3.2mm_M3_DIN965
J1: Conn_01x03; TerminalBlock_Phoenix_MKDS-1,5-3-5.08_1x03_P5.08mm_Horizont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
J2: Conn_01x04; PinSocket_1x04_P2.54mm_Vertical
J3: AVR-UPDI-6; eAVR6-UPDI-F
J4, J5: RJ45_Shielded; GDLX-S-88K
L1: 4.7uH; L_1210_3225Metric
Q1, Q2: DMG2301L; SOT-23
R1, R2, R3, R4: R; R_0805_2012Metric
U1: AVR64DD32; TQFP-32_7x7mm_P0.8mm
U2: SP481E; SOIC-8_3.9x4.9mm_P1.27mm
U3: AP63205WU; TSOT-23-6
U4: MIC5504-3.3YM5; SOT-23-5

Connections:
3V3_EN: U1.17 (PD7), U4.3 (EN)
433_DAT: R3.1, U1.16 (PD6)
433_DAT_3V3: J2.2, Q2.3 (D), R4.1
433_EN: R1.1, U1.15 (PD5)
433_EN_3V3: J2.1, Q1.3 (D), R2.1
485A: J4.3, J5.3, U2.6 (A)
485B: J4.6, J5.6, U2.7 (B)
+3V3: C4.1, C9.1, J2.3, Q1.2 (S), Q2.2 (S), U4.5 (VOUT)
+5V: C1.1, C2.1, C3.1, C7.1, C8.1, C10.2, J1.2, J3.2 (VCC), L1.2, U1.10 (VDDIO2), U1.18 (VDD), U1.28 (VDD), U2.8 (VCC), U3.1 (FB), U4.1 (VIN)
+12V: F1.2, J4.2, J4.4, J4.5, J5.2, J5.4, J5.5
BUS_DIR: U1.1 (PA3), U2.2 (~RE), U2.3 (DE)
BUS_RX: U1.31 (PA1), U2.1 (RO)
BUS_TX: U1.30 (EXTCLK/PA0), U2.4 (DI)
GND: C1.2, C2.2, C3.2, C4.2, C6.1, C7.2, C8.2, C9.2, C10.1, J1.3, J2.4, J3.6 (GND), J4.1, J4.7, J4.8, J5.1, J5.7, J5.8, R2.2, R4.2, U1.19 (GND), U1.29 (GND), U2.5 (GND), U3.4 (GND), U4.2 (GND)
IR_DAT: J1.1, U1.32 (PA2)
unnamed: J4.SH, J5.SH
unnamed: Q1.1 (G), R1.2
unnamed: Q2.1 (G), R3.2
unnamed: C5.2, U3.6 (BST)
unnamed: C6.2, F1.1, U3.2 (EN), U3.3 (IN)
unnamed: C5.1, L1.1, U3.5 (SW)
UPDI: J3.1 (DATA), U1.27 (PF7/UPDI)

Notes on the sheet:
PINOUT 1 GND 2 +12V 3 485 A (5V) 4 +12V 5 +12V 6 485 B (5V) 7 GND 8 GND

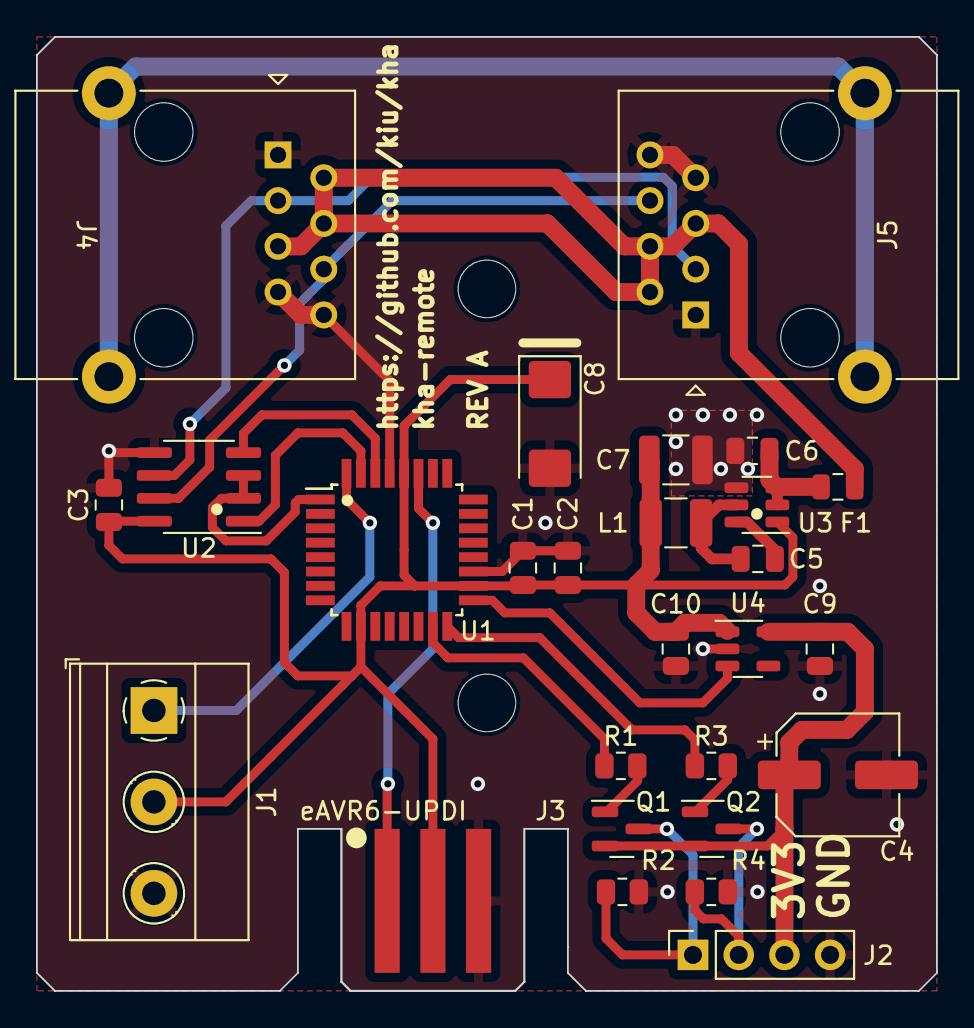
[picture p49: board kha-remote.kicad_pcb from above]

Board: 2 copper layers, 50.0 x 53.0 mm, 29 parts (0 on the bottom side), 22 nets.

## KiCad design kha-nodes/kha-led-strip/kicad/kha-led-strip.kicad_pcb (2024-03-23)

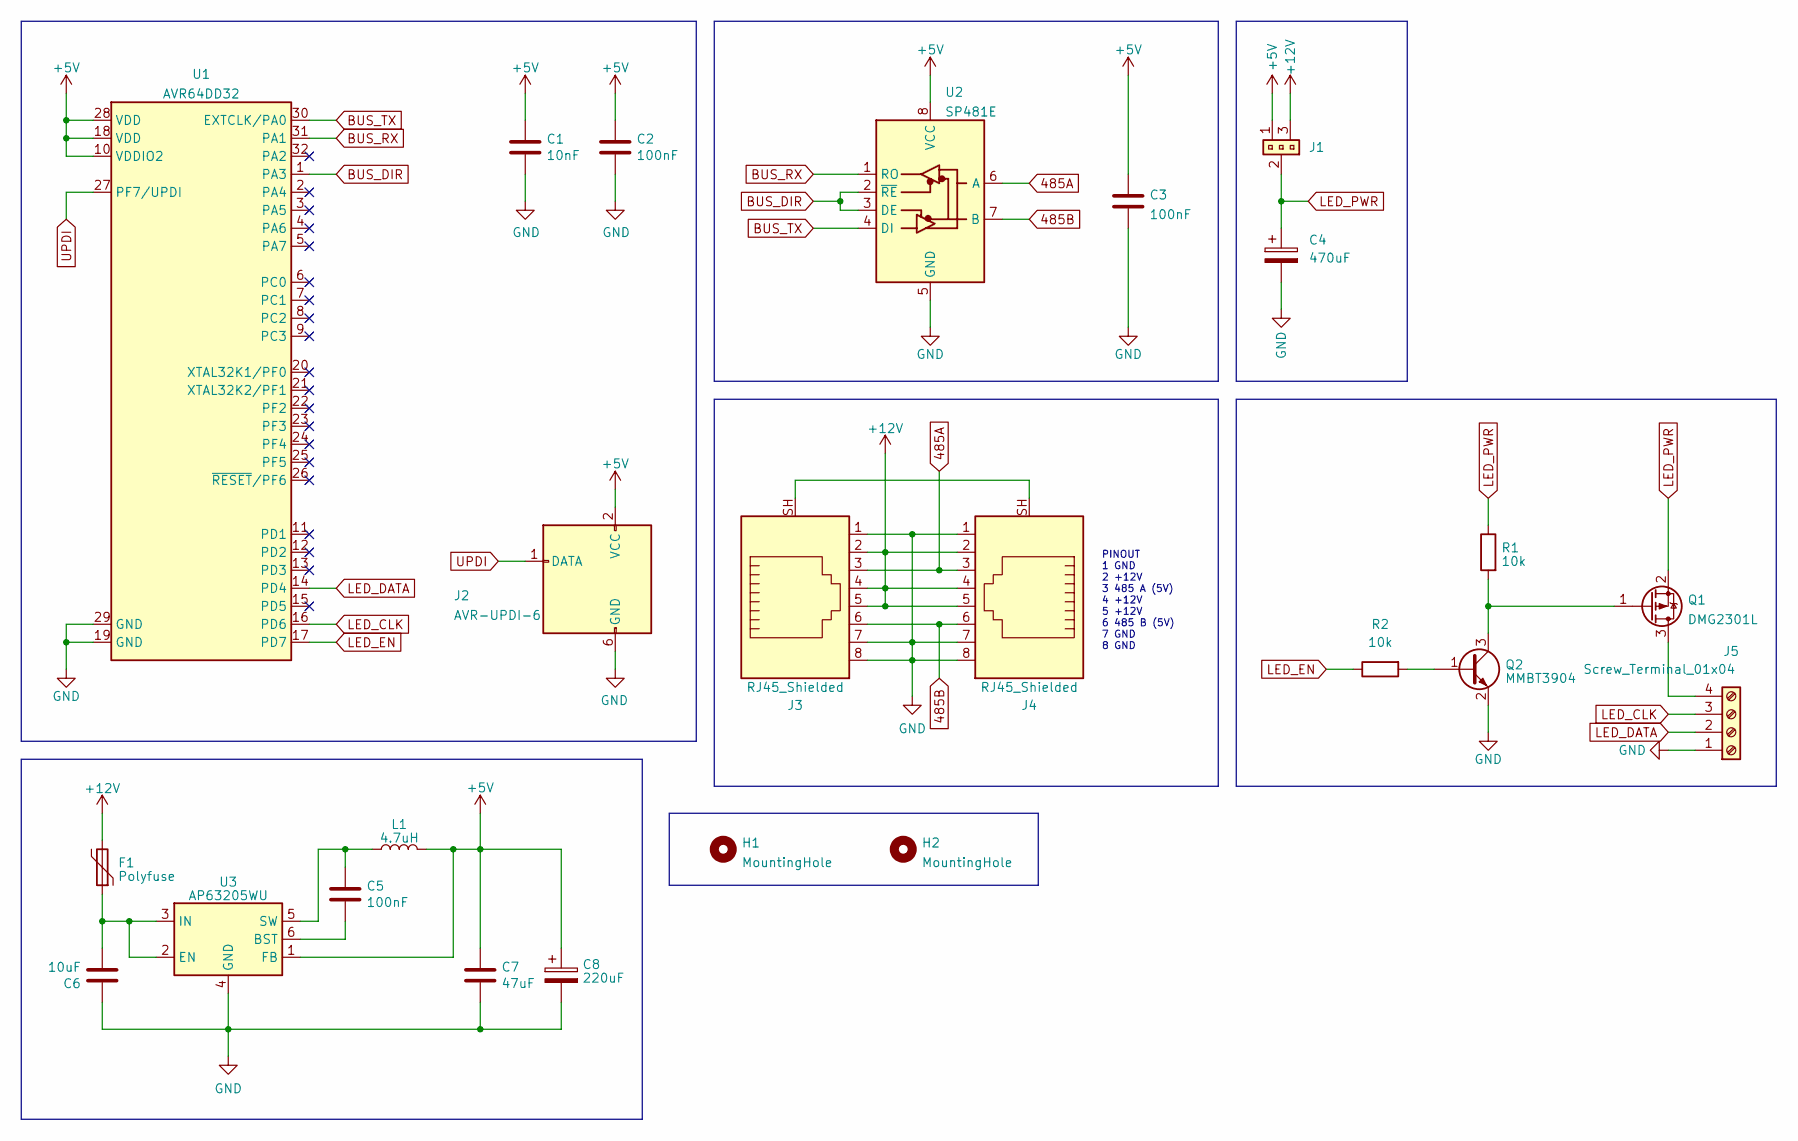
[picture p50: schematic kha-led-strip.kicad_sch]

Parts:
C1: 10nF; C_0805_2012Metric
C2, C3, C5: 100nF; C_0805_2012Metric
C4: 470uF; CP_Elec_8x10.5
C6: 10uF; C_0805_2012Metric
C7: 47uF; C_1210_3225Metric
C8: 220uF; CP_EIA-6032-28_Kemet-C
F1: Polyfuse; Fuse_0805_2012Metric
H1, H2: MountingHole; MountingHole_3.2mm_M3_DIN965
J1: 1x03_Jumper; PinHeader_1x03_P2.54mm_Vertical
J2: AVR-UPDI-6; eAVR6-UPDI-F
J3, J4: RJ45_Shielded; GDLX-S-88K
J5: Screw_Terminal_01x04; TerminalBlock_Phoenix_MKDS-1,5-4-5.08_1x04_P5.08mm_Horizont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
L1: 4.7uH; L_1210_3225Metric
Q1: DMG2301L; SOT-23
Q2: MMBT3904; SOT-23
R1, R2: 10k; R_0805_2012Metric
U1: AVR64DD32; TQFP-32_7x7mm_P0.8mm
U2: SP481E; SOIC-8_3.9x4.9mm_P1.27mm
U3: AP63205WU; TSOT-23-6

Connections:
485A: J3.3, J4.3, U2.6 (A)
485B: J3.6, J4.6, U2.7 (B)
+5V: C1.1, C2.1, C3.1, C7.1, C8.1, J1.1, J2.2 (VCC), L1.2, U1.10 (VDDIO2), U1.18 (VDD), U1.28 (VDD), U2.8 (VCC), U3.1 (FB)
+12V: F1.2, J1.3, J3.2, J3.4, J3.5, J4.2, J4.4, J4.5
BUS_DIR: U1.1 (PA3), U2.2 (~RE), U2.3 (DE)
BUS_RX: U1.31 (PA1), U2.1 (RO)
BUS_TX: U1.30 (EXTCLK/PA0), U2.4 (DI)
GND: C1.2, C2.2, C3.2, C4.2, C6.1, C7.2, C8.2, J2.6 (GND), J3.1, J3.7, J3.8, J4.1, J4.7, J4.8, J5.1, Q2.2 (E), U1.19 (GND), U1.29 (GND), U2.5 (GND), U3.4 (GND)
LED_CLK: J5.3, U1.16 (PD6)
LED_DATA: J5.2, U1.14 (PD4)
LED_EN: R2.1, U1.17 (PD7)
LED_PWR: C4.1, J1.2, Q1.2 (S), R1.1
unnamed: J3.SH, J4.SH
unnamed: J5.4, Q1.3 (D)
unnamed: Q1.1 (G), Q2.3 (C), R1.2
unnamed: Q2.1 (B), R2.2
unnamed: C5.2, U3.6 (BST)
unnamed: C6.2, F1.1, U3.2 (EN), U3.3 (IN)
unnamed: C5.1, L1.1, U3.5 (SW)
UPDI: J2.1 (DATA), U1.27 (PF7/UPDI)

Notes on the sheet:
PINOUT 1 GND 2 +12V 3 485 A (5V) 4 +12V 5 +12V 6 485 B (5V) 7 GND 8 GND

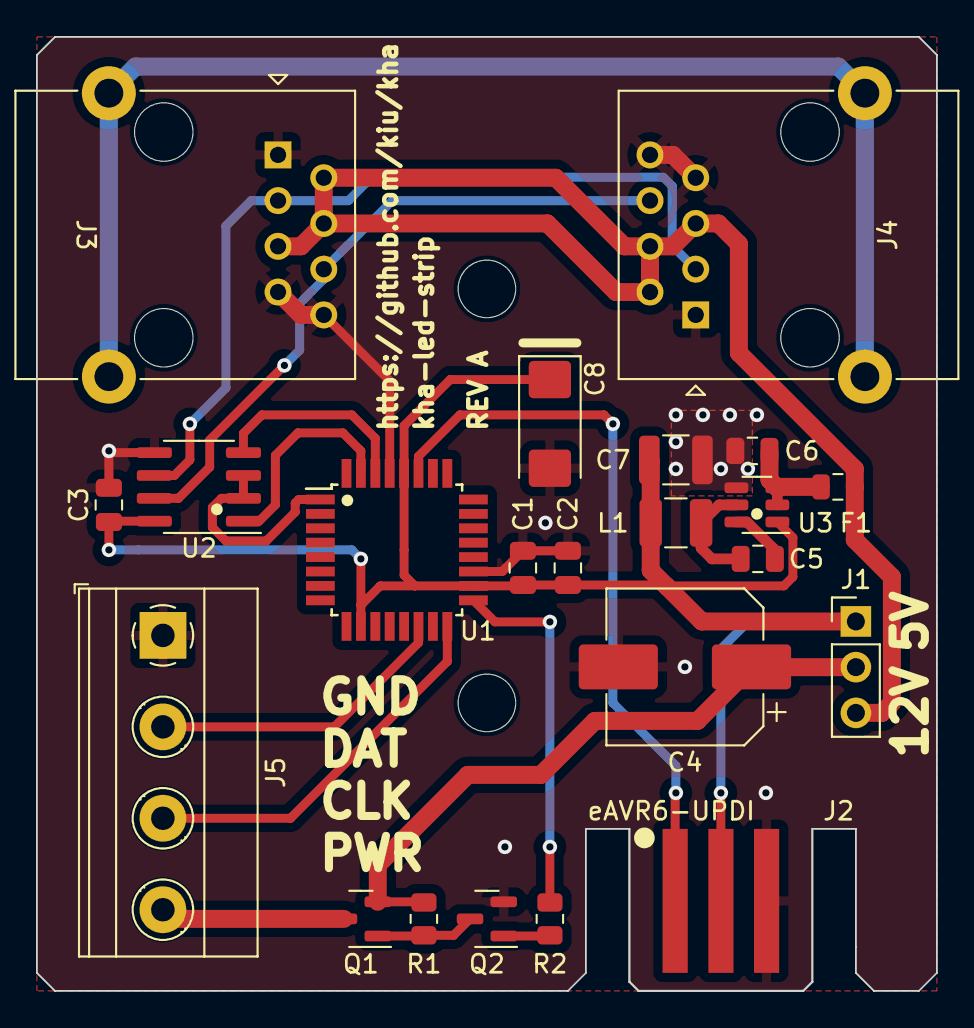
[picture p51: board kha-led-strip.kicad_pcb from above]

Board: 2 copper layers, 50.0 x 53.0 mm, 24 parts (0 on the bottom side), 20 nets.

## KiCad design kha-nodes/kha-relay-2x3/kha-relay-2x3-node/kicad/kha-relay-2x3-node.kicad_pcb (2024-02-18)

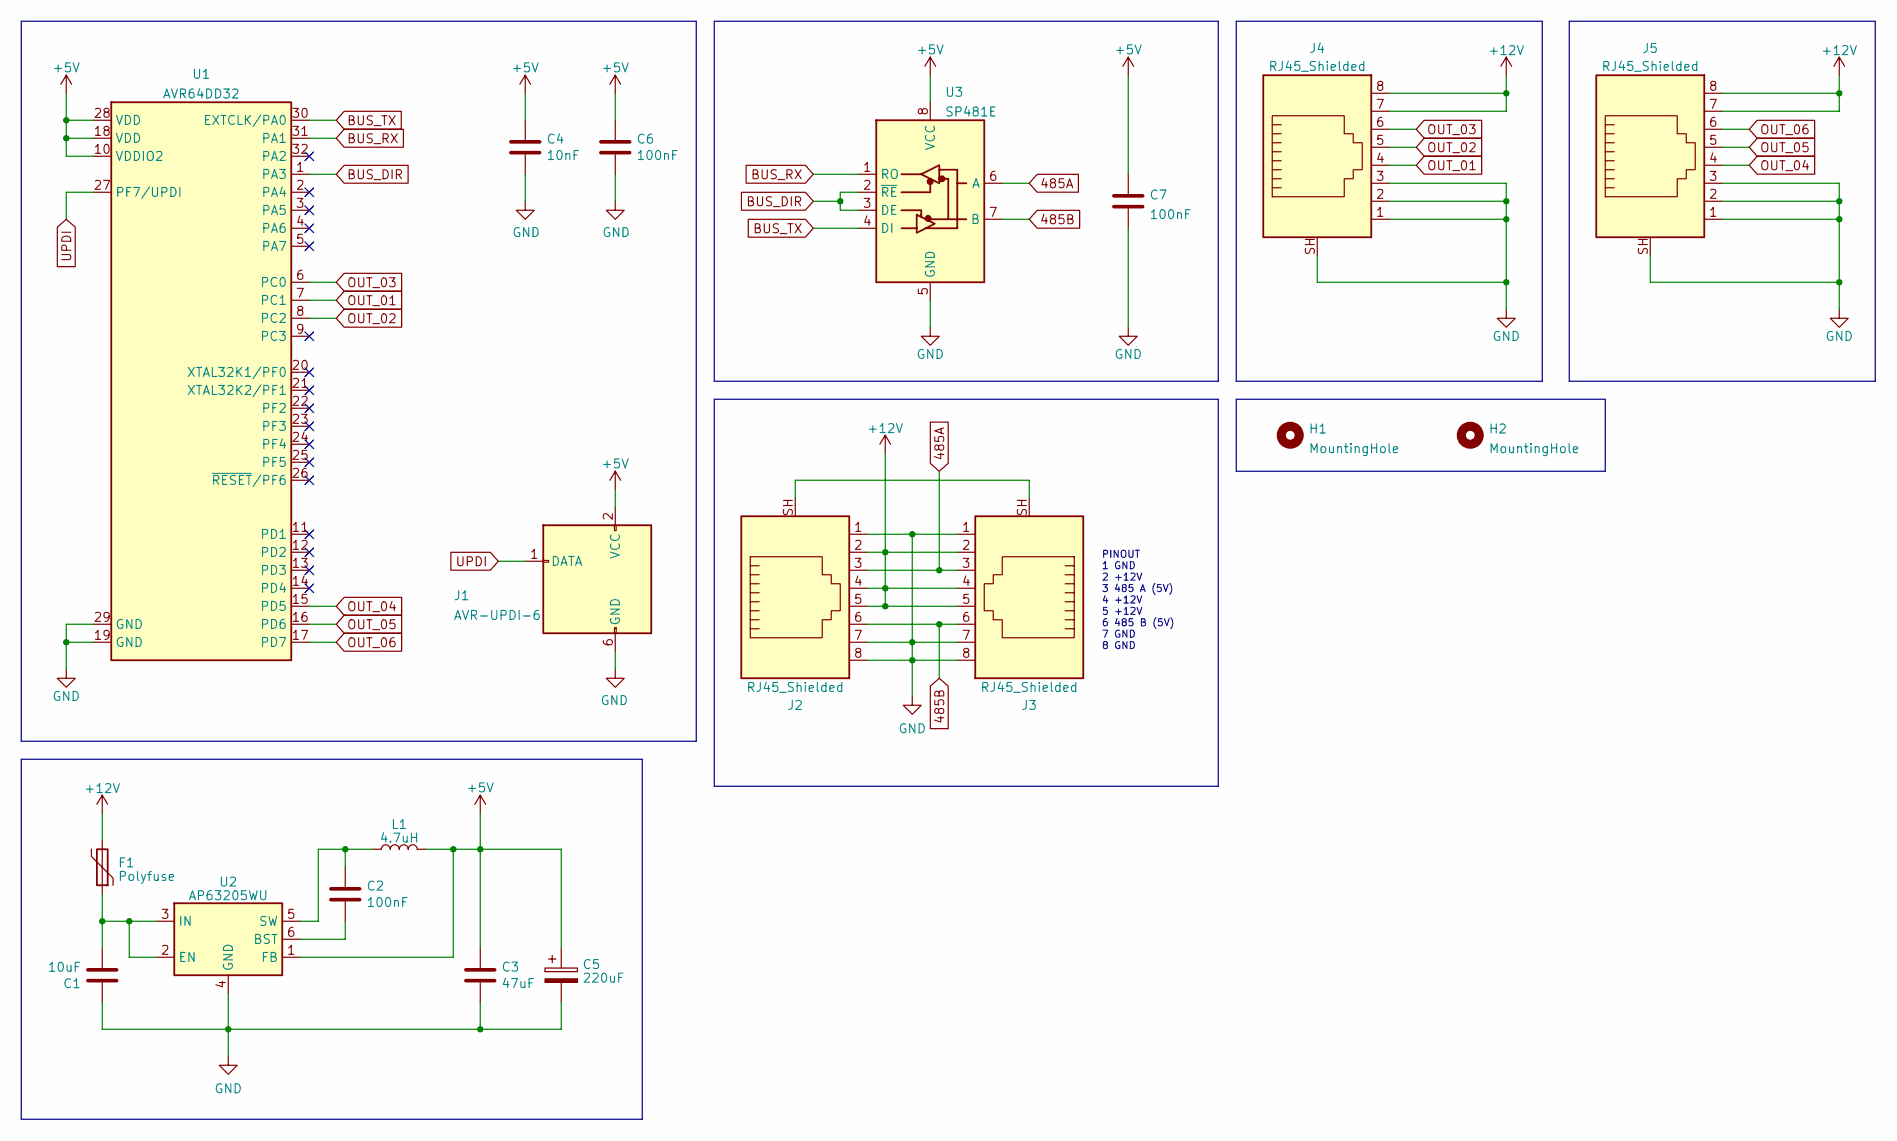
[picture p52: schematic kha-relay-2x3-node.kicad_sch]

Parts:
C1: 10uF; C_0805_2012Metric
C2, C6, C7: 100nF; C_0805_2012Metric
C3: 47uF; C_1210_3225Metric
C4: 10nF; C_0805_2012Metric
C5: 220uF; CP_EIA-6032-28_Kemet-C
F1: Polyfuse; Fuse_0805_2012Metric
H1, H2: MountingHole; MountingHole_3.2mm_M3_DIN965
J1: AVR-UPDI-6; eAVR6-UPDI-F
J2, J3, J4, J5: RJ45_Shielded; GDLX-S-88K
L1: 4.7uH; L_1210_3225Metric
U1: AVR64DD32; TQFP-32_7x7mm_P0.8mm
U2: AP63205WU; TSOT-23-6
U3: SP481E; SOIC-8_3.9x4.9mm_P1.27mm

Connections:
485A: J2.3, J3.3, U3.6 (A)
485B: J2.6, J3.6, U3.7 (B)
+5V: C3.1, C4.1, C5.1, C6.1, C7.1, J1.2 (VCC), L1.2, U1.10 (VDDIO2), U1.18 (VDD), U1.28 (VDD), U2.1 (FB), U3.8 (VCC)
+12V: F1.2, J2.2, J2.4, J2.5, J3.2, J3.4, J3.5, J4.7, J4.8, J5.7, J5.8
BUS_DIR: U1.1 (PA3), U3.2 (~RE), U3.3 (DE)
BUS_RX: U1.31 (PA1), U3.1 (RO)
BUS_TX: U1.30 (EXTCLK/PA0), U3.4 (DI)
GND: C1.1, C3.2, C4.2, C5.2, C6.2, C7.2, J1.6 (GND), J2.1, J2.7, J2.8, J3.1, J3.7, J3.8, J4.1, J4.2, J4.3, J4.SH, J5.1, J5.2, J5.3, J5.SH, U1.19 (GND), U1.29 (GND), U2.4 (GND), U3.5 (GND)
unnamed: J2.SH, J3.SH
unnamed: C2.2, U2.6 (BST)
unnamed: C1.2, F1.1, U2.2 (EN), U2.3 (IN)
unnamed: C2.1, L1.1, U2.5 (SW)
OUT_01: J4.4, U1.7 (PC1)
OUT_02: J4.5, U1.8 (PC2)
OUT_03: J4.6, U1.6 (PC0)
OUT_04: J5.4, U1.15 (PD5)
OUT_05: J5.5, U1.16 (PD6)
OUT_06: J5.6, U1.17 (PD7)
UPDI: J1.1 (DATA), U1.27 (PF7/UPDI)

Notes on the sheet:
PINOUT 1 GND 2 +12V 3 485 A (5V) 4 +12V 5 +12V 6 485 B (5V) 7 GND 8 GND

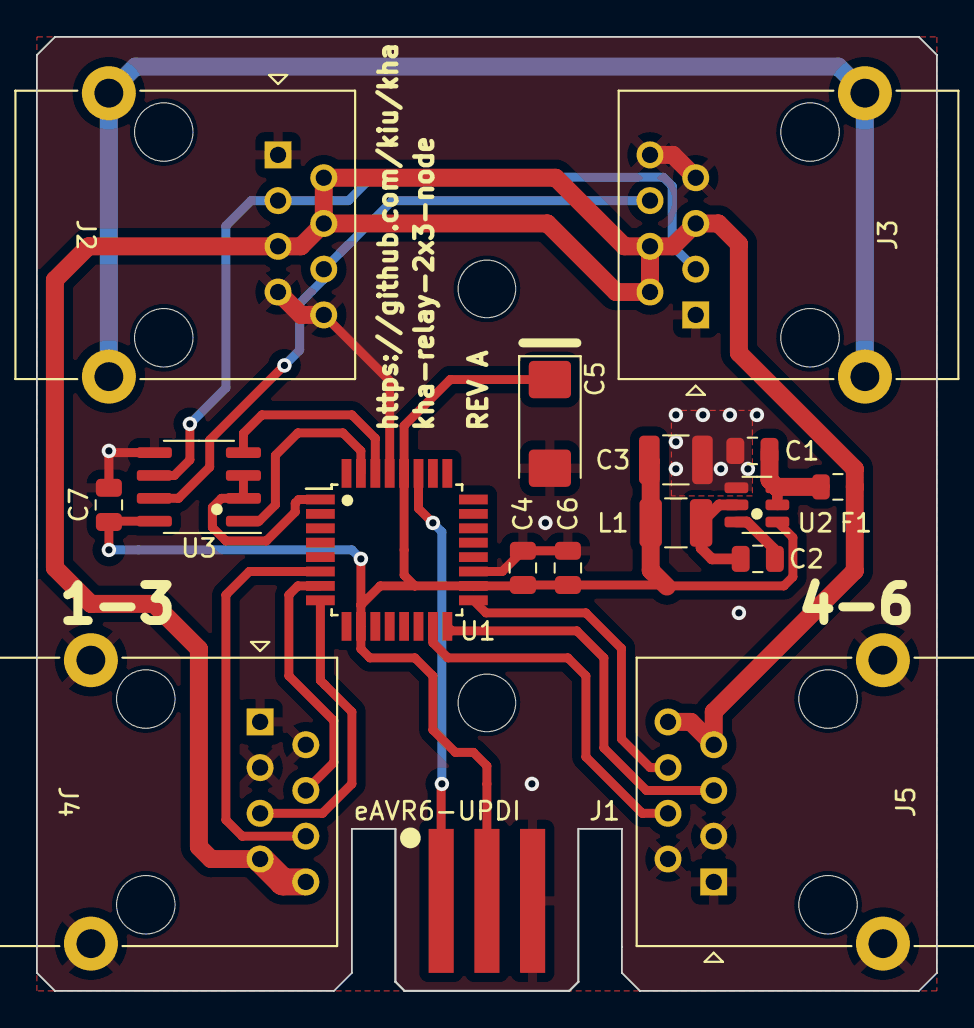
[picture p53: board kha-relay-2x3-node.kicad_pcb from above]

Board: 2 copper layers, 50.0 x 53.0 mm, 19 parts (0 on the bottom side), 19 nets.

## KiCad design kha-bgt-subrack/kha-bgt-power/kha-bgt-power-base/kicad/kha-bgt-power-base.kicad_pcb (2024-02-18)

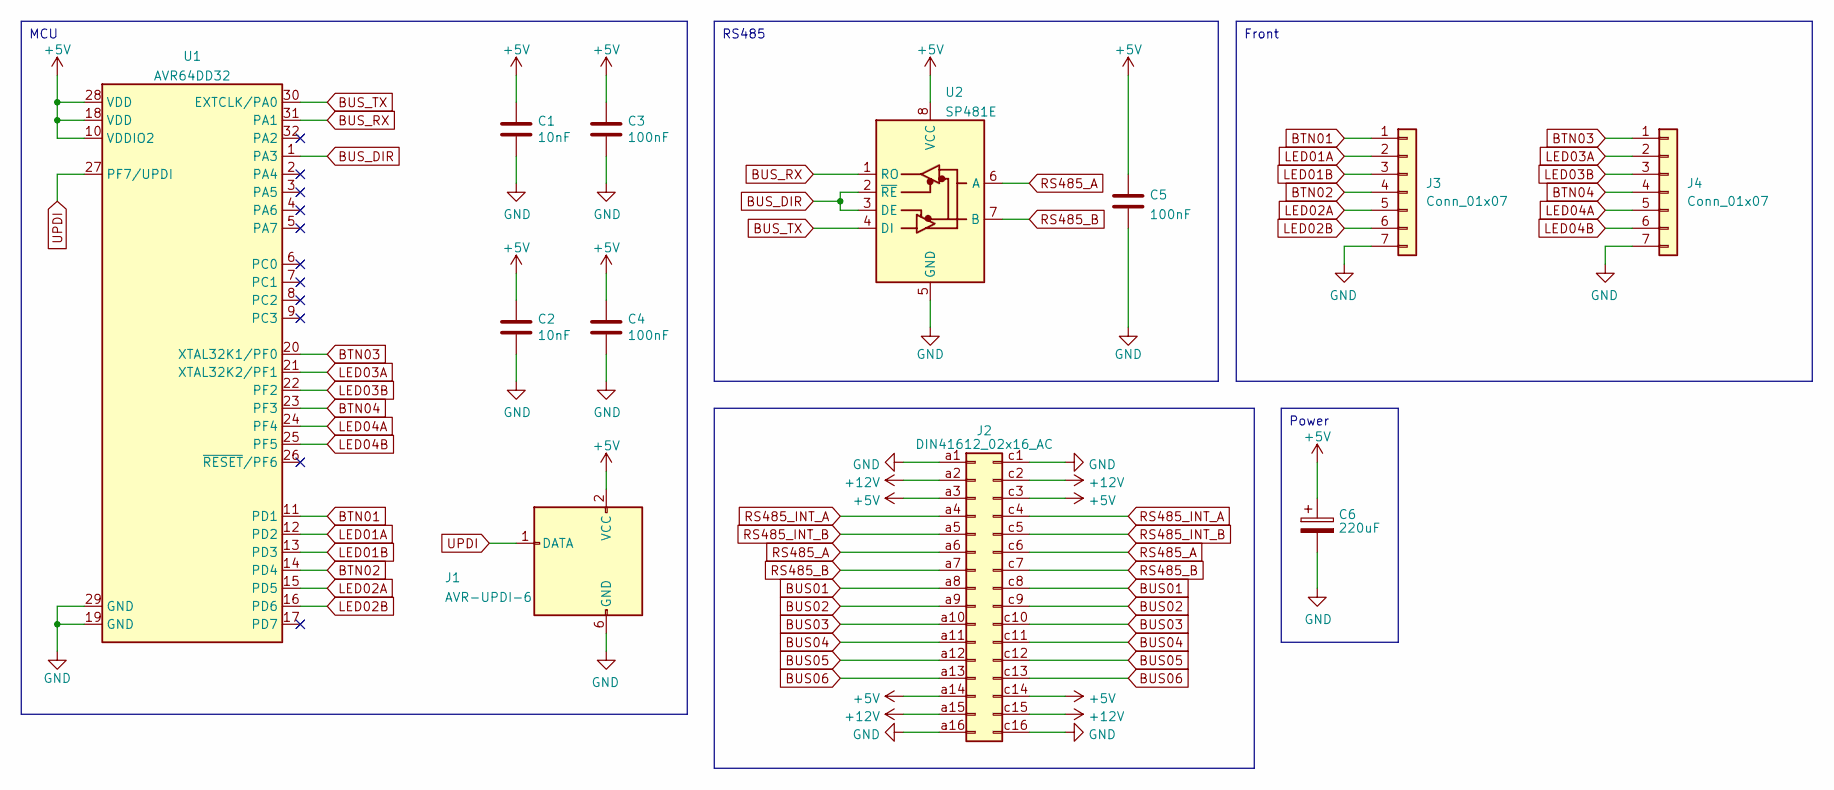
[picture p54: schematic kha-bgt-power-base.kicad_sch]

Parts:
C1, C2: 10nF; C_0805_2012Metric
C3, C4, C5: 100nF; C_0805_2012Metric
C6: 220uF; CP_EIA-6032-28_Kemet-C
J1: AVR-UPDI-6; eAVR6-UPDI-F
J2: DIN41612_02x16_AC; DIN41612_C2_2x16_Male_Horizontal_THT
J3, J4: Conn_01x07; JST_PH_B7B-PH-K_1x07_P2.00mm_Vertical
U1: AVR64DD32; TQFP-32_7x7mm_P0.8mm
U2: SP481E; SOIC-8_3.9x4.9mm_P1.27mm

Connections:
+5V: C1.1, C2.1, C3.1, C4.1, C5.1, C6.1, J1.2 (VCC), J2.a3, J2.a14, J2.c3, J2.c14, U1.10 (VDDIO2), U1.18 (VDD), U1.28 (VDD), U2.8 (VCC)
+12V: J2.a2, J2.a15, J2.c2, J2.c15
BTN01: J3.1, U1.11 (PD1)
BTN02: J3.4, U1.14 (PD4)
BTN03: J4.1, U1.20 (XTAL32K1/PF0)
BTN04: J4.4, U1.23 (PF3)
BT_CON: U1.5 (PA7)
BT_LNK: U1.8 (PC2)
BT_RX: U1.6 (PC0)
BT_TX: U1.7 (PC1)
BUS01: J2.a8, J2.c8
BUS02: J2.a9, J2.c9
BUS03: J2.a10, J2.c10
BUS04: J2.a11, J2.c11
BUS05: J2.a12, J2.c12
BUS06: J2.a13, J2.c13
BUS_DIR: U1.1 (PA3), U2.2 (~RE), U2.3 (DE)
BUS_RX: U1.31 (PA1), U2.1 (RO)
BUS_TX: U1.30 (EXTCLK/PA0), U2.4 (DI)
GND: C1.2, C2.2, C3.2, C4.2, C5.2, C6.2, J1.6 (GND), J2.a1, J2.a16, J2.c1, J2.c16, J3.7, J4.7, U1.19 (GND), U1.29 (GND), U2.5 (GND)
LED01A: J3.2, U1.12 (PD2)
LED01B: J3.3, U1.13 (PD3)
LED02A: J3.5, U1.15 (PD5)
LED02B: J3.6, U1.16 (PD6)
LED03A: J4.2, U1.21 (XTAL32K2/PF1)
LED03B: J4.3, U1.22 (PF2)
LED04A: J4.5, U1.24 (PF4)
LED04B: J4.6, U1.25 (PF5)
RS485_A: J2.a6, J2.c6, U2.6 (A)
RS485_B: J2.a7, J2.c7, U2.7 (B)
RS485_INT_A: J2.a4, J2.c4
RS485_INT_B: J2.a5, J2.c5
SR01: U1.4 (PA6)
SR02: U1.2 (PA4)
SR03: U1.3 (PA5)
S_BT_VCC: U1.9 (PC3)
UPDI: J1.1 (DATA), U1.27 (PF7/UPDI)

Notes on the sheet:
Front
Power
RS485
MCU

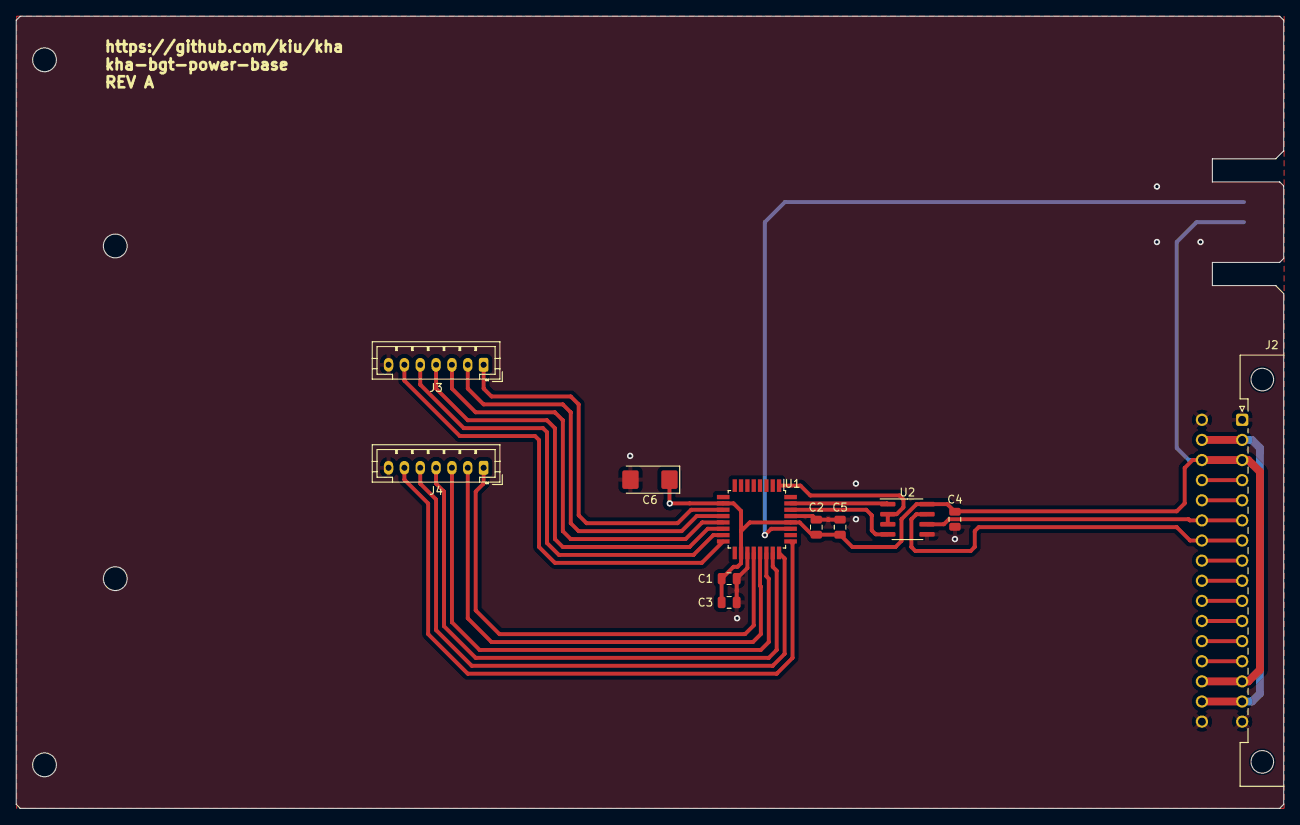
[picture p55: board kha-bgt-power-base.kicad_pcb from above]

Board: 2 copper layers, 160.0 x 100.0 mm, 12 parts (1 on the bottom side), 29 nets.

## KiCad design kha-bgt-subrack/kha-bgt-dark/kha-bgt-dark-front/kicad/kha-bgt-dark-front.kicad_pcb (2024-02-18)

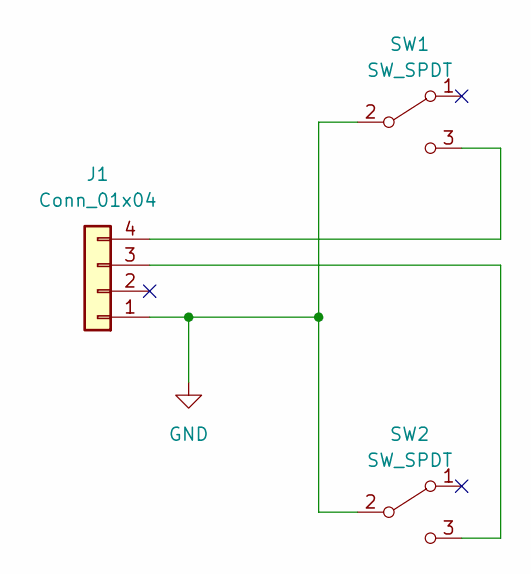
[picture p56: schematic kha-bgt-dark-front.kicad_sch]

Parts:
J1: Conn_01x04; JST_PH_B4B-PH-SM4-TB_1x04-1MP_P2.00mm_Vertical
SW1, SW2: SW_SPDT; PB86

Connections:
GND: J1.1, SW1.2 (B), SW2.2 (B)
unnamed: J1.3, SW2.3 (C)
unnamed: J1.4, SW1.3 (C)

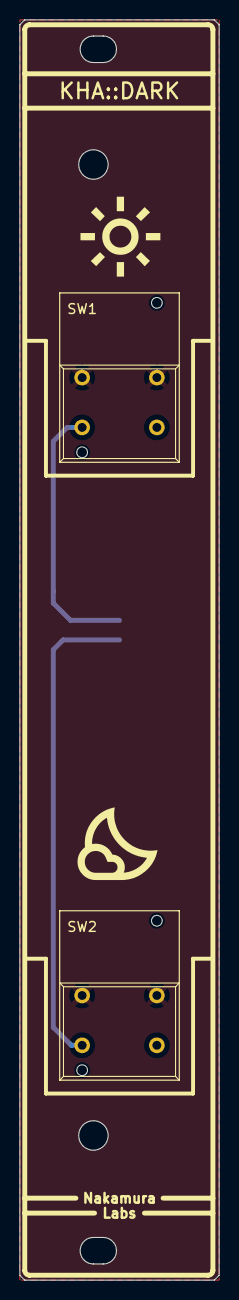
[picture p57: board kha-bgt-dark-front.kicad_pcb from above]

Board: 2 copper layers, 20.3 x 128.5 mm, 3 parts (1 on the bottom side), 3 nets.

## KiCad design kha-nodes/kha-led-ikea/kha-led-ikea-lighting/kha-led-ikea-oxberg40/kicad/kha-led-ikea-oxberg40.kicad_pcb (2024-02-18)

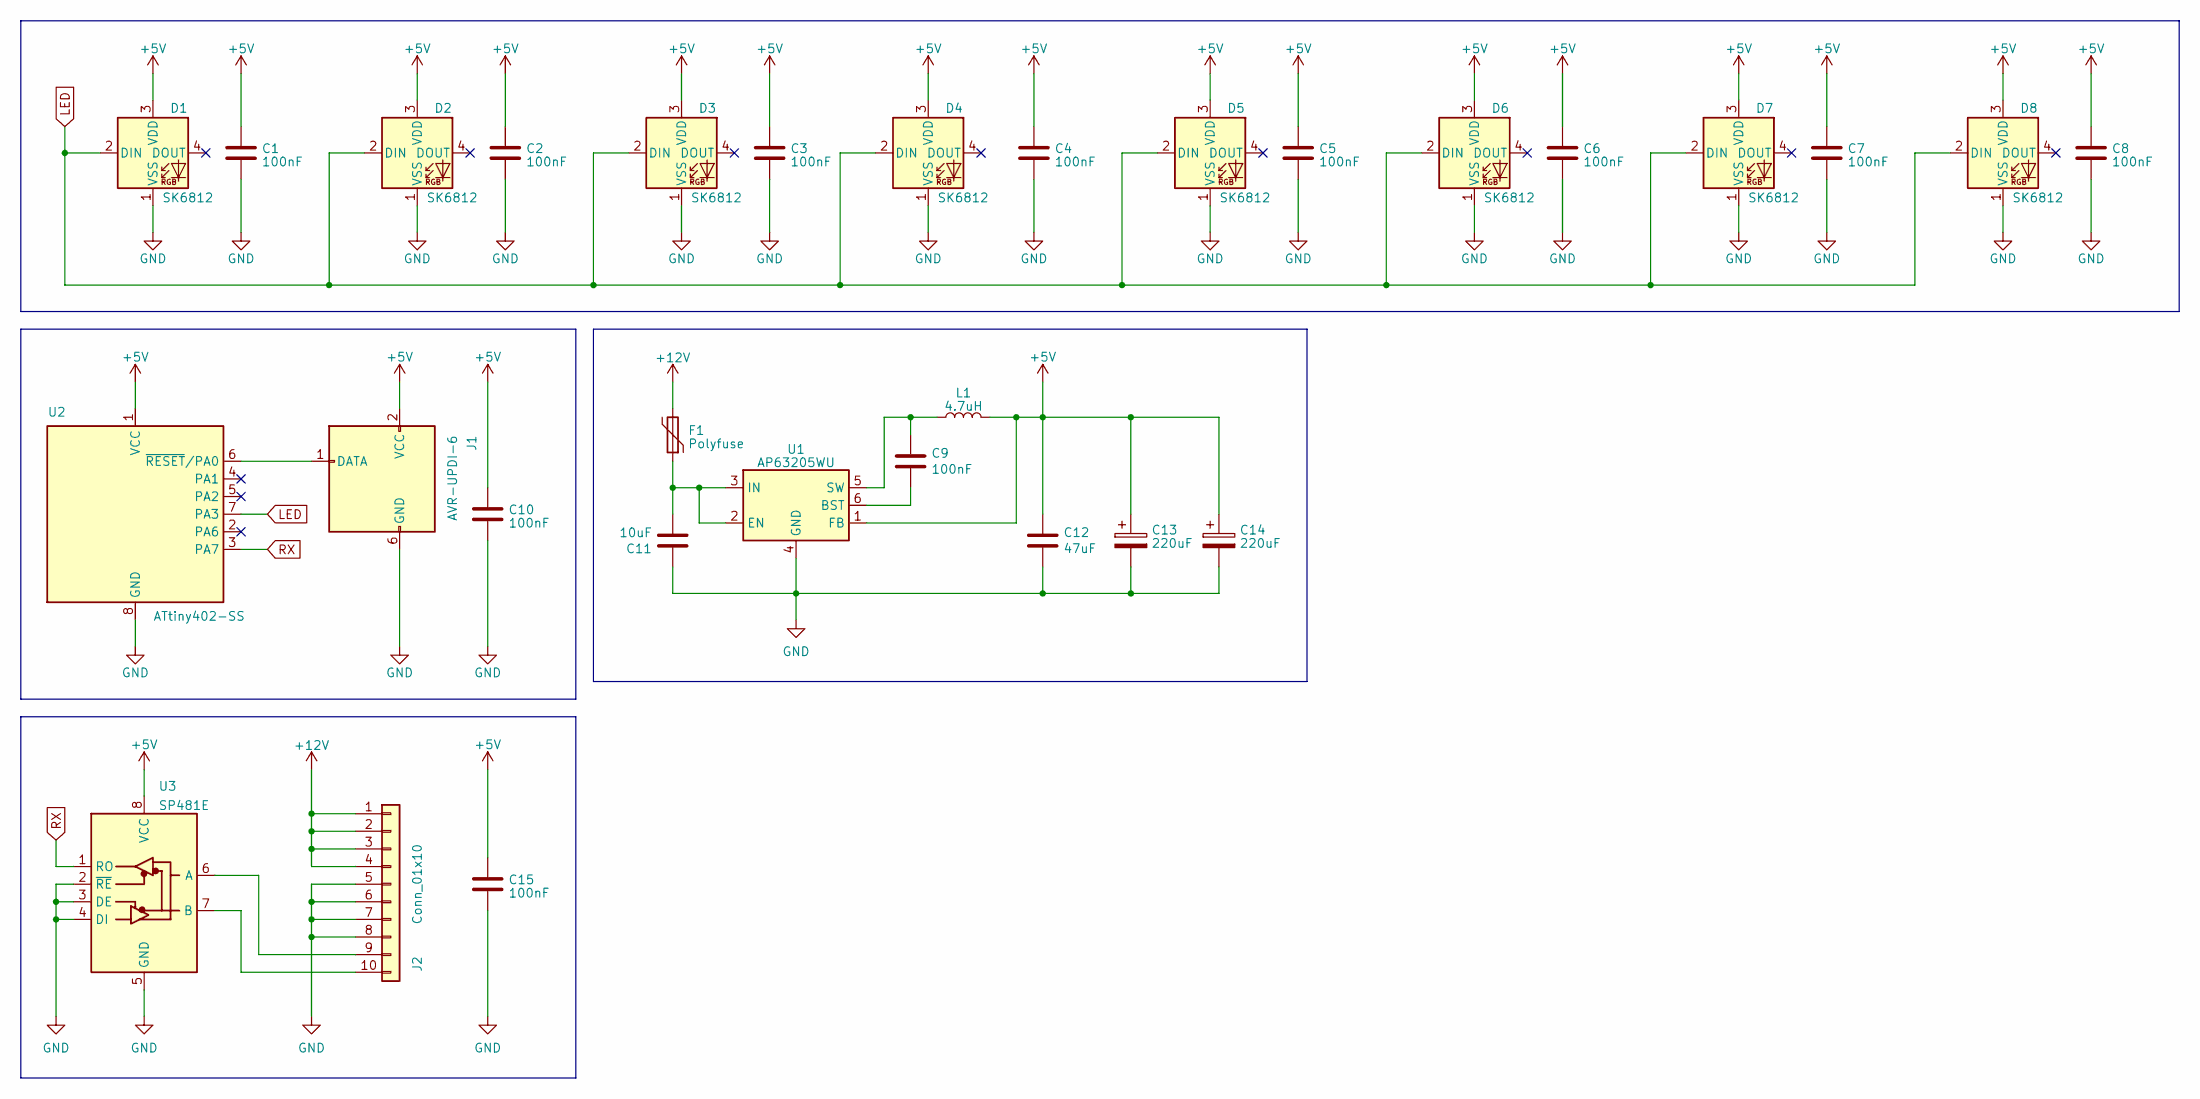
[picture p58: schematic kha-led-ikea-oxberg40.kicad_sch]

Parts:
C1, C2, C3, C4, C5, C6, C7, C8, C9, C10, C15: 100nF; C_0805_2012Metric
C11: 10uF; C_0805_2012Metric
C12: 47uF; C_1210_3225Metric
C13, C14: 220uF; CP_EIA-6032-28_Kemet-C
D1, D2, D3, D4, D5, D6, D7, D8: SK6812; LED_SK6812_PLCC4_5.0x5.0mm_P3.2mm
F1: Polyfuse; Fuse_0805_2012Metric
J1: AVR-UPDI-6; IDC-Header_2x03_P2.54mm_Vertical_SMD
J2: Conn_01x10; IDC-Header_2x05_P2.54mm_Vertical_SMD
L1: 4.7uH; L_1210_3225Metric
U1: AP63205WU; TSOT-23-6
U2: ATtiny402-SS; SOIC-8_3.9x4.9mm_P1.27mm
U3: SP481E; SOIC-8_3.9x4.9mm_P1.27mm

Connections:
+5V: C1.1, C2.1, C3.1, C4.1, C5.1, C6.1, C7.1, C8.1, C10.1, C12.1, C13.1, C14.1, C15.1, D1.3 (VDD), D2.3 (VDD), D3.3 (VDD), D4.3 (VDD), D5.3 (VDD), D6.3 (VDD), D7.3 (VDD), D8.3 (VDD), J1.2 (VCC), L1.2, U1.1 (FB), U2.1 (VCC), U3.8 (VCC)
+12V: F1.2, J2.1, J2.2, J2.3, J2.4
GND: C1.2, C2.2, C3.2, C4.2, C5.2, C6.2, C7.2, C8.2, C10.2, C11.1, C12.2, C13.2, C14.2, C15.2, D1.1 (VSS), D2.1 (VSS), D3.1 (VSS), D4.1 (VSS), D5.1 (VSS), D6.1 (VSS), D7.1 (VSS), D8.1 (VSS), J1.6 (GND), J2.5, J2.6, J2.7, J2.8, U1.4 (GND), U2.8 (GND), U3.2 (~RE), U3.3 (DE), U3.4 (DI), U3.5 (GND)
LED: D1.2 (DIN), D2.2 (DIN), D3.2 (DIN), D4.2 (DIN), D5.2 (DIN), D6.2 (DIN), D7.2 (DIN), D8.2 (DIN), U2.7 (PA3)
unnamed: J1.1 (DATA), U2.6 (~RESET/PA0)
unnamed: J2.9, U3.6 (A)
unnamed: J2.10, U3.7 (B)
unnamed: C9.2, U1.6 (BST)
unnamed: C11.2, F1.1, U1.2 (EN), U1.3 (IN)
unnamed: C9.1, L1.1, U1.5 (SW)
RX: U2.3 (PA7), U3.1 (RO)

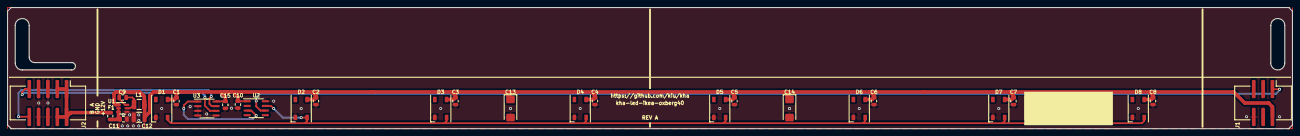
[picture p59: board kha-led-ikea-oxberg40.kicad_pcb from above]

Board: 2 copper layers, 350.0 x 33.0 mm, 30 parts (0 on the bottom side), 11 nets.

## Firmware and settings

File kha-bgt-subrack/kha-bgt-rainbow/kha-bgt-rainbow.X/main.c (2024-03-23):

#include "mcc_generated_files/system/system.h"
#include "mcc_generated_files/timer/delay.h"
#include "mcc_generated_files/timer/tca0.h"
#include "../../../kha-common.X/kha-constants.h"
#include "../../../kha-common.X/kha-stack.h"
#include "../../../kha-nodes/kha-led-strip/kha-led-strip.X/led-generic.h"
#include "../../../kha-nodes/kha-led-ikea/kha-led-const.h"
#include "kha-version.h"

// ---

#define KEY_AMOUNT 3
#define ENC_AMOUNT 2

#define REGISTER_SIZE 1
#define REGISTER_PRESET_WIDTH 3

#define RAINBOW_ADDR_DEST 0x00

// ---

static uint8_t speed = ANIM_S_INIT;
static volatile uint8_t speed_next = ANIM_S_INIT;
static uint8_t width = ANIM_W_INIT;
static volatile uint8_t width_next = ANIM_W_INIT;

static bool enabled = ANIM_E_INIT;
static volatile bool enabled_next = ANIM_E_INIT;

enum BTN_STATE {
    BTN_STATE_RD_OG, BTN_STATE_GN, BTN_STATE_OFF
};
static uint8_t btn_state[1] = {BTN_STATE_RD_OG};

static volatile bool manual_interaction = false;

static const bool enc_overflow[ENC_AMOUNT] = {ANIM_W_OVF, ANIM_S_OVF};
static const uint8_t enc_min[ENC_AMOUNT] = {ANIM_W_MIN, ANIM_S_MIN};
static const uint8_t enc_max[ENC_AMOUNT] = {ANIM_W_MAX, ANIM_S_MAX};
static int8_t enc_last[ENC_AMOUNT];
static volatile int8_t enc_delta[ENC_AMOUNT]; // -128 ... 127

static const uint8_t key_mask = 0b00001111;
static uint8_t key_state[KEY_AMOUNT];
static bool key_down[KEY_AMOUNT];

// ---

uint8_t encoder_verify(uint8_t key, uint8_t value) {
    if (value < enc_min[key]) {
        return enc_min[key];
    }
    if (value > enc_max[key]) {
        return enc_max[key];
    }
    return value;
}

uint8_t encoder_range(uint8_t key, uint8_t current, int8_t diff) {
    int16_t val = current - diff;
    if (!enc_overflow[key]) {
        if (diff > 0 && val < enc_min[key]) {
            return enc_min[key];
        }
        if (diff < 0 && val > enc_max[key]) {
            return enc_max[key];
        }
    } else {
        if (diff > 0 && val < enc_min[key]) {
            return enc_max[key] - (enc_min[key] - val) + 1;
        }
        if (diff < 0 && val > enc_max[key]) {
            return enc_min[key] + (val - enc_max[key]) - 1;
        }
    }
    return val;
}

uint8_t encoder_flip(uint8_t key, uint8_t current) {
    if (current <= enc_min[key]) {
        return enc_max[key];
    }
    if (current >= enc_max[key]) {
        return enc_min[key];
    }

    if (current >= (enc_max[key] - enc_min[key]) / 2) {
        return enc_max[key];
    } else {
        return enc_min[key];
    }
}

void key_pressed(uint8_t key) {
    manual_interaction = true;
    if (key == 2) {
        speed_next = encoder_flip(key - 1, speed_next);
    }
    if (key == 1) {
        width_next = encoder_flip(key - 1, width_next);
    }
    if (key == 0) {
        enabled_next = !enabled_next;
    }
}

void key_tick() {
    key_state[2] = (key_state[2] << 1) | !IO_BTN02P_GetValue();
    key_state[1] = (key_state[1] << 1) | !IO_BTN01P_GetValue();
    key_state[0] = (key_state[0] << 1) | !IO_LED00P_GetValue();

    for (uint8_t i = 0; i < KEY_AMOUNT; i++) {
        uint8_t key_masked = (key_state[i] & key_mask);
        if (!key_down[i] && key_masked == key_mask) {
            key_down[i] = true;
            key_pressed(i);
        }
        if (key_down[i] && key_masked == 0b00000000) {
            key_down[i] = false;
        }
    }
}

// ---

void encoder_tick() {
    int8_t enc_code, enc_diff;
    for (uint8_t key = 0; key < ENC_AMOUNT; key++) {
        enc_code = 0;
        if (key == 1) {
            if (IO_BTN02A_GetValue()) enc_code = 3;
            if (IO_BTN02B_GetValue()) enc_code ^= 1; // convert gray to binary
        } else if (key == 0) {
            if (IO_BTN01A_GetValue()) enc_code = 3;
            if (IO_BTN01B_GetValue()) enc_code ^= 1; // convert gray to binary
        }

        enc_diff = enc_last[key] - enc_code; // difference last - new
        if (enc_diff & 1) { // bit 0 = value (1)
            enc_last[key] = enc_code; // store new as next last
            enc_delta[key] += (enc_diff & 2) - 1; // bit 1 = direction (+/-)
        }
    }
}

void tick() {
    key_tick();
    encoder_tick();
}

// ---

void update_ui() {
    if (!kha_stack_ui_enabled()) {
        IO_LED00A_SetLow();
        IO_LED00B_SetLow();
        return;
    }

    if (btn_state[0] == BTN_STATE_OFF) {
        IO_LED00A_SetLow();
        IO_LED00B_SetLow();
    } else if (btn_state[0] == BTN_STATE_GN) {
        IO_LED00A_SetLow();
        IO_LED00B_SetHigh();
    } else if (btn_state[0] == BTN_STATE_RD_OG) {
        IO_LED00A_SetHigh();
        IO_LED00B_SetLow();
    }
}

void mode_change(bool notify) {
    if (speed != speed_next || width != width_next) {
        enabled_next = true;
    }

    if (speed != speed_next || width != width_next || enabled != enabled_next) {
        speed = speed_next;
        width = width_next;
        enabled = enabled_next;

        if (enabled) {
            btn_state[0] = BTN_STATE_GN;
        } else {
            btn_state[0] = BTN_STATE_RD_OG;
        }
        update_ui();

        if (notify) {
            uint8_t buf3[3] = {speed, width, enabled};
            kha_stack_tx_create(kha_stack_register_get(RAINBOW_ADDR_DEST), KHA_CMD_APP_LED_ANIMATION, 3, buf3);
        }
    }
}

void preset_change(uint8_t preset, bool enabled, uint8_t addr) {
    if (enabled) {
        speed_next = kha_stack_register_get(addr + 0);
        width_next = kha_stack_register_get(addr + 1);
        enabled_next = kha_stack_register_get(addr + 2);
    }
}

uint8_t register_change(uint8_t addr, uint8_t value) {
    if (addr < REGISTER_SIZE) {
        if (addr == RAINBOW_ADDR_DEST) {
        }
    }

    if (addr >= REGISTER_SIZE && REGISTER_PRESET_WIDTH > 0) {
        uint8_t index = addr - REGISTER_SIZE - ((addr - REGISTER_SIZE) / (REGISTER_PRESET_WIDTH + 1) * (REGISTER_PRESET_WIDTH + 1));
        if (index == 0) {
            if (value > 1) {
                value = 0;
            }
        }
        if (index == 1) { // speed
            value = encoder_verify(1, value);
        }
        if (index == 2) { // width
            value = encoder_verify(0, value);
        }
        if (index == 3) {
            if (value > 1) {
                value = 0;
            }
        }
    }

    return value;
}

void led_animation(uint8_t swe[3]) {
    speed = speed_next = encoder_verify(1, swe[0]);
    width = width_next = encoder_verify(0, swe[1]);
    enabled = enabled_next = swe[2];
    update_ui();
}

bool rx_all(uint8_t msg[KHA_MSG_LEN_MAX]) {
    uint8_t size = msg[0];
    //uint8_t from = msg[1];
    uint8_t to = msg[2];
    uint8_t cmd = msg[3];
    uint8_t optlen = size - KHA_MSG_LEN_MIN;

    uint8_t opt[optlen];
    for (uint8_t i = 0; i < optlen; i++) {
        opt[i] = msg[4 + i];
    }

    if (cmd == KHA_CMD_APP_LED_ANIMATION) {
        if (optlen != 3) {
            return false;
        }
        if (to != kha_stack_register_get(RAINBOW_ADDR_DEST)) {
            return false;
        }
        led_animation(opt);
    }

    return false;
}

int main(void) {
    SYSTEM_Initialize();

    speed_next = enc_min[1];
    width_next = enc_min[0];

    sei();

    kha_stack_register_cbr_change(register_change);
    kha_stack_ui_cbr_change(update_ui);
    kha_stack_preset_cbr_change(preset_change);
    kha_stack_app_led_animation_cbr(led_animation);
    kha_stack_rx_cbr_msg_all_post(rx_all);
    kha_stack_init(false, REGISTER_SIZE, REGISTER_PRESET_WIDTH, KHA_VERSION);

    update_ui();

    TCA0_Compare0CallbackRegister(tick);

    while (1) {
        for (uint8_t key = 0; key < ENC_AMOUNT; key++) {
            int8_t diff = enc_delta[key] >> 2;
            if (diff != 0) {
                enc_delta[key] = enc_delta[key] & 3;
                manual_interaction = true;
                enabled_next = true;
                diff = diff * 4;
                if (key == 1) {
                    speed_next = encoder_range(key, speed_next, diff);
                } else if (key == 0) {
                    width_next = encoder_range(key, width_next, diff);
                }
            }
        }

        if (manual_interaction) {
            manual_interaction = false;
            kha_stack_manual_interaction_occured(true, true);
        }

        mode_change(true);

        kha_stack_process_rx_tx();

        asm("wdr");
    }
}

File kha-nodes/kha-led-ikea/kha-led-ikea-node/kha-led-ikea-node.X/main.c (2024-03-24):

#include <string.h>
#include "mcc_generated_files/system/system.h"
#include "mcc_generated_files/timer/delay.h"
#include "../../../../kha-common.X/kha-constants.h"
#include "../../../../kha-common.X/kha-stack.h"
#include "../../kha-led-const.h"
#include "../../../kha-led-strip/kha-led-strip.X/led-generic.h"
#include "kha-version.h"
#include "main.h"

// ---

#define REGISTER_SIZE 6
#define REGISTER_PRESET_WIDTH 0

#define IKEA_NODE_HARDWARE_OXBERG 2
#define IKEA_NODE_HARDWARE_KALLAX 1
#define IKEA_NODE_HARDWARE_NONE 0

#define LAYOUT_ORIENTATION_NONE 0x0
#define LAYOUT_ORIENTATION_VERTICAL 0x01
#define LAYOUT_ORIENTATION_HORIZONTAL 0x02

// ---

static uint8_t layout_orientation = LAYOUT_ORIENTATION_NONE;
static uint8_t layout_amount = 0;
static uint8_t layout_low_amount = 0;
static uint8_t layout_location = 0;

static uint8_t mode = IKEA_SELECTION_INIT;
static volatile uint8_t mode_next = IKEA_SELECTION_OFF;

static volatile bool hsi_changed = false;
static volatile uint8_t hsi_h_net = HSI_H_INIT;
static uint8_t hsi_s_net = HSI_S_INIT;
static uint8_t hsi_i_net = HSI_I_INIT;

static uint8_t volatile anim_tick_count = 0;
static volatile bool anim_e = ANIM_E_INIT;
static volatile uint8_t anim_s = (0xFF - ANIM_S_INIT);
static volatile uint8_t anim_w = ANIM_W_INIT;

// ---

void send_rx4_raw(uint8_t data) {
    while (!USART1_IsTxReady()) {
    }
    USART1_Write(data);
}

void send_rx4(uint8_t addr, uint8_t cmd, uint8_t optlen, uint8_t* opt) {
    // Raw:      0x42 0x23 <----------- payload ------------>
    // Encoded:  0x42 0x23 <len> <addr> <cmd> <options> <crc>
    // Decoded:  0x42      <len> <addr> <cmd> <options> <crc>
    // Buffer:                   <addr> <cmd> <options> <crc>

    uint8_t txlen = optlen + 4; // len + addr + cmd + 4 opt + crc
    uint8_t tx[txlen];

    tx[0] = txlen;
    tx[1] = addr;
    tx[2] = cmd;
    memcpy(tx + 3, opt, optlen);
    tx[3 + optlen] = kha_stack_crc8(tx, txlen - 2);

    while (!USART1_IsTxDone()) {
    }

    send_rx4_raw(KHA_LED_MSG_START);
    send_rx4_raw(KHA_LED_MSG_START_CONFIRM);
    for (uint8_t i = 0; i < txlen; i++) {
        send_rx4_raw(tx[i]);
        if (tx[i] == KHA_LED_MSG_START) {
            send_rx4_raw(KHA_LED_MSG_START_ESCAPE);
        }
    }
}

void send_rx4_hsi(uint8_t addr, uint8_t h, uint8_t s, uint8_t i) {
    uint8_t buf3[3];
    buf3[0] = h;
    buf3[1] = s;
    buf3[2] = i;
    send_rx4(addr, KHA_LED_CMD_SET_HSI, 3, buf3);
}

void send_rx4_ident() {
    send_rx4(KHA_LED_ADDR_BROADCAST, KHA_LED_CMD_IDENT, 0, NULL);
}

// ---

void update_led() {
    if (mode == IKEA_SELECTION_OFF) {
        return;
    }

    if (layout_orientation == LAYOUT_ORIENTATION_NONE) {
        return;
    }

    if (layout_amount == 0) {
        return;
    }

    if (!anim_e) {
        if (layout_orientation != LAYOUT_ORIENTATION_VERTICAL) {
            send_rx4_hsi(KHA_LED_ADDR_BROADCAST, hsi_h_net, hsi_s_net, hsi_i_net);
            return;
        }

        if (mode == IKEA_SELECTION_LOW) {
            for (uint8_t i = 0; i < layout_amount; i++) {
                if (i < layout_low_amount) {
                    send_rx4_hsi(i + 1, hsi_h_net, hsi_s_net, hsi_i_net);
                } else {
                    send_rx4_hsi(i + 1, hsi_h_net, hsi_s_net, 0x00);
                }
            }
        }

        if (mode == IKEA_SELECTION_GRADIENT) {
            float fraction = hsi_i_net / (float) (layout_amount + 1);
            for (uint8_t i = 0; i < layout_amount; i++) {
                send_rx4_hsi(i + 1, hsi_h_net, hsi_s_net, fraction * (layout_amount - i));
            }
        }

        if (mode == IKEA_SELECTION_FULL) {
            send_rx4_hsi(KHA_LED_ADDR_BROADCAST, hsi_h_net, hsi_s_net, hsi_i_net);
        }
    }

    if (anim_e) {        
        float step = (float)anim_w / 6.0;
        
        if (mode == IKEA_SELECTION_LOW) {
            if (layout_orientation == LAYOUT_ORIENTATION_HORIZONTAL && layout_amount > 1) {
                for (uint8_t i = 0; i < layout_amount; i++) {
                    send_rx4_hsi(i + 1, hsi_h_net + ((layout_location + i) * step), hsi_s_net, hsi_i_net);
                }
            } else {
                for (uint8_t i = 0; i < layout_amount; i++) {
                    if (i < layout_low_amount) {
                        send_rx4_hsi(i + 1, hsi_h_net + (layout_location * step), hsi_s_net, hsi_i_net);
                    } else {
                        send_rx4_hsi(i + 1, hsi_h_net + (layout_location * step), hsi_s_net, 0x00);
                    }
                }
            }
        }

        if (mode == IKEA_SELECTION_GRADIENT) {
            float fraction = hsi_i_net / (float) (layout_amount + 1);
            if (layout_orientation == LAYOUT_ORIENTATION_HORIZONTAL && layout_amount > 1) {
                for (uint8_t i = 0; i < layout_amount; i++) {
                    send_rx4_hsi(i + 1, hsi_h_net + ((layout_location + i) * step), hsi_s_net, fraction * (layout_amount - i));
                }
            } else {
                for (uint8_t i = 0; i < layout_amount; i++) {
                    send_rx4_hsi(i + 1, hsi_h_net + (layout_location * step), hsi_s_net, fraction * (layout_amount - i));
                }
            }
        }

        if (mode == IKEA_SELECTION_FULL) {
            if (layout_orientation == LAYOUT_ORIENTATION_HORIZONTAL && layout_amount > 1) {
                for (uint8_t i = 0; i < layout_amount; i++) {
                    send_rx4_hsi(i + 1, hsi_h_net + ((layout_location + i) * step), hsi_s_net, hsi_i_net);
                }
            } else {
                send_rx4_hsi(KHA_LED_ADDR_BROADCAST, hsi_h_net + (layout_location * step), hsi_s_net, hsi_i_net);
            }
        }
    }
}

void hsi_set(uint8_t hsi[3]) {
    hsi_h_net = hsi[0];
    hsi_s_net = hsi[1];
    hsi_i_net = hsi[2];
    hsi_changed = true;
}

void anim_tick() {
    if (mode == IKEA_SELECTION_OFF) {
        return;
    }
    if (hsi_s_net == 0x00) {
        return;
    }
    if (hsi_i_net == 0x00) {
        return;
    }

    anim_tick_count++;
    if (anim_tick_count >= anim_s) {
        anim_tick_count = 0;
        hsi_h_net++;
        hsi_changed = true;
    }
}

void anim_set(uint8_t swe[3]) {
    uint8_t tmp;

    tmp = swe[0];
    if (tmp < ANIM_S_MIN) {
        tmp = ANIM_S_MIN;
    }
    if (tmp > ANIM_S_MAX) {
        tmp = ANIM_S_MAX;
    }
    anim_s = 0xFF - tmp;

    tmp = swe[1];
    if (tmp < ANIM_W_MIN) {
        tmp = ANIM_W_MIN;
    }
    if (tmp > ANIM_W_MAX) {
        tmp = ANIM_W_MAX;
    }
    anim_w = tmp;

    tmp = swe[2];
    if (tmp > 1) {
        tmp = 0;
    }
    anim_e = tmp;
    if (anim_e) {
        TCA0_Compare0CallbackRegister(anim_tick);
    } else {
        TCA0_Compare0CallbackRegister(NULL);
    }

    hsi_changed = true;
}

// ---

void led_on() {
    if (!IO_PD6_GetValue()) {
        IO_PD6_SetHigh();
        DELAY_milliseconds(300);
    }
}
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

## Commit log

2026-10-30 kha-stack: TX slots on TCB2, 100 µs ticks
    - TCB2 is reserved by the stack and ticks every 100 µs (was the RTC PIT, 244 µs on the 32 kHz
    oscillator)
    - a node may send after 10 + device address ticks without a falling edge on RX (was exactly
    2 x address ticks, wrapping every 480 ticks)
    - after sending, wait the longest slot once so the others get a turn; cleared as soon as another node
    transmits
    - an FFE5 stats storm with 22 replies takes ~280 ms instead of ~1950 ms
2026-10-30 kha-stack: atomic slot reset, RX during slot wait, 16 presets, ID checks
    - reset the 16-bit slot counter with interrupts off, the TCB2 ISR increments it
    - keep processing RX while waiting for the TX slot, so the UART buffer can't overflow while others talk
    - memmove instead of memcpy in the TX queue, source and destination overlap
    - reserve EEPROM for all 16 presets (0..KHA_PRESET_MAX), preset 15 lay outside; presets 0-14 keep
    their addresses
    - register length as 16 bit, the sum could overflow
    - board type outside MIN..MAX falls back (the check used && and never matched)
    - reject 0xF0 (group fallback) as device address
2026-11-01 kha-stack: CRC over the whole frame and app flash, UART error counters, 11-byte stats
    - Frame CRC-8 now covers every byte before the CRC (len - 1); the last byte was unprotected.
    Breaking: old and new stacks reject each other's frames.
    - App flash CRC-32 covers 0x4000..0xFFFF (was ..0xFFFE); kha_fw.py computes the same range.
    - New stats counters: UART framing error, UART overrun, RX buffer full. The stats response
    has 11 counters, indices KHA_STATS_* in kha-constants.h.
    - kha-led-ikea-node: note that the light link CRC keeps len - 2 on purpose (subboards).
2026-11-01 kha-boot: 4 s countdown that keeps processing RX, BOD at 2.85 V, no lock bits
    - Countdown 4 s (was 6 s), RX is processed every 1 ms during it.
    - Brown-out detection at 2.85 V (BODCFG, set by hand in config_bits.c).
    - Lock bits stay at NOLOCK, so UPDI can read a node.
    - Explicit cast for the jump to the app.
2026-11-01 kha-led-strip: APA102 on SPI mode 0, register 02 = 02 for swapped clock/data
    - APA102 samples on the rising clock edge: open SPI config 1 (mode 0, clock /32) instead of
    config 0 (mode 1, clock /128).
    - Register 02 = 02 sends APA102 bit-banged with clock and data swapped (clock on LED_DAT,
    data on LED_CLK), for strips wired the other way round.
2026-11-01 kha-main, kha-bgt-main: 8-bit blink counter instead of a 32-bit modulo in the timer ISR
    "tick % 100" on a uint32_t in the 10 ms TCA0 callback pulled in __udivmodsi4 (~30 us inside
    an interrupt). At 500 kbaud the USART holds only two bytes, so the bus RX interrupt came too
    late and the UART overran now and then.
2026-11-01 kha-gateway-usb: parse host commands in the main loop, buffered host output
    - The host UART RX interrupt only copies bytes into a 512-byte ring; lines are parsed and
    sent from the main loop. Before, parsing, kha_stack_tx_create() and error printfs ran
    inside the interrupt, raced the TX queue and could overrun the bus UART.
    - printf writes into a 1 KB ring drained by the DRE interrupt, so printing no longer
    stalls the main loop for every character.
2026-11-01 bridges: kha_serial_log survives a closed reply socket, kha_listen reaps ssh children
    - kha_serial_log.py: ignore ConnectionResetError on UDP receive (Windows reports a reply to
    a closed sender socket there), which used to kill the command thread.
    - kha_listen.py: ignore SIGCHLD so finished ssh children of run_cmd() don't stay defunct;
    "\\\\" escapes in the shutdown commands (same strings, no SyntaxWarning).
2026-11-01 kha_updi.py: flash bootloader + app via UPDI and restore the registers
    For a new chip, a node without a working bootloader or one that can't be flashed over the
    bus (Atmel-ICE, pymcuprog). Identifies the node (USERROW, its UP on the bus), chip erase,
    writes the merged bootloader + app image, the bootloader's fuses and the EEPROM image from
    inventory/, each verified, then checks the app CRC the node reports. Firmware from the
    dist/ builds or --firmware <dir>.
2026-11-01 kha-protocol: 11-byte stats response, Write Fail is D8, led-strip mode 2, TCB2 for the stack
    - CMD: E6 Stats Response has 11 counters, listed; Write Fail is D8 (was listed as E8).
    - REGISTER: led-strip register 02 = 2, APA102 with clock/data swapped.
    - REGISTER SETUP: led strip desk has 103 LEDs (0x67).
    - MPLab MCC Build: TCB2 is used by the stack (slot ticks) instead of the RTC.
2026-11-01 builds: all firmware rebuilt with the current source
    dist/ and kha-version.h of the bootloader and every app, matching the source above; these
    are the builds running on the nodes.
2026-11-01 README: protocol section (frame, bus access, firmware)
    Frame format with escaping and CRC-8, slot-based bus access on TCB2, flash layout, app CRC
    and bootloader behaviour.
2026-11-01 kha-web: bus health page with a passive collector
    - webroot/: static page (bus map, node detail, counters, firmware
    comparison, reboot age, missing / not polled, data-age banner)
    - kha_collector.py: follows the gateway log (human or proto format),
    keeps the state in SQLite, resumes across log rotation, exports
    nodes.json only on change; optional one ident broadcast at startup
    (at most once per hour)
    - kha_mock.py: mock data with every state (page: ?mock)
    - config.json: node names, places and cable order
    - kha_collector.service: systemd unit template
    - README: bus health page section with a screenshot
    - .gitignore: collector database, generated page data, __pycache__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
